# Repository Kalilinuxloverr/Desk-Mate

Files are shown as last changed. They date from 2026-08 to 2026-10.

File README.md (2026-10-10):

<p align="center">Desk-Mate Logo</p>

# Desk-Mate

Ein kleiner Wall-E-artiger Schreibtisch-Begleiter: eine Ampel für alles, was dich braucht (Claude Code, Browser-Downloads, Steam), ein Deck mit Motorfadern und Soft-Keys, ein Kopf mit zwei Augen-Displays. Verbunden per USB, BLE und WiFi; steuerbar vom Mac, vom Handy und über das Haus-MQTT. Alles Through-Hole, alles 3D-gedruckt, alles dokumentiert — inklusive Arbeitszeit.

**Zwischenstand (2026-10-09):**

| Schritt | Stand |
|---|---|
| Design-Spec (18 Grill-Fragen) | ✅ [`docs/superpowers/specs/`](docs/superpowers/specs/2026-08-22-desk-mate-design.md) |
| Pin-Map gegen Datenblatt + DevKit-Schaltplan verifiziert | ✅ [`firmware/arduino/deskmate/pins.h`](firmware/arduino/deskmate/pins.h) |
| Stückliste mit Quellen und Preisen, Teile bestellt (Amazon ~142 €) | ✅ [`hardware/bom.md`](hardware/bom.md) |
| KiCad final: Mainboard 100×100 · Frontpanel 120×136 · Augen-Adapter 42×30 — nur THT, Teile von Reichelt, Silkscreen mit Logo und Pin-Namen, ERC/DRC sauber, Gerber exportiert | ✅ [`hardware/kicad/`](hardware/kicad/README.md) |
| Bestellung Reichelt + JLCPCB | 🔜 bereit — Gerber in `hardware/kicad/<board>/fab/`, Liste in [`vault/Bestellungen/2026-10-09-reichelt.md`](vault/Bestellungen/2026-10-09-reichelt.md) |
| Firmware · Agent/App · Gehäuse | ⬜ danach |

Arbeitszeit und Tagesprotokolle: [`vault/Log/`](vault/Log/) · Projektseite: Portfolio-Eintrag P12.

```
 ┌─────────────────────┐
 │ KOPF  (pan/tilt)    │  Augen-Adapter-PCB → 2× GC9A01 (rund, 1,28")
 │                     │  WS2812-Ring (Ampel) · 2× MG90S im Hals
 ├─────────────────────┤
 │ BAUCH / DECK        │  FRONTPANEL-PCB
 │  [ 2,8" ILI9341 ]   │   6 Soft-Keys unter dem Display
 │  [k][k][k][k][k][k] │   4 Makro-Keys · EC11-Encoder
 │  |F| [k][k] (o) |F| │   2(4)× X32-Motorfader · MCP23017 · MPR121
 │  |F|  [k][k]    |F| │
 ├─────────────────────┤
 │ BASE (statisch)     │  MAINBOARD-PCB
 │  USB-C(D) USB-C(P)  │   ESP32-S3 DevKitC-1 · 2× USB-C · LD1117V33
 │  BME680             │   2(4)× DRV8833 · VM-Boost optional
 └─────────────────────┘
          │ USB / BLE / WiFi-MQTT
   ┌──────┴──────┐      ┌──────────┐      ┌────────────┐
   │ macOS-Agent │◄────►│ iOS-App  │      │ Claude Code│──Hooks──► Agent
   │ (Menüleiste)│ MQTT │          │      └────────────┘
   └─────────────┘      └──────────┘
```

| Pfad | Inhalt |
|---|---|
| `docs/superpowers/specs/` | Design-Spec (die eine Wahrheit für Hardware, Pin-Map, Protokolle) |
| `docs/superpowers/plans/` | Implementierungspläne je Phase |
| `docs/relic/` | Der Ursprungs-Prompt, unverändert |
| [`docs/anleitung/`](docs/anleitung/) | Bauanleitung (wächst mit dem Projekt) |
| `docs/logo/` | Logo (SVG) |
| `vault/` | Obsidian-Vault: Tagesblätter mit Arbeitszeit, Entscheidungen, Bestellungen |
| `hardware/kicad/` | Mainboard, Frontpanel, Augen-Adapter (KiCad 10) |
| `hardware/3d/` | Gehäuse (STEP + STL) |
| `hardware/bom.md` | Stückliste |
| `firmware/arduino/deskmate/` | ESP32-S3-Firmware (arduino-cli) |
| `app/` | macOS-Agent + iOS-App (Swift, XcodeGen) |
| `agent-windows/` | Windows-Tray (Python, Phase 2) |
| `server/` | Vercel-Function für Push |
| `tools/` | Session-Hooks, Secret-Check |

## Hardware

| Mainboard (Base) | Frontpanel (Deck) | Augen-Adapter |
|---|---|---|
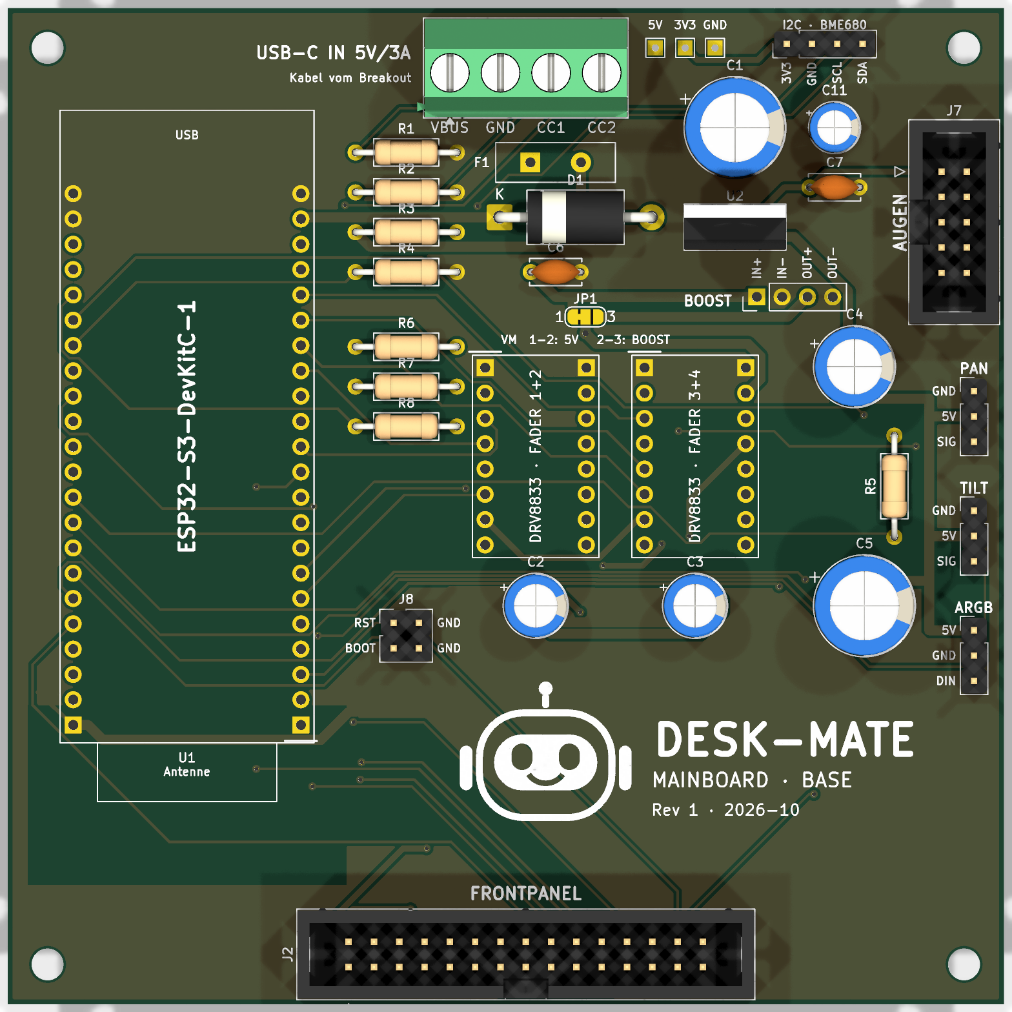
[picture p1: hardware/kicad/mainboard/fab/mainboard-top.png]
Mainboard
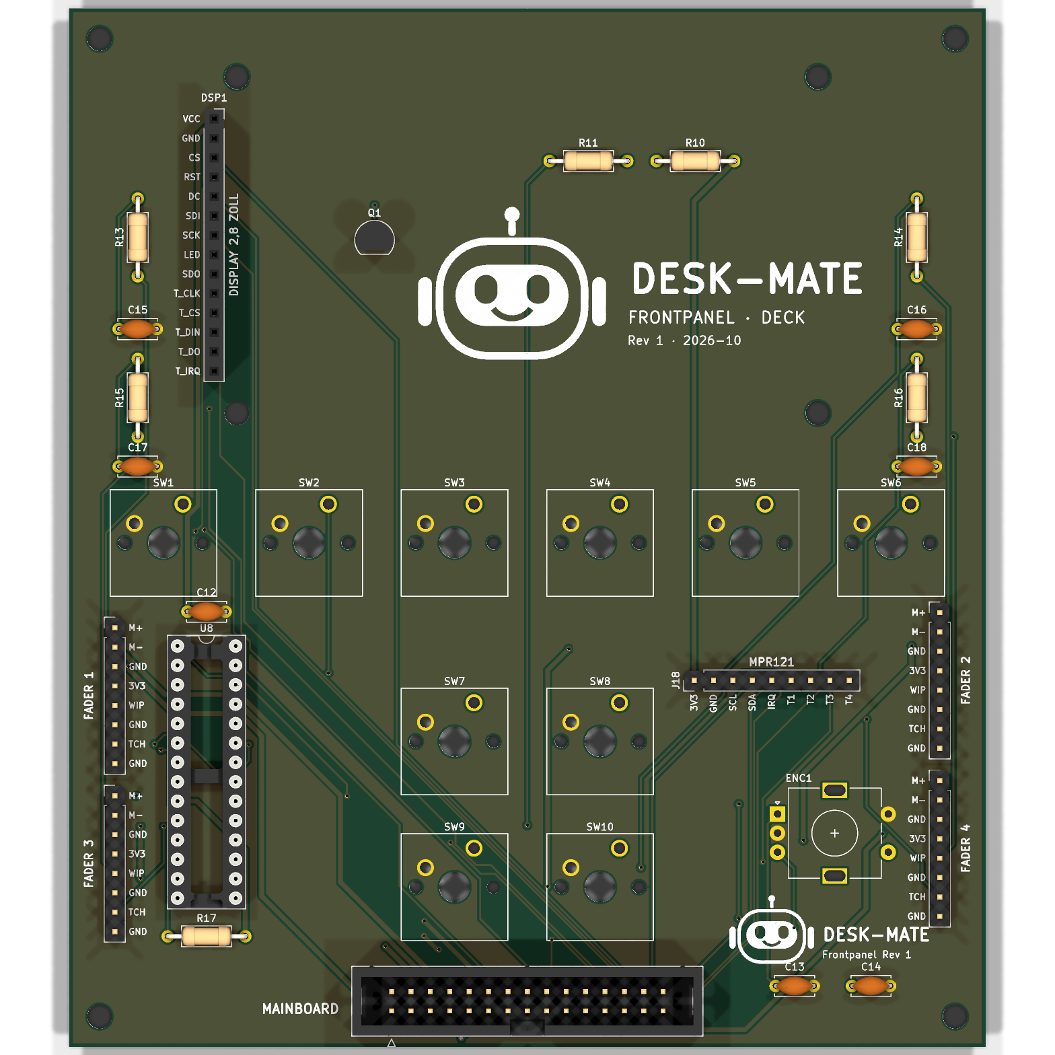
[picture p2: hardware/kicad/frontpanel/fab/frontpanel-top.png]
Frontpanel
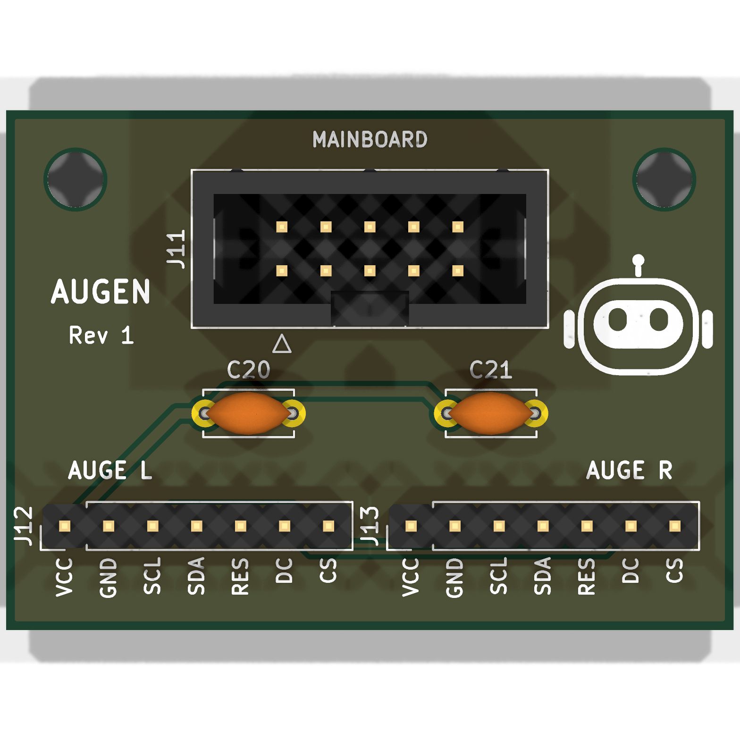
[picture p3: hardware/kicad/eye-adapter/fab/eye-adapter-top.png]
Augen-Adapter
|  |  |  |

Drei Through-Hole-Platinen, alle Module gesteckt (ESP32-S3-DevKitC-1, Pololu DRV8833, MPR121, Displays). Schaltpläne als PDF, STEP-Modelle und JLCPCB-Gerber-Zips liegen in `hardware/kicad/<board>/fab/`; Aufbau und Entwurfsregeln in [`hardware/kicad/README.md`](hardware/kicad/README.md), Bestellanleitung in [`docs/anleitung/01-platinen.md`](docs/anleitung/01-platinen.md).

## Bauen

Nach dem Klonen einmalig:

```bash
git config core.hooksPath tools/githooks   # Secret-Check vor jedem Commit
sh tools/test-check-secrets.sh             # muss "OK" sagen
sh tools/test-session-hooks.sh             # muss "OK" sagen
sh tools/test-pins.sh                      # Pin-Map-Regeln
sh tools/test-kicad.sh                     # ERC + DRC + Netzliste (braucht KiCad 10 unter /Applications)
```

KiCad-Dateien neu erzeugen/exportieren: siehe [`hardware/kicad/README.md`](hardware/kicad/README.md). Firmware- und App-Befehle kommen mit den jeweiligen Phasen dazu (siehe `CLAUDE.md`).

## Lizenz

MIT (Code). Lizenz für die Hardware-Dateien wird noch festgelegt.

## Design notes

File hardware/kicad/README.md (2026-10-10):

# KiCad — drei Platinen, eine JLCPCB-Bestellung

| Ordner | Platine | Maß | Inhalt |
|---|---|---|---|
| `mainboard/` | Base | 100 × 100 mm | S3-DevKit-Sockel, Schraubklemme für das USB-C-Breakout (5 V/3 A), Polyfuse + SB540, LD1117V33, 2× DRV8833-Sockel, Servo/ARGB/I²C-Stiftleisten, Augen-Kabel IDC 2×5, IDC 2×15, MT3608-Header (VM-Boost, optional) |
| `frontpanel/` | Deck | 120 × 136 mm | 10× MX, EC11, MCP23017, MPR121-Stiftleiste (Modul per Kabel), ILI9341-Sockel + 4 Abstandshalter, 4× Fader-Header, Backlight-Schalter, IDC 2×15 |
| `eye-adapter/` | Kopf | 42 × 30 mm | IDC 2×5 ein, 2× 1×7-Stiftleiste für die GC9A01 (per Dupont-Kabel) |
| `lib/` | — | — | Projektbibliothek `deskmate.kicad_sym` + `deskmate.pretty` (Modul-Sockel, Polyfuse) |
| `gen/` | — | — | Generator (siehe unten) |
| `<board>/fab/` | — | — | Gerber/Drill-Zip, STEP, Render — das geht zu JLCPCB |

Regeln (JLCPCB 2-Lagen): Leiterbahn ≥ 0,2 mm, Abstand ≥ 0,127 mm, Via 0,8/0,4 mm, Rand 0,3 mm. Netzklassen (Breite / Abstand 0,13): Default 0,25, Power 1,0 (Mainboard) bzw. 0,8 (Frontpanel), Motor 0,6, Power3V3 0,6 — Werte stehen in `gen/boards.py` und `gen/build_sch.py`. Massefläche beidseitig, Sperrzone unter der DevKit-Antenne.

## Generator statt Handarbeit (Erstversion)

Die Erstversion aller Dateien wurde aus `gen/boards.py` erzeugt — eine Tabelle „Bauteil → Pin → Netz → Position“. So sind Schaltplan, Layout und `netlist.json` per Konstruktion identisch, und `tools/test-kicad.sh` prüft das gegen KiCads eigene Netzliste.

```bash
cd hardware/kicad/gen
python3 build_sch.py                       # Bibliothek, Schaltpläne, Projekte, netlist.json
KIPY=/Applications/KiCad/KiCad.app/Contents/Frameworks/Python.framework/Versions/3.9/bin/python3
$KIPY build_pcb.py mainboard --force       # Layout platzieren, Freerouting, Zonen füllen
$KIPY export_fab.py mainboard              # Gerber/Drill/STEP/Render nach mainboard/fab/
sh ../../../tools/test-kicad.sh            # ERC + DRC + Netzlisten-Abgleich
```

`build_pcb.py` routet bis zu 6-mal mit wechselnder Strategie und behält den ersten Lauf mit 0 offenen Verbindungen; GND-Pads sind vollflächig an die Massefläche angebunden (beim Löten heißer/länger). Freerouting: `~/Applications/freerouting-2.3.0.jar` (Java 17+; `curl -L -o ~/Applications/freerouting-2.3.0.jar https://github.com/freerouting/freerouting/releases/download/v2.3.0/freerouting-2.3.0.jar`).

**Wichtig:** Sobald in der KiCad-GUI etwas geändert wurde, sind die `.kicad_sch`/`.kicad_pcb` die Wahrheit — `build_*.py` nicht mehr blind laufen lassen (`build_pcb.py` weigert sich ohne `--force`). Der Generator ist ein Bootstrap, kein Roundtrip.

Der Schaltplan ist „Label-Stil“: jedes Pin trägt ein globales Label, keine Leitungen. Elektrisch vollständig, optisch schlicht — in der GUI beliebig umsortierbar.

## Was vor der Bestellung am echten Teil zu prüfen ist

Siehe `vault/Hardware/Module-Masse.md` (Quellen + Konfidenz). Kurz: DevKit-Reihenabstand 22,86 (hoch), Pololu-Raster 10,16 (hoch), MPR121-Clone 17,78 (mittel — nachmessen), ILI9341 MSP2807-Löcher (hoch), X32-Fader-Pins (unbekannt — Drähte an Stiftleiste).

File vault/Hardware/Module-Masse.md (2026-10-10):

---
datum: 2026-08-27
typ: hardware
---
# Modul-Maße für die Sockel-Footprints (Recherche 27.08.2026)

Was der Generator (`hardware/kicad/gen/boards.py`) annimmt, woher es kommt, wie sicher es ist. **Alles mit „mittel/niedrig“ vor dem Löten am echten Teil nachmessen.**

| Modul | Maß im Footprint | Quelle | Konfidenz |
|---|---|---|---|
| ESP32-S3-DevKitC-1 v1.1 | Reihen 22,86 mm, 2×22, Pitch 2,54; PCB 62,74 × 25,40; letzter Pin 8,00 mm von der USB-Kante, erster Pin 1,40 mm von der Antennenkante; **Pin 1 beider Header am Antennenende** | Espressif DXF v1.1 (`dl.espressif.com/dl/schematics/esp_idf/DXF_ESP32-S3-DevKitC-1_V1.1_20220429.pdf`), Espressif KiCad-Footprint | hoch |
| DevKit Pinreihenfolge | J1: 3V3 3V3 RST 4 5 6 7 15 16 17 18 8 3 46 9 10 11 12 13 14 5V G · J3: G TX RX 1 2 42 41 40 39 38 37 36 35 0 45 48 47 21 20 19 G G | User Guide v1.1 (`…/user_guide_v1.1.html`, der „latest“-Link liefert 404) | hoch |
| Pololu DRV8833 #2130 | 12,7 × 20,3 mm, Reihen 10,16, Löcher Ø1,02; Draufsicht GND-Ende oben: links GND VMM BIN1 BIN2 AIN2 AIN1 nSLEEP nFAULT, rechts GND VIN BOUT1 BOUT2 AOUT2 AOUT1 AISEN BISEN | Pololu Maßzeichnung 0J1615, Pinout-Bild 0J3866 | hoch |
| Pololu A4988 (Sockel gestrichen 2026-10-04, nur noch Referenz) | 15,2 × 20,3 mm, Reihen 12,70; A: ENABLE MS1 MS2 MS3 RESET SLEEP STEP DIR, B: VMOT GND 2B 2A 1A 1B VDD GND | Pololu Maßzeichnung 0J1082 | hoch |
| ESP32-C3 SuperMini (Footprint gestrichen 2026-10-04, nur noch Referenz) | 22,5 × 18 mm, Reihen 15,24; links 5 6 7 8 9 10 20 21, rechts 5V GND 3V3 4 3 2 1 0 | ProtoSupplies, lastminuteengineers (Fotos, kein Datenblatt) | mittel |
| MPR121-Breakout (Clone; seit 2026-10-09 per Kabel an J18, Maße nur noch Referenz) | 20,3 × 30,5 mm, Reihen 17,78; Elektroden ELE0–11 auf einer Längskante, Steuerpins 3.3V IRQ SCL SDA ADD GND gegenüber ELE8…ELE3 | SparkFun Eagle-Daten (Clone = 1:1) | hoch (SparkFun) / mittel (Clone) |
| ILI9341 2,8" MSP2807 | PCB 50 × 86 × 1,6 mm; 4 Löcher Ø3,2 im Raster 44 × 76,08, 3 mm von den Längskanten; Header 14-pol. an der kurzen Kante, Reihe 2,0 mm vom Rand, Pin 1 8,49 mm von der Ecke; Header ragt 11,17 mm unter das PCB → **M3×11-Abstandshalter** | LCDWIKI MSP2807_Size.pdf | hoch |
| GC9A01 1,28" 7-pol. | VCC GND SCL SDA RES DC CS, Pitch 2,54; Modul ~38 × 45 mm; **keine Montagelöcher dokumentiert** | ProtoSupplies, cb-electronics | mittel |
| MT3608-Modul | 36 × 17 mm, Löcher **nicht** 2,54-kompatibel (Paar 6,45–6,8 mm, Ende-zu-Ende 30,5–31) → deshalb 4-Pin-Stiftleiste + Drähte statt Sockel | components101, Community-Footprints | niedrig |
| Behringer X32-Fader 100 mm | Poti-Körper mit 8 Lötpins (Muster 2-1-1-2 / 4-3-3-4), Motor separat 2 Pins, **kein Touch-Kontakt**, kein Kabel/Stecker → Drähte an die 8-Pin-Stiftleiste J14–J17; Touch = Draht an Metallhebel/Kappe | Arduino-Forum, EEVblog (Community) | niedrig — **charakterisieren, sobald geliefert** |
| GCT USB4085-GF-A (gestrichen 2026-10-09: nicht bei Reichelt, jetzt Breakout + Schraubklemme) | 16-Kontakt-USB-2.0-Buchse, **komplett THT** (keine 6-Pin-Power-Only-THT bei GCT), 5 A, Right-Angle; KiCad `Connector_USB:USB_C_Receptacle_GCT_USB4085` | GCT-Zeichnung usb4085.pdf | hoch |

Nicht gefunden: GC9A01-Montagelöcher, MT3608-Herstellerzeichnung, X32-Pinout.

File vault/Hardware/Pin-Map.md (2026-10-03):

# Pin-Map ESP32-S3 DevKitC-1 — verifiziert 2026-08-23

Code-Wahrheit: `firmware/arduino/deskmate/pins.h` (Test: `sh tools/test-pins.sh`). Spec §2.3 ist deckungsgleich.

## Quellen
- [DevKitC-1 v1.1 User Guide](https://docs.espressif.com/projects/esp-dev-kits/en/latest/esp32s3/esp32-s3-devkitc-1/user_guide_v1.1.html) + [Schaltplan V1.1](https://dl.espressif.com/dl/schematics/SCH_ESP32-S3-DevKitC-1_V1.1_20221130.pdf)
- [ESP32-S3-WROOM-1 Datenblatt](https://documentation.espressif.com/esp32-s3-wroom-1_wroom-1u_datasheet_en.pdf) · [ESP32-S3 Datenblatt](https://www.espressif.com/documentation/esp32-s3_datasheet_en.pdf)
- [ESP-IDF ADC-Doku](https://docs.espressif.com/projects/esp-idf/en/latest/esp32s3/api-reference/peripherals/adc/adc_oneshot.html) · [LEDC-Doku](https://docs.espressif.com/projects/esp-idf/en/latest/esp32s3/api-reference/peripherals/ledc.html)

## Verifiziert
- **Alle geplanten GPIOs liegen am Header** (J1 + J3), inkl. 19/20 (USB D−/D+) und 43/44 (UART0 → CP2102N-A02-GQFN28).
- **Onboard-RGB-LED:** v1.0 = GPIO 48, v1.1 = GPIO 38 (0-Ω-Widerstand R17). Keine offizielle äußere Erkennung — beim ersten Boot ausprobieren. v1.1: LED spiegelt unser Pixel 0 (gewollt). v1.0: LED hängt am PSU_SENSE-Knoten (GPIO 48) — Digital-Read bleibt gültig, Teiler 10k/10k ist niederohmig genug.
- **Octal-PSRAM (N16R8):** GPIO 35/36/37 intern belegt → am Sockel **unverbunden lassen** (liegen am Header!).
- **Strapping:** 0 (Pull-up, Boot), 3 (JTAG-Sel, per eFuse-Default ignoriert), 45 (VDD_SPI: **nie high beim Boot** — seit 2026-10-04 komplett unbelegt, `tools/test-pins.sh` blockt ihn), 46 (Pull-down, danach frei). **48 ist kein Strapping-Pin.** Latch-Zeit ≥ 3 ms nach Reset.
- **ADC:** ADC1_CH0–9 = GPIO 1–10, ADC2 = 11–20 (mit WiFi unbrauchbar). Schleifer auf 1/2/4/5 ✓.
- **LEDC:** 8 Kanäle, 4 Timer, nur Low-Speed. Belegt: 4 Motor + 2 Servo + 1 BL = 7.
- **JTAG 39–42:** frei, solange USB-Serial-JTAG (eFuse-Default) genutzt wird.

## Flags für Bauteilwahl / Firmware
1. **MF60T-Motor:** Behringer nennt keine Motorspannung; Soundwell-60-mm-Referenz sagt **6–10 V** ([soundwell.hk](https://www.soundwell.hk/soundwell-60mm-motorized-slide-potentiometer.html), mittlere Konfidenz). FaderBuddy fährt ihn mit 5 V (funktioniert, langsamer). → Mainboard bekommt **VM-Lötjumper: 5 V (Default) oder unbestückter Boost-Sockel (MT3608-Breakout, 2×4-Pin) auf ~9 V**. Motor vor dem Layout am Netzteil charakterisieren (Anlauf, Stall bei 5 V).
2. **DRV8833-Breakout:** Pololu #2130 ist 16-polig (VIN/VMM getrennt, AISEN/BISEN nach GND, nSLEEP high). Bei Noname-Breakouts prüfen, ob nSLEEP hochgezogen ist. Footprint erst nach Kauf final.
3. **Fader-Track 10 kΩ linear** ✓ (Behringer-Produktseite) — RC 1 kΩ/100 nF passt.
4. **LED-Ausgang ist generisch:** 3-Pin-Buchse 5V/GND/Data für jeden WS2812/ARGB-Streifen (Leon hat einen aus einer Drohnen-Bestellung). Anzahl LEDs = NVS-Konfig, Strom-Cap in Firmware.

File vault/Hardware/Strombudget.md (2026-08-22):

# Strombudget 5 V

Siehe Spec §2.5. Kurzfassung: typ. ~1,3 A, Spitze theoretisch ~3,7 A, real ~2,5 A (Motoren und Servos nie gleichzeitig mit vollem Duty). Netzteil 5 V/3 A, Polyfuse 3 A, Bulk 1000 µF, 100 µF je DRV8833, 470 µF an den Servos. Ohne Netzteil (`PSU_SENSE` low) gedrosselt.

Bei 4 Fadern neu rechnen.

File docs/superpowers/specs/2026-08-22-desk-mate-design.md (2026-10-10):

# Desk-Mate — Design-Spec

**Datum:** 2026-08-22 · **Status:** von Leon im Chat abgenommen (Abschnitte 1–5), 18 Grill-Fragen beantwortet; Reserve gestrichen 2026-10-04 (§2.2, [`vault/Entscheidungen/2026-10-04-reserve-raus.md`](../../../vault/Entscheidungen/2026-10-04-reserve-raus.md)); **finalisiert 2026-10-09** — Platinenteile von Reichelt, Silkscreen ([`vault/Entscheidungen/2026-10-09-finalisierung.md`](../../../vault/Entscheidungen/2026-10-09-finalisierung.md)) · **Relikt:** [`docs/relic/2026-08-22-original-prompt.md`](../../relic/2026-08-22-original-prompt.md)

Desk-Mate ist ein kleiner Wall-E-artiger Schreibtisch-Begleiter: eine Ampel für alles, was dich braucht (Claude Code, Downloads, Steam), ein Deck mit Motorfadern und Soft-Keys, ein Kopf mit zwei Augen-Displays — verbunden per USB, BLE und WiFi, steuerbar von Mac, Handy und Haus-MQTT.

Leitplanken aus dem Grilling: **eine PCB-Bestellung** (drei Designs, kein Re-Spin), **kein Hand-SMD** (Through-Hole + gesteckte Breakouts), **ein ESP32-S3**, **alles in v1**, **Dokumentation und Arbeitszeit ab Commit 1**.

---

## 1 · Entscheidungen (Kurzfassung)

| # | Frage | Entscheidung |
|---|---|---|
| 1 | v1-Umfang | Alles (A–E); Reihenfolge Plan → KiCad → Teile → JLCPCB → Rest |
| 2 | Mechanik | Base statisch, **kein Körper-Stepper**; Treiber-Sockel gestrichen (2026-10-04) |
| 3 | Hirn | **Ein ESP32-S3 DevKitC-1 N16R8** (N8R8 gleichwertig), gesteckt; kein C3 (Footprint gestrichen 2026-10-04) |
| 5 | Zentrale | Hybrid: USB → Desktop-Agent primär, BLE → Handy, Gerät auch standalone |
| 6 | Standalone | BLE-HID + Gesicht + **WiFi in v1** (MQTT, NTP, OTA, Wetter, Haus-Nodes) |
| 7 | Fader-Regelung | Eigene, einfache Regelung auf dem S3; DRV8833-Breakouts gesteckt. Fader: **Behringer X32-Ersatz, 100 mm, panel-mounted mit Kabel** (entschieden 2026-08-23) |
| 8 | Fader-Anzahl | 2 verbaut, 4 vorgesehen (5er-Set: +1 Ersatz) |
| 9 | Displays | 2× rund 1,28" GC9A01 (Augen) + 2,8" ILI9341 (Bauch), ein SPI-Bus |
| 10 | Tasten | 6 Soft-Keys + 4 Makro-Keys (MX, Hot-Swap) + EC11-Encoder; SmartKnob: Roadmap |
| 11 | Strom | 2× USB-C außen (Daten-Verlängerung / 5 V 3 A über USB-C-Breakout an Schraubklemme, 2026-10-09); Mainboard: Polyfuse + Schottky, DevKit-Diode als zweiter Zweig |
| 12 | Kopf | 2× MG90S Pan/Tilt, Easing, PWM-Aus im Ruhezustand |
| 13 | Claude | Claude-Code-**Hooks** (Status + Freigabe), Tastendruck nur als Fallback; generische Ereignisquellen |
| 14 | Agent | Swift-Menüleisten-App im Xcode-Projekt der iOS-App; Windows-Tray in Python (Phase 2); S3 = Composite-HID |
| 15 | Fernzugriff | MQTT (HiveMQ) + minimaler Server nur für APNs-Push (Vercel + Supabase) |
| 16 | Doku | Obsidian-Vault im Repo (`vault/`), Arbeitszeit per Session-Hooks |
| 17 | Git | SessionEnd-Hook commit + push, öffentlich ab Commit 1, Secret-Grep |
| 18 | Platinen | **Mainboard + Frontpanel + Augen-Adapter**, 2×15-IDC dazwischen |

Frage 4 (UART vs. ESP-NOW) entfiel mit dem C3. Jede Entscheidung hat eine Notiz in `vault/Entscheidungen/`.

---

## 2 · Hardware

### 2.1 Aufbau

```
 ┌─────────────────────┐
 │ KOPF  (pan/tilt)    │  Augen-Adapter-PCB → 2× GC9A01
 │                     │  WS2812-Ring (Ampel) · 2× MG90S im Hals
 ├─────────────────────┤
 │ BAUCH / DECK        │  FRONTPANEL-PCB
 │  [ 2,8" ILI9341 ]   │   6 Soft-Keys unter dem Display
 │  [k][k][k][k][k][k] │   4 Makro-Keys · EC11
 │  |F| [k][k] (o) |F| │   2(4)× X32-Fader · MCP23017 · MPR121
 │  |F|  [k][k]    |F| │
 ├─────────────────────┤
 │ BASE (statisch)     │  MAINBOARD-PCB
 │  USB-C(D) USB-C(P)  │   S3 DevKitC-1 · Polyfuse + SB540 · LD1117V33
 │  BME680 hinter      │   2(4)× DRV8833 · VM-Boost optional
 │  Lüftungsschlitzen  │
 └─────────────────────┘
```

**Design-Richtung (Referenzbild `docs/design/2026-08-23-referenz-roboter.png`, Leon 2026-08-23):** weißes, rundes Gehäuse; der Kopf trägt **ein durchgehendes dunkles Visier**, hinter dem beide Augen-Displays leuchten (EVE-/Chatbot-Look, kein kantiger Wall-E); der **Mund ist die WS2812-Leiste hinter dem Visier** — im Ruhezustand türkises Lächeln, als Ampel grün/gelb/rot. Das Bedienpanel (Frontpanel) sitzt vorne **angewinkelt** (Arbeitsannahme 20°, wird am Druckteil geprüft). Stummelärmchen als feste Druckteile (keine Aktorik). Genaue Anordnung der Tasten/Fader wird beim Frontpanel-Layout mit Leon abgestimmt.

### 2.2 Platinen (drei Designs, eine JLCPCB-Bestellung)

**Mainboard (Base)** — 2 Lagen, **100 × 100 mm** (KiCad 2026-08-27; Rückwand = obere Kante: USB-C-Netzteilbuchse, BME680-Sockel, Testpunkte; DevKit links mit USB-Ende zur Rückwand, Antenne nach vorn über einer Kupfer-Sperrzone; IDC an der Vorderkante)
- Sockel für ESP32-S3-DevKitC-1 (2× 1×22 Buchsenleiste, 2,54 mm; Antennenseite über Platinenrand hinaus, nichts darüber)
- **Daten-Port** = Panel-Mount-USB-C-Verlängerung von der DevKit-USB-Buchse zur Gehäuserückwand (entschieden 2026-08-23: kein USB-Routing/ESD auf dem Mainboard, DevKit direkt flashbar). Strom kommt über **J1 = 4-polige Schraubklemme RM 5,08** (VBUS, GND, CC1, CC2) von einem USB-C-Breakout in der Rückwand; CC1/CC2 bekommen auf dem Mainboard je 5,1 kΩ nach GND → 3 A vom Netzteil (2026-10-09: Reichelt hat keine THT-USB-C-Buchse, die 0,85-mm-Buchse samt Handrouting entfällt). Außen am Gehäuse bleiben zwei USB-C-Ports (Entscheidung 11)
- Versorgung (entschieden 2026-08-23, ersetzt P-FET-ODER): J1 (VBUS) → Polyfuse 3 A → **Schottky SB540** → 5-V-Rail; USB-Pfad speist die Rail über die **DevKit-eigene Diode** am 5V-Pin (Standard-Praxis, sperrt Rückspeisung zum Host). PSU_SENSE-Teiler **10 k/15 k** (→ 3,0 V bei 5 V; 10 k/10 k lägen mit 2,5 V zu nah an VIH) greift **vor** der SB540 ab → eindeutig „Netzteil da“. Rail liegt real bei ~4,6–4,7 V (Diodenabfall) — für Logik/Displays egal, für Fader-Motoren siehe VM-Boost-Sockel. Bulk 1000 µF/10 V an der Rail, LD1117V33 (TO-220) für 3,3-V-Peripherie (Displays, MCP23017, MPR121, BME680); DevKit-LDO versorgt nur den S3
- 2× Sockel für DRV8833-Breakout (Pololu #2130, 16-polig, Raster 10,16 mm) = 4 Motorkanäle; je 100 µF am VM-Pin; **VM-Rail per Lötjumper JP1 (der einzige auf dem Board): 5 V (Default) oder MT3608-Boost auf ~9 V** — das MT3608-Modul hat kein 2,54-Raster, deshalb 4-Pin-Stiftleiste U5 (VIN+ VIN− VOUT+ VOUT−) und Drähte statt Sockel (2026-08-27); nSLEEP beider Treiber fest an 3V3 (Jumper gestrichen 2026-10-04) — MF60T-Motor ist lt. Soundwell für 6–10 V spezifiziert, läuft bei 5 V nur langsamer (FaderBuddy-Praxis)
- 2× Servo-Anschluss als 1×3-Stiftleiste (GND/5V/Signal, der Servostecker passt direkt), 470 µF direkt daneben; der 10-Ω-Serienwiderstand ist gestrichen (2026-08-27: bei 0,7 A Stall fielen 7 V ab — Drosselung macht die Firmware über PSU_SENSE)
- WS2812/ARGB-Anschluss als 1×3-Stiftleiste (5 V, GND, Data über 330 Ω), 1000 µF lokal — generisch: beliebiger 5-V-ARGB-Streifen/Ring (Leons Drohnen-Streifen), LED-Anzahl per NVS, Strom-Cap in Firmware
- BME680 per Kabel an eine 1×4-I²C-Stiftleiste J6 (3V3 GND SCL SDA, 2026-10-09) — Sensor sitzt hinter den Lüftungsschlitzen, weg von der ESP-Wärme; kein Sockel mit ungeprüfter Pinfolge
- I²C-Pull-ups 4,7 kΩ und IO_INT-Pull-up 10 kΩ sitzen auf dem Mainboard (2026-08-27: damit der Interrupt-Eingang auch ohne gestecktes Frontpanel definiert ist)
- IDC 2×15 zum Frontpanel (Pinbelegung 2.4); DISP_RST vom Frontpanel läuft über Pin 29 durch zum Augen-Kabel
- **Augen-Kabel J7 = IDC 2×5** (verpolsicher, 10 Adern vom selben Flachband; 2026-10-09): 1 3V3 · 2 GND · 3 SCK · 4 GND · 5 MOSI · 6 GND · 7 DC · 8 CS_L · 9 CS_R · 10 DISP_RST — GND liegt zwischen SCK und MOSI
- Augen-/Servo-/WS2812-Kabel gehen vom Mainboard nach oben (Kopf ist am Bauch, Kabel durch Bauch-Rückwand)
- **Keine Reserve-Footprints** (2026-10-04): Stepper-Sockel und C3-Footprint sind gestrichen, GPIO 43/44 bleiben als Debug-UART frei, der einzige Lötjumper ist JP1 (VM). Begründung: `vault/Entscheidungen/2026-10-04-reserve-raus.md`
- Taster RESET und BOOT per Kabel/Pins nach außen führbar (DevKit-Taster liegen unter dem Gehäuse)

**Frontpanel (Deck)** — 2 Lagen, **120 × 136 mm** (KiCad 2026-08-27): ILI9341-Modul quer oben (x 17–103, y 6–56, Header links, 4× M3×11-Abstandshalter im MSP2807-Raster 76,08 × 44), darunter 6 Soft-Keys im 19,05-Raster, 4 Makro-Keys 2×2 mittig, Encoder rechts, MCP23017 links, MPR121-Stiftleiste rechts, Fader-Header an den Seitenkanten, IDC an der Unterkante; die Fader sitzen links/rechts **neben** dem PCB im Panel. Anordnung von Leon freigegeben 2026-10-09
- Fader: **Behringer X32-Ersatzfader, 100 mm, 5er-Set** (entschieden 2026-08-23, ersetzt MF60T 60 mm) — Metallrahmen wird ans Gehäuse-Panel geschraubt, Anschluss über die mitgelieferten Kabel auf 4× Header am PCB (Motor 2-polig, Poti/Touch mehradrig — Pinout bei Charakterisierung). Kein Fader-Footprint mehr → größtes Footprint-Risiko eliminiert. Deck wird durch den 100-mm-Fahrweg ~4–5 cm höher als mit 60ern
- 10× MX-kompatibler Schalter-Footprint (**THT, direkt gelötet** — Hot-Swap-Sockel gestrichen 2026-08-24: sind SMD), keine Dioden (kein Matrix-Scan, direkt am Expander)
- EC11-Encoder mit Taster
- MCP23017 (DIP-28) — Tasten 0–9, Encoder A/B/SW, Display-RST, Display-BL (on/off); INT_A/B → IDC
- MPR121-Breakout **per Kabel** an die 1×9-Stiftleiste J18 (3V3 GND SCL SDA IRQ T1–T4; 2026-10-09: kein Sockel, weil die Clone-Raster nicht belegt sind — Falle 15) — Fader-Touch 0–3 (Kanal 4–11 frei, z. B. Touch am Kopf)
- Steckleiste für das 2,8"-ILI9341-Modul (14-Pin-Variante; SPI, ohne Touch-Pins), Display sitzt über den Soft-Keys. **Backlight-Schalter einstufig** (2026-10-04): MCP23017 GPB6 → 1 kΩ → Basis BC327 (high-side an 3V3) → LED-Pin; 10 kΩ Basis–Emitter hält das Licht aus, bis die Firmware den MCP konfiguriert; GPB6 low = an. Kein GPIO45, kein Jumper
- MCP23017 RESET fest an 3V3, A0–A2 an GND (0x20), INTA direkt an IO_INT, INTB unbeschaltet; Firmware setzt MIRROR=1, INT open-drain. DISP_RST (GPB5) hat 10 kΩ Pull-up und geht an das Bauch-Display und über IDC-Pin 29 zu den Augen
- 4× Fader-Anschluss-Header (Motor + Schleifer + Touch), RC-Filter (1 kΩ / 100 nF) je Schleifer vor dem IDC
- IDC 2×15 zum Mainboard

**Augen-Adapter (Kopf)** — 2 Lagen, 42 × 30 mm, nur Stecker
- IDC 2×5 als Eingang (Belegung wie J7 auf dem Mainboard)
- 2× 1×7-Stiftleiste in GC9A01-Reihenfolge (VCC GND SCL SDA RES DC CS), 100 nF je Modul; die Displays hängen an 7-poligen Dupont-Kabeln, ihren Abstand bestimmt das Visier (2026-10-09: vorher Buchsen 20 mm auseinander, die 38-mm-Module hätten sich überlappt)
- **Reset gemeinsam mit dem Bauch-Display** (2026-10-04, ersetzt das RC-Glied): DISP_RST kommt vom MCP23017 (GPB5, Pull-up auf dem Frontpanel) über IDC-Pin 29 und Pin 10 des Augen-Kabels. Ein Reset-Pfad für alle drei Panels, kein `pin_rst = -1`-Sonderfall
- nur Stecker + 2× 100 nF → kann keine Revision kosten

**Alle drei Platinen (2026-10-09):** Jedes gelötete Teil gibt es bei Reichelt (Art.-Nr. in `hardware/bom.md`), Module kommen von Amazon oder aus dem Bestand. Kein SMD. Silkscreen vorne: Desk-Mate-Kopf (Augen und Lächeln als Aussparung im Visier), Platinenname, Rev 1 und an jedem Stecker die Pin-Namen; hinten großer Kopf, GitHub-Link und das Feld `JLCJLCJLCJLC` für die JLCPCB-Bestellnummer. Erzeugt aus `hardware/kicad/gen/boards.py` (`'silk'`).

### 2.3 Pin-Map ESP32-S3 DevKitC-1 (N16R8)

Regeln: Schleifer nur auf **ADC1 (GPIO 1–10)** (ADC2 ist mit WiFi tot) · keine Strapping-Pins (0, 3, 45, 46) für Funktionen · 19/20 = USB · 26–37 = Flash/Octal-PSRAM (nicht nutzen) · 43/44 = UART0 zum CP2102 (Debug, frei lassen) · 38/48 = je nach DevKit-Revision die Onboard-RGB-LED.

Motoren laufen im **PWM + DIR**-Schema am DRV8833 (IN1 = PWM, IN2 = DIR; rückwärts mit invertiertem Duty = Drive/Brake). So braucht jeder Motor **einen** LEDC-Kanal; der S3 hat 8 LEDC-Kanäle → 4 Motoren + 2 Servos = 6.

| GPIO | Funktion | Bus | Ziel | Hinweis |
|---|---|---|---|---|
| 1 | FADER1_WIPER | ADC1_CH0 | Frontpanel | RC-Filter |
| 2 | FADER2_WIPER | ADC1_CH1 | Frontpanel | |
| 4 | FADER3_WIPER | ADC1_CH3 | Frontpanel | Reserve |
| 5 | FADER4_WIPER | ADC1_CH4 | Frontpanel | Reserve |
| 6 | FADER1_PWM | LEDC | DRV8833 A-IN1 | 20 kHz (unhörbar) |
| 7 | FADER1_DIR | GPIO | DRV8833 A-IN2 | |
| 8 | FADER2_PWM | LEDC | DRV8833 B-IN1 | |
| 9 | FADER2_DIR | GPIO | DRV8833 B-IN2 | |
| 10 | FADER3_PWM | LEDC | DRV8833 #2 | Reserve |
| 11 | FADER3_DIR | GPIO | DRV8833 #2 | Reserve |
| 12 | FADER4_PWM | LEDC | DRV8833 #2 | Reserve |
| 13 | FADER4_DIR | GPIO | DRV8833 #2 | Reserve |
| 14 | SERVO_PAN | LEDC 50 Hz | Kopf | |
| 15 | SERVO_TILT | LEDC 50 Hz | Kopf | |
| 16 | SPI_MOSI | SPI2 | alle Displays | 40 MHz-fähig |
| 17 | I2C_SDA | I²C | MCP23017, MPR121, BME680 | 4,7 kΩ Pull-up auf 3V3 |
| 18 | I2C_SCL | I²C | dito | |
| 21 | IO_INT | GPIO in | MCP23017 INT (+ MPR121 IRQ, wired-OR) | Open-Drain, Pull-up |
| 38 | WS2812_DATA | RMT | Ampel-Ring | auf DevKit v1.1 spiegelt die Onboard-LED Pixel 0 — gewollt |
| 39 | SPI_SCK | SPI2 | alle Displays | JTAG-Default, frei wenn USB-JTAG |
| 40 | SPI_DC | GPIO | alle Displays | geteilt |
| 41 | CS_BELLY | GPIO | ILI9341 | |
| 42 | CS_EYE_L | GPIO | GC9A01 links | |
| 47 | CS_EYE_R | GPIO | GC9A01 rechts | |
| 48 | PSU_SENSE | GPIO in | Spannungsteiler an J1-VBUS (vor der SB540) | „Netzteil da?“ (Onboard-LED auf DevKit v1.0 hängt hier — unkritisch) |
| 0, 3, 45, 46 | — | | | Strapping, nicht belegen. 45 (VDD_SPI) war bis 2026-10-04 als Backlight-PWM-Option über Lötjumper vorgesehen, jetzt unbelegt |
| 19, 20 | USB D−/D+ | USB | J_DATA | über DevKit-USB-Buchse oder direkt; Entscheidung bei Bauteilwahl |
| 43, 44 | UART0 | | CP2102 | Debug/Flash-Fallback |

Über den MCP23017 (Frontpanel): GPA0–GPA5 Soft-Keys 1–6 · GPA6–GPA7 + GPB0–GPB1 Makro-Keys 1–4 · GPB2 ENC_A · GPB3 ENC_B · GPB4 ENC_SW · GPB5 DISP_RST (alle Displays) · GPB6 BELLY_BL_EN · GPB7 frei. Encoder über INT-on-change ist für Handdrehung ausreichend (< 100 Flanken/s).

**Verifiziert 2026-08-23** gegen Datenblätter und DevKitC-1-Schaltplan — Details und Quellen: `vault/Hardware/Pin-Map.md`. GPIO 35–37 liegen am Header, bleiben aber unverbunden (Octal-PSRAM).

### 2.4 IDC 2×15 Mainboard ↔ Frontpanel

| Pin | Signal | Pin | Signal |
|---|---|---|---|
| 1 | 5V | 2 | 5V |
| 3 | GND | 4 | GND |
| 5 | 3V3 | 6 | 3V3 |
| 7 | MOT1+ | 8 | MOT1− |
| 9 | MOT2+ | 10 | MOT2− |
| 11 | MOT3+ | 12 | MOT3− |
| 13 | MOT4+ | 14 | MOT4− |
| 15 | GND | 16 | GND |
| 17 | WIPER1 | 18 | WIPER2 |
| 19 | WIPER3 | 20 | WIPER4 |
| 21 | GND | 22 | I2C_SDA |
| 23 | I2C_SCL | 24 | IO_INT |
| 25 | SPI_MOSI | 26 | SPI_SCK |
| 27 | SPI_DC | 28 | CS_BELLY |
| 29 | DISP_RST | 30 | GND |

Motorleitungen liegen zwischen GND-Paaren (Störungen), Schleifer ebenfalls. DRV8833 bleiben auf dem Mainboard (kurzer Strompfad zum Bulk-Elko); 0,2–0,6 A pro Motor über 28-AWG-Flachband ist im Rahmen (≤ 1 A/Ader).

### 2.5 Strombudget (5 V)

| Verbraucher | typ. | Spitze | Anmerkung |
|---|---|---|---|
| ESP32-S3 DevKit (WiFi + BLE) | 0,25 A | 0,5 A | |
| 2× X32-100-mm-Fader-Motor | 0,3 A | 1,2 A | Annahme MF60T-Klasse; bei Charakterisierung messen |
| 2× MG90S | 0,3 A | 1,4 A | Stall 0,7 A je; PWM aus im Ruhezustand |
| ILI9341 2,8" (Backlight) | 0,15 A | 0,15 A | |
| 2× GC9A01 | 0,08 A | 0,08 A | |
| WS2812 × 12 | 0,2 A | 0,72 A | Firmware-Cap 50 % → 0,36 A |
| Rest (Expander, Sensoren) | 0,02 A | 0,02 A | |
| **Summe** | **~1,3 A** | **~3,7 A theor. / ~2,5 A real** | Motoren und Servos werden nicht gleichzeitig mit vollem Duty gefahren (Firmware-Regel) |

→ 5 V/3 A Netzteil, Polyfuse 3 A, Bulk 1000 µF + je 100 µF an Motortreibern + 470 µF an Servos. Bei 4 Fadern: Budget erneut rechnen; ggf. 5 V/4 A.
→ Ohne Netzteil (nur J_DATA am Rechner): `PSU_SENSE` low → Firmware fährt Motoren/Servos gedrosselt (Duty ≤ 40 %, nie gleichzeitig) oder gar nicht („Netzteil-Modus“ konfigurierbar).

### 2.6 Gehäuse (3D-Druck)

- Stil nach Referenzbild (§2.1): weiße Schalen, Kopf mit dunklem Visier (getönt gedrucktes/Acryl-Fenster) über beiden Augen und der WS2812-Mund-Leiste; Frontpanel um ~20° angewinkelt
- Drei Baugruppen: Base (Mainboard, USB-Buchsen hinten, Lüftungsschlitze für BME680, Gummifüße), Bauch (Frontpanel angewinkelt, Display-Fenster, Tastenausschnitte, Fader-Schlitze, Stummelärmchen fest), Kopf (Visier, Augen, Pan-Tilt-Halter für MG90S — Standard-Halter, STL frei verfügbar)
- Kabelführung: ein Strang Base → Bauch (IDC), ein Strang Bauch → Kopf (Augen 10 Adern + WS2812 3 Adern); Servos sitzen im Bauch/Hals, nicht im Kopf
- Alle Teile als STEP + STL, je Teil eine Datei, deutsche Dateinamen wie beim Kühler (`Kopf_Schale_vorne.stl`); Druckparameter in `hardware/3d/README.md`
- Fader-Kappen: X32-Kappen sind dabei; Touch über Draht/Federkontakt an die Metallachse (MPR121)
- Deck-Höhe: 100-mm-Fader (~13 cm Körper) bestimmen das Panel — Winkel ~20°, Fader längs im Panel

### 2.7 Bauteile, die Leon schon hat

BME680-Breakout, WS2812-Breakout, C3 SuperMinis, CYD, „Arduino-Box“ (Inventur nach dem Urlaub, Ende August 2026). Die Bauteilwahl (Plan-Task) gleicht die BOM gegen diese Inventur ab, bevor bestellt wird.

---

## 3 · Firmware (ESP32-S3, arduino-cli, ein Sketch)

`firmware/arduino/deskmate/` mit `project.json` (arduino-cli-Workflow, Core-Version gepinnt), FQBN `esp32:esp32:esp32s3` mit USB-Modus für natives USB (HID + CDC), `PartitionScheme` mit OTA + großem App-Slot, PSRAM `opi`.

**Module (je eine `.cpp/.h`, kein Framework):**

| Modul | Aufgabe | Bibliothek |
|---|---|---|
| `hid` | Composite-USB-HID: Tastatur + Consumer (Lautstärke/Media) + Gamepad (Fader = Achsen); dieselben Reports über BLE-HID | ESP32-Arduino `USBHIDKeyboard/USBHIDConsumerControl/USBHIDGamepad`, NimBLE-HID |
| `link` | Serielles JSON-Zeilenprotokoll zum Agent über USB-CDC (parallel zu HID), versioniert (`{"v":1,...}`), fester Puffer 512 B, Zeile zu lang → verwerfen + Fehlerzähler (VVVF-Lektion) | ArduinoJson |
| `net` | WiFi-STA, NTP, MQTT (HiveMQ TLS, `deskmate/#`), OTA (ArduinoOTA oder HTTP-Update), Wetter (Topic der Wetterstation + optional Open-Meteo) | WiFiClientSecure, PubSubClient |
| `face` | Augen (2× GC9A01): Blinzeln, Blickrichtung, Emotionen; Bauch: Seiten *Gesicht / Claude / Downloads / Wetter / Haus / Einstellungen*; Soft-Key-Labels; Encoder-Navigation | LovyanGFX (ein Bus, drei Panels) |
| `motion` | Fader-P-Regler mit Totband + Touch-Stopp + Rasten/Endanschlag-Haptik (FaderBuddy-Verhalten); Servo-Easing, PWM-Aus nach Stillstand | ESP32Servo oder LEDC direkt |
| `io` | MCP23017 (Tasten, Encoder, RST/BL), MPR121 (Touch), BME680 | Adafruit MCP23X17, Adafruit MPR121, Adafruit BME680 |
| `state` | Eine Ampel-Zustandsmaschine: `idle` (grün) / `busy` (gelb) / `needs_you` (rot) / `needs_you_urgent` (rot blinkend) mit Quelle und Text; Ereignisse aus `link`, `net`, lokalen Tasten | — |
| `config` | NVS: Tastenbelegung (HID-Keycodes/Makros), Fader-Layer, WiFi/MQTT-Credentials (nie im Code, `secrets.h` gitignored) | Preferences |

**Pflichtregeln (aus dem Kühler-Fallen-Log):** NimBLE statt Bluedroid · `WiFi.setSleep(false)` · kein großes Vollbild-Sprite, Panels direkt zeichnen (PSRAM erlaubt Sprites, aber erst messen) · Watchdog aktiv · keine Structs/Default-Args in `.ino`-Signaturen (alle Logik in `.cpp`) · jede Protokolländerung = Versionsnummer hoch + Parser-Test.

**Test:** `firmware/arduino/deskmate/test/` mit einem Host-kompilierbaren Test für das Zeilenprotokoll und die Zustandsmaschine (plain C++, `assert`, kein Framework). Build-Befehl steht in CLAUDE.md und ist vor jedem „fertig“ auszuführen.

---

## 4 · Agent und Apps (Swift, ein Xcode-Projekt via XcodeGen)

```
app/
  project.yml
  DeskMateCore/        Swift Package: Modelle, Protokoll (Serial-JSON, MQTT-Topics), Einstellungen, Ereignisse
  DeskMateMac/         Menüleisten-App (SwiftUI, AppKit-Statusitem)
  DeskMateiOS/         iPhone-App (SwiftUI); später Widgets/Live Activity, Watch
  Tests/
```

**macOS-Agent** (Menüleiste, läuft beim Login):
- `SerialLink`: findet Desk-Mate über USB-CDC (Vendor/Product-ID des S3, Gerätename), Reconnect
- `EventHub`: lokaler HTTP-Server auf `127.0.0.1:4821` — `POST /event {source, state, text, ttl}` (Claude-Hooks, Skripte), `POST /await-ack` (blockierend bis Taste, mit Timeout), `GET /state`
- `Watchers`: `~/Downloads` (FSEvents; `.crdownload/.download/.part` → läuft; verschwindet → fertig), Steam (`~/Library/Application Support/Steam/steamapps/appmanifest_*.acf`, Felder `BytesDownloaded`/`BytesToDownload`, Rate über 30 s → Restzeit)
- `Keystroke`: Fallback für Trust-Dialog/AskUserQuestion: Terminal-App (Terminal/iTerm/VS Code/Ghostty — konfigurierbar) aktivieren, `CGEvent` senden; braucht Accessibility-Recht, wird beim ersten Start erklärt
- `Screen`: Screenshot auf Anfrage (Screen-Recording-Recht), skaliert auf 800 px, JPEG → MQTT `deskmate/screen` (nicht retained, oder retained mit TTL per Leer-Publish nach 60 s)
- `MQTT`: publiziert `deskmate/state`, `deskmate/downloads`, abonniert `deskmate/cmd`
- Einstellungen: Tastenbelegung, Fader-Zuweisung (Lautstärke / Gamepad-Achse / App-spezifisch), Watcher an/aus, Terminal-App, MQTT-Zugang — werden ans Gerät geschrieben (`link`) und gespiegelt in `UserDefaults`

**iOS-App:** Ampel + Quelle + Text, Buttons *Weiter / Nein / Screenshot*, Downloads-Liste mit Restzeit, Gerätekonfiguration (BLE direkt, wenn am Tisch; sonst MQTT), Verbindungsstatus. Push: Vercel-Function `POST /api/push` (vom Agent aufgerufen, mit Shared-Secret) → APNs; Gerätetokens in Supabase-Tabelle `deskmate_devices`. Ohne Push bleibt alles funktionsfähig (MQTT bei offener App).

**Windows (Phase 2):** `agent-windows/deskmate_tray.py` — pyserial + watchdog + pystray + kleiner HTTP-Server; derselbe Ereignis-Endpunkt, dieselbe Serial-Protokollversion. Gamepad/Media-Keys brauchen keinen Agent.

---

## 5 · Claude-Code-Integration (Hooks) — verifiziert gegen die Doku am 2026-08-22

Quelle: https://code.claude.com/docs/en/hooks.md. Global in `~/.claude/settings.json` (gilt für alle Projekte), Skript `tools/deskmate-hook.sh` im Repo. Jeder Hook ruft nur `curl -s localhost:4821/...` auf und ist in < 50 ms fertig — außer dem Freigabe-Hook, der wartet. Hooks erhalten JSON auf stdin (`hook_event_name`, `session_id`, `cwd`, bei Notification `notification_type`), `$CLAUDE_PROJECT_DIR` ist gesetzt.

| Ereignis | Matcher | Aktion | Ampel |
|---|---|---|---|
| `UserPromptSubmit` | — | `POST /event {source:"claude", state:"busy", cwd}` | gelb |
| **`PermissionRequest`** | Tool-Name (z. B. `Bash`, `Write`, `Edit`, `*`) | `POST /await-ack` mit Timeout *T* (z. B. 45 s, `timeout` im Hook-Eintrag etwas höher). Taste **Weiter** → Hook antwortet `{"hookSpecificOutput":{"hookEventName":"PermissionRequest","permissionDecision":"allow","permissionDecisionReason":"Desk-Mate Taste"}}`; Taste **Nein** → `deny`; Timeout → `escalate` (normaler Prompt) | rot, bis Taste |
| `Notification` | `permission_prompt`, `idle_prompt`, `agent_needs_input` | `POST /event {state:"needs_you_urgent", text:<notification_type>}` | rot blinkend |
| `PreToolUse` | `AskUserQuestion` | `POST /event {state:"needs_you", text:<Frage aus tool_input>}` — ob `tool_input` die Frage trägt, ist **nicht dokumentiert** → beim Bau testen | rot |
| `Stop` | — | `POST /event {state:"idle", text:"fertig"}` | grün + Freude-Animation |
| `SessionStart` / `SessionEnd` | — | projektlokal (Zeiterfassung, commit/push), siehe 6 | — |

Nicht abfangbar (verifiziert): der Trust-Dialog beim Start feuert vor allen Hooks. Für ihn und für `AskUserQuestion`-Antworten bleibt der Tastendruck-Fallback des Agents. `permissionDecision` kennt `allow | deny | escalate` (nicht „ask“). Ein maximaler Hook-Timeout ist nicht dokumentiert → im Plan: mit 60 s testen, Ergebnis in `CLAUDE.md` → Bekannte Fallen.

Sicherheits-Regel: Der Freigabe-Hook gibt **nur** frei, was Claude Code ohnehin per Prompt gefragt hätte, und nur für den aktuellen Aufruf. Keine Pauschal-Freigaben; `deny` ist immer eine Taste entfernt.

---

## 6 · Projekt-Infrastruktur (ab Commit 1)

```
Desk-Mate/
  README.md                 Template (Was · Architektur-ASCII · Pfadtabelle · Bauen)
  CLAUDE.md                 Architektur · Build & Test · Bekannte Fallen · Konventionen · Session-Pflichten
  LICENSE                   MIT (gilt auch für die Hardware, entschieden 2026-10-09)
  .gitignore                secrets.h, .env, *.local.xcconfig, .obsidian/workspace*, Build-Ordner, KiCad-Backups
  .claude/settings.json     SessionStart/SessionEnd-Hooks (Zeiterfassung, commit+push)
  tools/                    session-start.sh, session-end.sh, check-secrets.sh (pre-commit), deskmate-hook.sh
  docs/relic/               Ursprungs-Prompt (unveränderlich)
  docs/superpowers/specs/   dieser Spec
  docs/superpowers/plans/   Implementierungsplan
  docs/anleitung/           Bauanleitung (wächst mit den Tasks)
  docs/logo/                Logo SVG + PNG
  vault/                    Obsidian-Vault: Log/ Entscheidungen/ Hardware/ Firmware/ Apps/ Bestellungen/ Index.md
  hardware/kicad/{mainboard,frontpanel,eye-adapter}/
  hardware/3d/
  hardware/bom.md
  firmware/arduino/deskmate/
  app/
  agent-windows/
  server/                   Vercel-Function für APNs
```

**Arbeitszeit:** `SessionStart`-Hook schreibt `- start HH:MM` in `vault/Log/YYYY-MM-DD.md` (legt Datei mit Frontmatter an, wenn fehlt); `SessionEnd`-Hook schreibt `- ende HH:MM (N min)` und summiert `dauer_min` im Frontmatter. Claude ergänzt im selben Tagesblatt *Was ist passiert* (Pflicht laut CLAUDE.md).
**Push:** `SessionEnd`-Hook: `git add -A && git commit -m "Session YYYY-MM-DD HH:MM: <erste Zeile aus Was-ist-passiert>" && git push` — nur wenn `check-secrets.sh` sauber ist (Grep nach `ssid|password|passwd|token|apikey|secret` mit Wert ≠ Platzhalter in getrackten Dateien außer `*.example.*`). Hook-Timeout 120 s; Push-Fehler landen in `vault/Log/` statt die Session zu blockieren.
**Sponsoring:** jede Bestellung als `vault/Bestellungen/YYYY-MM-DD-<lieferant>.md` (Positionen, Kosten, Lieferzeit, Fotos skaliert ≤ 1 MB); daraus entsteht später die Case-Study. Leon benachrichtigt JLCPCB selbst — Claude erinnert im Tagesblatt.
**Website:** Eintrag P12 im Portfolio (Supabase `projects.items`), sobald das erste echte Foto existiert — Task am Ende von Phase „Hardware aufgebaut“.

---

## 7 · Roadmap (nicht v1)

SmartKnob als externes Gerät über MQTT/USB · watchOS-App (Ampel am Handgelenk) · Android-App · iPadOS · Home-Assistant-Discovery-Payloads · Körper-Stepper (bräuchte eine Mainboard-Revision, Sockel gestrichen 2026-10-04) · 4 Fader bestücken · Lern-Funktion (Arbeitsrhythmus → Pausen-Erinnerung; erst wenn Log-Daten da sind) · Backlight-Dimmen (kein freier PWM-GPIO in Rev. 1) · Windows-Tray.

---

## 8 · Offene Punkte (werden im Plan als Tasks geführt)

1. ~~Pin-Map prüfen~~ erledigt 2026-08-23: alles verifiziert, siehe `vault/Hardware/Pin-Map.md` und `firmware/arduino/deskmate/pins.h`. Neu offen: **X32-Fader charakterisieren, sobald geliefert (Di 25.08.):** Kabel-Pinout, Motorspannung/-strom bei 5 V (Anlauf/Stall), Touch-Kontaktierung, Rahmen-Maße + Schraubpunkte für Panel/3D-Druck → erst danach Frontpanel-Layout und VM-Rail final.
2. ~~USB-Daten~~ erledigt 2026-08-23: Panel-Mount-USB-C-Verlängerung zur DevKit-Buchse (§2.2).
3. ~~ODER-Stufe~~ erledigt 2026-08-23: Polyfuse + SB540 + DevKit-Diode, kein P-FET (§2.2).
4. ~~HiveMQ-Free-Tier~~ erledigt 2026-08-23: max. Nachrichtengröße 5 MB (Quelle: community.hivemq.com/t/maximum-message-size/3087) → 800-px-Screenshots unkritisch.
5. `PreToolUse`/`AskUserQuestion`: trägt `tool_input` die Frage? Maximaler Hook-Timeout? → testen.
6. ~~Lizenz~~ erledigt 2026-10-09: MIT für alles (wie im Repo).
7. ~~Frontpanel-Anordnung~~ erledigt 2026-10-09: KiCad-Vorschlag freigegeben.
8. Vor dem Löten nachmessen: DRV8833-Module aus der Box = Pololu #2130 (Reihen 10,16)? Sonst Pololu kaufen. MPR121 und BME680 hängen seit 2026-10-09 am Kabel, deren Raster spielt keine Rolle mehr. DevKit-Sockel 22,86 ist per Espressif-DXF belegt. Details `vault/Hardware/Module-Masse.md`.

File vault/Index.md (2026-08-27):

# Desk-Mate — Vault

Obsidian-Vault im Repo. Alles, was nicht Code ist: Tagesblätter mit Arbeitszeit, Entscheidungen, Hardware-Notizen, Bestellungen.

## Bereiche
- [[Log/2026-08-22]] — Tagesblätter (`Log/YYYY-MM-DD.md`), Start/Ende schreiben die Session-Hooks
- [[Entscheidungen/2026-08-22-Grilling]] — alle Design-Entscheidungen mit Begründung
- [[Hardware/Pin-Map]] · [[Hardware/Strombudget]]
- [[Firmware/Module]]
- [[Apps/Claude-Hooks]]
- [[Bestellungen/README]] — Vorlage; je Bestellung eine Notiz (Sponsoring-Material)

## Außerhalb des Vaults
- Spec: [docs/superpowers/specs/2026-08-22-desk-mate-design.md](../docs/superpowers/specs/2026-08-22-desk-mate-design.md)
- Plan Phase 0–2: [docs/superpowers/plans/2026-08-22-phase-0-2-infra-bauteile-kicad.md](../docs/superpowers/plans/2026-08-22-phase-0-2-infra-bauteile-kicad.md)
- Relikt: [docs/relic/2026-08-22-original-prompt.md](../docs/relic/2026-08-22-original-prompt.md)
- Arbeitsregeln: [CLAUDE.md](../CLAUDE.md)

## Arbeitszeit gesamt
Summe aller `dauer_min` in `Log/` — Dataview-Query, sobald das Plugin installiert ist:
```
TABLE dauer_min FROM "Log" SORT file.name DESC
```

- [[Module-Masse]] — Sockel-Maße der Module mit Quellen und Konfidenz
- [[2026-08-27-kicad-generator]] — KiCad per Generator, Schaltungsdetails

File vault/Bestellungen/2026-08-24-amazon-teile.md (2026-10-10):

# 2026-08-24 — Amazon.de (Module) — im Aufbau

**Stand 2026-10-09:** nie bestellt. Switches und Encoder kommen jetzt von Reichelt ([[2026-10-09-reichelt]]), die Module bleiben bei Amazon — aktuelle Liste: `hardware/bom.md` Teil B.

**Status (24.08.):** Warenkorb komplett (24.08.) — Summe Amazon ~**96,4 €** + Aluknopf offen. Bestand: DRV8833, Netzteil.

| Pos | Artikel | Stück | Preis € | Quelle | Notiz |
|---|---|---|---|---|---|
| 1 | GC9A01 1,28" rund SPI (Augen) | 2 (Pack) | 10,07 | Amazon | Ali-Vergleich: 8,20 |
| 2 | ILI9341 2,8" SPI 320×240 (Bauch) | 1 | 14,11 | Amazon | |
| 3 | DRV8833-Module | 2 | 0 | **Bestand** | Amazon-Fallback 10,07; nSLEEP bei Charakterisierung prüfen |
| 4 | MG90S Metallgetriebe-Servos | 2 | 14,10 | Amazon | |
| 5 | EC11 Drehencoder nackt (5er-Pack) | 1 Pack | 7,04 | Amazon | Variante mit PCB (7,51) abgelehnt — direkt aufs Frontpanel |
| 5b | Aluknopf 6-mm-Achse | 1 | offen | Amazon | Optik-Kür, Leon sucht aus |
| 6 | MT3608 Step-Up (Pack) | 1 Pack | 6,04 | Amazon | VM-Boost-Reserve für Fader-Motoren |
| 7 | USB-C-Panel-Verlängerung (Buchse m. Flansch → Stecker) | 1 | 8,05 | Amazon | Daten-Port Rückwand → DevKit |
| 8 | MPR121 Touch-Breakout I²C | 1 | 6,04 | Amazon | Clone reicht |
| 9a | MX-Switches linear (Pack) | 10+ | 7,04 | Amazon | |
| 9b | ~~Kailh-Hot-Swap-Sockel~~ | — | — | gestrichen | keine mit Prime; außerdem SMD → Switches werden direkt THT gelötet (Entscheidung 24.08.) |
| 9c | Keycaps blank | 10 | 10,04 | Amazon | |
| 10 | Netzteil 5 V/3 A USB-C | 1 | 0 | **Bestand** | Leon hat passendes |
| 11 | ESP32-S3-DevKitC-1-**N16R8** (Espressif Original) | 1 | 19,99 | Amazon (Prime) | statt diymore-Clone-2er (14,56) — Sockel-Pinout-Sicherheit; Listing auf „N16R8“ geprüft |

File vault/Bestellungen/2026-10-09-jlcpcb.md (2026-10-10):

---
datum: 2026-10-09
lieferant: JLCPCB
status: bereit — noch nicht bestellt
---
# 2026-10-09 — JLCPCB (drei Platinen, Sponsor)

**Status:** Fertigungsdaten final (Rev 1, 2026-10-09). **Bestellt:** — (Leon trägt Bestellnummer, Kosten, Lieferzeit, Tracking nach).

| Pos | Datei | Maß | Stück |
|---|---|---|---|
| 1 | `hardware/kicad/mainboard/fab/mainboard-gerber.zip` | 100 × 100 mm | 5 |
| 2 | `hardware/kicad/frontpanel/fab/frontpanel-gerber.zip` | 120 × 136 mm | 5 |
| 3 | `hardware/kicad/eye-adapter/fab/eye-adapter-gerber.zip` | 42 × 30 mm | 5 |

Parameter: 2 Lagen, 1,6 mm, HASL bleifrei, kein Assembly (alles THT), **Mark on PCB: „Order Number (Specify Position)“** → Feld `JLCJLCJLCJLC` auf der Rückseite. Farbe frei (Logo funktioniert grün und weiß). Details: `docs/anleitung/01-platinen.md`.

**Sponsoring:** Nach der Bestellung den JLCPCB-Kontakt informieren (Bestellnummer + Renderbilder aus `fab/`). Fotos vom Auspacken hier ablegen (≤ 1 MB).

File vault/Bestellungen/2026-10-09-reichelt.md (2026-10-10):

---
datum: 2026-10-09
lieferant: Reichelt
status: Warenkorb-Vorlage — noch nicht bestellt
---
# 2026-10-09 — Reichelt (alle Teile für die drei Platinen)

**Status:** Liste fertig, Art.-Nr. am 2026-10-09 auf reichelt.de geprüft (alle „2–3 Werktage“). **Bestellt:** — (Leon trägt Datum, Bestellnummer, Tracking nach). Quelle der Positionen: `hardware/bom.md` Teil A.

| Pos | Reichelt Art.-Nr. | Bauteil | Stück | Preis € |
|---|---|---|---|---|
| 1 | BKL 10120978 | Buchsenleiste 1×40, 2,54 | 3 | 9,54 |
| 2 | SL 1X40G 2,54 | Stiftleiste 1×40, 2,54 | 2 | 0,60 |
| 3 | ECON SL4G2 | Stiftleiste 2×2 | 1 | 0,13 |
| 4 | MKDS 1,5 4 5,08 | Leiterplattenklemme 4-pol. RM 5,08 | 1 | 1,61 |
| 5 | HAN 530 6324 | Wannenstecker 2×15 | 2 | 4,24 |
| 6 | HAN 530 6803 | Pfostenbuchse 30-pol. | 2 | 3,70 |
| 7 | WSL 10G | Wannenstecker 2×5 | 2 | 0,30 |
| 8 | PFL 10 | Pfostenbuchse 10-pol. | 2 | 0,20 |
| 9 | AWG 28-40G 3M | Flachbandkabel 40-pol., 3 m | 1 | 6,96 |
| 10 | LD1117V33 | LDO 3,3 V TO-220 | 1 | 0,25 |
| 11 | SB 540 DIO | Schottky 40 V/5 A | 1 | 0,30 |
| 12 | LITT RXEF300 | PTC 3 A | 1 | 1,00 |
| 13 | MCP 23017-E/SP | I/O-Expander DIP-28 | 1 | 1,76 |
| 14 | GS 28P-S | IC-Sockel DIP-28 schmal | 1 | 0,45 |
| 15 | BC 327-25 | PNP TO-92 | 1 | 0,06 |
| 16 | RAD 105 1.000/16 | Elko 1000 µF/16 V | 2 | 0,42 |
| 17 | NHG-A 470U 16 | Elko 470 µF/16 V | 1 | 0,23 |
| 18 | HD-A 100U 16 | Elko 100 µF/16 V | 2 | 0,80 |
| 19 | JAM TKP100M1JD11 | Elko 10 µF/63 V | 1 | 0,05 |
| 20 | KERKO 100N | Kerko 100 nF RM 5 | 9 | 0,36 |
| 21 | KERKO 10N | Kerko 10 nF | 2 | 0,16 |
| 22 | METALL 5,10K | Widerstand 5,1 kΩ | 2 | 0,14 |
| 23 | METALL 10,0K | Widerstand 10 kΩ | 4 | 0,28 |
| 24 | METALL 15,0K | Widerstand 15 kΩ | 1 | 0,07 |
| 25 | METALL 330 | Widerstand 330 Ω | 1 | 0,07 |
| 26 | METALL 4,70K | Widerstand 4,7 kΩ | 2 | 0,20 |
| 27 | METALL 1,00K | Widerstand 1 kΩ | 5 | 0,35 |
| 28 | CHERRY MX2A-11NW | Cherry MX Black, PCB-Montage | 10 | 4,50 |
| 29 | STEC11B03 | ALPS-Drehgeber mit Taster | 1 | 4,69 |
| 30 | KNOPF 20-6 SW | Knopf 6-mm-Achse | 1 | 2,92 |
| 31 | ECON D3X11A5MT | Abstandsbolzen M3 × 11 I/A | 4 | 0,72 |
| optional | (Soldered 333011) | USB-C-Breakout mit CC-Pins — oder von Amazon | 1 | 1,77 |
| | | **Summe** | | **≈ 47 € (+ 1,77) + Versand ab 6,95 €** |

**Lieferzeit:** 2–3 Werktage. **Fotos:** beim Auspacken für die Case-Study (≤ 1 MB, hier ablegen).

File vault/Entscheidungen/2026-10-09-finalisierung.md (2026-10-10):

---
datum: 2026-10-09
typ: entscheidung
---
# Finalisierung der Platinen — Reichelt, Kabel statt Sockel, Silkscreen

**Kontext:** Leon: „finalisieren … so einfach wie möglich, so wenig SMD wie's geht, keine komplizierten Teile, alles muss ich auf Reichelt bekommen, coole Silkscreen“. Im Grilling präzisiert: **gelötete Teile von Reichelt, Module dürfen von Amazon kommen.** Grundlage: Reichelt-Recherche vom selben Tag (zwei Agenten + eigene Abfrage der Produktseiten, Art.-Nr. in `hardware/bom.md`).

## Was Reichelt nicht hat → Lösung

| Teil | Problem | Optionen | Wahl | Grund |
|---|---|---|---|---|
| USB-C-Platinenbuchse (GCT USB4085) | Reichelt führt keine THT-USB-C-Buchse | Breakout + Schraubklemme · Hohlbuchse · Buchse von TME | **USB-C-Breakout in der Rückwand → 4-pol. Schraubklemme MKDS 1,5/4-5,08** (VBUS GND CC1 CC2), 5,1 kΩ bleiben auf dem Mainboard | bleibt bei 2× USB-C (Grilling #11); die 0,85-mm-Buchse samt Handrouting entfällt; Breakout von Amazon oder Reichelt (Soldered 333011) |
| DRV8833-Breakout | Reichelt hat keinen | SN754410 DIP-16 · L298N-Modul · Amazon | **Pololu #2130 bleibt** (Amazon/Bestand) | Leon: „Amazon generell ist auch ok“; Sockel und Pin-Map unverändert |
| 2,8"-ILI9341-Modul | Reichelt hat nur Arduino-Shields (Parallelbus) und Industrie-Displays mit FPC | Amazon-MSP2807 · Reichelt 1,3" ST7789 | **2,8" von Amazon** | großes Bauch-Display (Grilling #9), Frontpanel bleibt |
| Keycaps | Reichelt hat keine | Amazon · 3D-Druck | Amazon oder Druck | — |
| Flachband 30-adrig | nur 40-adrig | — | 40-adrig, abreißen | Standard |

## Vereinfachungen, die dabei fielen

| Was | Vorher | Jetzt | Grund |
|---|---|---|---|
| Servo/ARGB | JST-XH | 1×3-Stiftleiste | Servostecker passt direkt, eine Teilefamilie weniger |
| BME680 | 1×6-Sockel (CJMCU-Reihenfolge ungeprüft) | 1×4-I²C-Stiftleiste, Sensor per Kabel | Pinfolge egal, Sensor weg von der ESP-Wärme |
| MPR121 | Sockel im SparkFun-Raster (Clone unbelegt) | 1×9-Stiftleiste J18, Modul per Kabel | Falle 15: ohne Maßzeichnung kein Sockel |
| Augen-Kabel | 1×10-Stiftleiste | IDC 2×5 (WSL 10G/PFL 10), GND zwischen SCK und MOSI | verpolsicher, gleiches Flachband |
| Augen-Adapter | 2× 7-Pin-Buchse 20 mm auseinander | 2× 1×7-Stiftleiste, Displays per Dupont | die 38-mm-Module hätten sich überlappt — Fehler im alten Entwurf |
| R17 (DISP_RST-Pull-up) | rechts neben dem MCP23017 | unter dem MCP23017 | blockierte die Leitung KEY9 beim Routen |
| 5-V-Schiene Servos/ARGB | Freerouting | feste Leiterbahn (pre_tracks) bei x = 92,5 | Freerouting fand sie mit 1 mm Breite an R5 vorbei nicht |

**Silkscreen:** vorne Desk-Mate-Kopf (Visier gefüllt, Augen und Lächeln als Aussparung), Platinenname, „Rev 1 · 2026-10“ und Pin-Namen an jedem Stecker; hinten großer Kopf, GitHub-Link, „Leon Fröhlich · 2026“, Feld `JLCJLCJLCJLC` (Bestellnummer, Option „Specify Position“). Referenzen ausgeblendet, wo Titel + Pin-Namen sie ersetzen. Daten: `'silk'` in `boards.py`, gezeichnet von `add_silk()` in `build_pcb.py`.

**Weiter offen (nicht platinenrelevant):** Lizenz → MIT für alles (Leon hat nicht widersprochen). Frontpanel-Anordnung → freigegeben. Fader-Charakterisierung → nach Lieferung, hängt an Drähten.

**Verifikation:** alle drei Boards 0 offene Verbindungen, 0 DRC-Fehler, ERC sauber, Netzlisten-Abgleich ok, `tools/test-*.sh` grün; Netzklassen-Zuordnung 15/12/2 intakt (Falle 18). Siehe [[2026-10-04-reserve-raus]], [[Module-Masse]].

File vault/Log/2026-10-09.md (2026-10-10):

---
datum: 2026-10-09
dauer_min: 176
---
# 2026-10-09

## Was ist passiert
- Platinen finalisiert: Teile von Reichelt, Silkscreen mit Logo und Pin-Namen, alle drei Boards neu geroutet
- Leon: „finalisieren … so einfach wie möglich, kein SMD, alles auf Reichelt, coole Silkscreen“ → präzisiert: gelötete Teile Reichelt, Module dürfen von Amazon kommen. Entscheidung [[2026-10-09-finalisierung]]
- Reichelt-Recherche (2 Agenten + Produktseiten selbst geprüft): keine THT-USB-C-Buchse, kein DRV8833-/TB6612-Breakout, kein 2,8"-SPI-Modul, keine Keycaps; dafür ALPS-Motorfader RSA0N11M9 (18,70 €) und DevKitC-1 N8R8 im Sortiment
- Mainboard: J1 = Schraubklemme für ein USB-C-Breakout (USB4085 + Handrouting weg), Servo/ARGB als 1×3-Stiftleisten, BME680 als I²C-Leiste per Kabel, Augen-Kabel IDC 2×5 mit GND zwischen SCK/MOSI, 5-V-Servoschiene als feste Leiterbahn (Freerouting kam nicht an R5 vorbei)
- Frontpanel: MPR121 per Kabel an J18 (Falle 15, Clone-Raster unbelegt), R17 unter den MCP23017 (blockierte KEY9); Anordnung von Leon freigegeben
- Augen-Adapter: Fehler im alten Entwurf gefunden — die Buchsen lagen 20 mm auseinander, die 38-mm-Displays hätten sich überlappt → 1×7-Stiftleisten + Dupont-Kabel
- Silkscreen per Generator (`'silk'` in boards.py, `add_silk()`): Desk-Mate-Kopf mit Augen/Lächeln als Aussparung, Pin-Namen an allen Steckern, Rückseite mit GitHub + `JLCJLCJLCJLC` (JLCPCB-Bestellnummer, „Specify Position“)
- Stückliste neu (`hardware/bom.md`): Reichelt ≈ 47 € mit geprüften Art.-Nr., Module ≈ 130 € Amazon; Bestellnotizen [[2026-10-09-reichelt]] und [[2026-10-09-jlcpcb]]
- Tests: check-secrets, session-hooks, pins, kicad — alle OK; DRC 0 Fehler, 0 offen; Netzklassen 15/12/2 intakt
- **Erinnerung Sponsoring:** nach der JLCPCB-Bestellung den Kontakt informieren (Bestellnummer + Renderbilder)

## Sessions
- start 08:41
- ende 08:41 (0 min)
- start 08:41
- ende 11:37 (176 min)

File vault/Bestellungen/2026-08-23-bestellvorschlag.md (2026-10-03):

# 2026-08-23 — Bestellvorschlag (noch nichts bestellt)

**Zweck:** Alle Teile für Desk-Mate v1 (Spec §2). **Status: Entwurf** — wartet auf Arduino-Box-Inventur.

## Nach Lieferant (aktualisiert 23.08.: Amazon-first, Leons Entscheidung B2)

| Lieferant | Positionen | ca. € |
|---|---|---|
| **Amazon.de (Prime, sofort)** | GC9A01 ×2 · ILI9341 2,8" SPI · DRV8833-Module ×2 (EEP/SLP prüfen!) · MG90S ×2 (Metal Gear, Retour-Option) · EC11-Modul · MT3608-Pack · USB-C-Panel-Verlängerung · MPR121-Clone · MX-Switches/Hotswap-Sockel/DSA-Caps (falls Preis ok, sonst Keycapsss 12 €) · ggf. RPi-Netzteil | ~85–100 |
| **Mouser** | ESP32-S3-DevKitC-1-**N16R8** (Amazon nur, wenn Listing explizit Espressif-Original N16R8) | 14 + Versand |
| **Reichelt** (nach Inventur) | MCP23017+Sockel, LD1117V33, SB540, Polyfuse, Elkos/Kerkos, IDC-Set, Leisten, BC327 (BC337 seit 2026-10-04 nicht mehr nötig) | ~12 |
| ~~eBay/US~~ **Amazon.de** | ~~MF60T~~ **X32 Motor-Fader 5er-Set 100 mm — bestellt 23.08., Lieferung 25.08.** | 39,32 |
| **Farnell** | RXEF300 Polyfuse | ~1 + Versand → ggf. Reichelt-Äquivalent |

## Entscheidungen vor dem Bestellen (Leon)
1. ~~Qualität vs. Budget~~ entschieden 23.08.: **Amazon-first** (Prime), Mouser nur für den N16R8, Reichelt nach Inventur.
2. Netzteil vorhanden? USB-C-Kabel vorhanden? → Inventur

**Sponsoring-Hinweis:** Das ist die Teile-Bestellung, nicht JLCPCB — Fotos vom Auspacken trotzdem sammeln (Case-Study).

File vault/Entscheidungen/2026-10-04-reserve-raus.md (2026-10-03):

---
datum: 2026-10-04
typ: entscheidung
---
# Reserve raus — Platinen ohne „vielleicht später“

**Kontext:** Teile und Fader sind noch nicht da, JLCPCB ist noch nicht bestellt. Leon: „so einfach wie möglich, nichts überkompliziert, aber funktional“. Die 18 Grilling-Entscheidungen bleiben; gestrichen wird nur, was nie bestückt würde und trotzdem Platz, Lötjumper und Fallen kostet.

**Optionen:** (a) streichen und alle drei Platinen neu generieren; (b) nur Spec/BOM ändern, Platinen in der GUI anpassen; (c) nichts streichen, nur unbestückt lassen. **Wahl: (a)** — der Generator bleibt die eine Quelle, `tools/test-kicad.sh` prüft das Ergebnis. Die GUI-Änderung am Mainboard vom 28.08. war nur eine Verschiebung um 54 mm, kein Design; Frontpanel und Augen-Adapter wurden nie in der GUI angefasst.

| Was | Entscheidung | Grund |
|---|---|---|
| Stepper-Sockel U7, Header J10, Elko C8, JP6–JP8 | raus | Grilling #2: kein Körper-Stepper |
| C3-Footprint U6, JP2/JP3 | raus | Grilling #4: C3 gestrichen; IO43/44 bleiben Debug-UART |
| GPIO45 → Backlight-PWM (JP1 Mainboard, JP11 Frontpanel) | raus, GPIO45 tabu | Dimmen ist Roadmap; einziger Grund für Falle 13 und den zweistufigen Schalter |
| nSLEEP-Jumper JP5 (ab Werk gebrückt) | raus, nSLEEP fest an 3V3 | wird nie geöffnet, es gibt keinen GPIO dafür |
| Backlight-Schalter | einstufig: MCP23017 GPB6 → 1 kΩ → Basis BC327 (high-side an 3V3), 10 kΩ Basis–Emitter; GPB6 low = Licht an | ohne GPIO45 ist der Pull-up erlaubt; 10 kΩ hält das Licht aus, bis die Firmware den MCP konfiguriert |
| INT-Jumper JP9/JP10 | raus, INTA direkt an IO_INT, INTB unbeschaltet | Firmware setzt MIRROR=1 |
| Augen-Reset | RC-Glied raus; DISP_RST vom MCP23017 (GPB5) über IDC-Pin 29 und Pin 10 des Augen-Kabels (bisher dritter GND), 10 kΩ Pull-up auf dem Frontpanel | ein Reset-Pfad für drei Panels; bisher floatete der Bauch-Reset bis zur MCP-Konfiguration (latenter Fehler), die Augen hatten nur den Software-Reset |
| VM-Boost-Jumper + MT3608-Header U5 | **bleibt**, Jumper heißt jetzt JP1 | einziger echter Einstellknopf: ob der X32-Fader bei 5 V schnell genug ist, zeigt erst die Messung |
| Zweiter DRV8833-Sockel, Fader 3/4 | bleibt | Grilling #8: 2 bestückt, 4 vorgesehen |

**Ergebnis:** Mainboard 8 → 1 Lötjumper, −2 Sockel, −1 Header, −1 Elko. Frontpanel 3 → 0 Lötjumper, −1 Transistor, −2 Widerstände, +1 Pull-up. Augen-Adapter nur noch Stecker + 2× 100 nF. Falle 13 ist gegenstandslos; `tools/test-pins.sh` blockt GPIO45 wie die anderen Strapping-Pins.

Nachgezogen: Spec §1, §2.1–2.4, §7, §8 · `hardware/bom.md` · `hardware/kicad/gen/boards.py` · `pins.h` · READMEs · [[Module-Masse]] · [[Pin-Map]].

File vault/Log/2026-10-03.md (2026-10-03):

---
datum: 2026-10-03
dauer_min: 33
---
# 2026-10-03

## Was ist passiert
- Reserve raus (Stepper, C3, GPIO45, 7 Loetjumper), alle drei Platinen neu geroutet; Push und Falle 18 behoben
- Vereinfachung nach Leons Wunsch („so einfach wie möglich, aber funktional“), Grilling-Entscheidungen bleiben: [[2026-10-04-reserve-raus]]. Mainboard 8 → 1 Lötjumper (nur noch VM-Boost), Stepper-Sockel + C3-Footprint weg; Frontpanel ohne Jumper, Backlight einstufig (BC337 weg); GPIO45 unbelegt → Falle 13 gegenstandslos, test-pins blockt 45
- Augen-Reset vereinheitlicht: DISP_RST vom MCP23017 über IDC-Pin 29 + Augen-Kabel-Pin 10, 10k Pull-up; RC-Glied auf dem Augen-Adapter weg. Behebt nebenbei den floatenden Bauch-Reset bis zur MCP-Konfiguration
- Platinen neu generiert (`--force` bewusst: GUI-Änderung vom 28.08. war nur eine Verschiebung), alle drei 0 offen / 0 DRC, Fab-Export neu
- Bug in `build_pcb.py`: jeder neue Routing-Versuch überschrieb die Datei mit dem ungerouteten Stand → blieb kein Versuch besser als der erste, lag am Ende eine **leere** Platine da (Frontpanel heute: 113 offene Pads trotz Meldung „1 offen“). Bester Versuch wird jetzt im Speicher gehalten und am Ende geschrieben
- Bug in `session-end.sh`: Sessions über Mitternacht legten ein leeres Blatt für den neuen Tag an (0 min, Commit „Arbeitsstand“), der Start blieb offen. Jetzt zählt das neueste Blatt (= Starttag) und die Dauer +24 h; Testfall in `test-session-hooks.sh` (schlägt mit altem Code fehl)
- Tests: check-secrets, session-hooks, pins, kicad (ERC/DRC/Netzliste aller drei Boards) — alle OK
- Push-Fehler: `a50d2a5` nicht gepusht, „could not read Username … Device not configured“ — osxkeychain hat im Hook-Kontext kein GitHub-Token; `gh` ist als GcodeMadeIt angemeldet, Repo gehört Kalilinuxloverr → behoben: `gh auth login` als Kalilinuxloverr (aktiv) + `gh auth setup-git` (gh als Credential-Helper), `a50d2a5` gepusht, Log geleert
- Falle 18 gefunden: der Testlauf selbst hat `mainboard.kicad_pro` umgeschrieben (`netclass_assignments: null`, 15 Netze ohne Klasse) — wäre per `git add -A` im Auto-Commit gelandet. Datei zurückgesetzt, Test arbeitet jetzt auf Kopien in `$TMPDIR`, danach `git status` sauber
- Mainboard wurde am 28.08. in der KiCad-GUI gespeichert (Board um ~54/54 mm verschoben, BOARD_W/H-Properties; im Auto-Commit 31.08.) → war nur eine Verschiebung, durch die Neugenerierung heute überholt
- Tests: check-secrets, session-hooks, pins, kicad — alle OK; Netzklassen-Zuordnung 15/12/2 intakt
- Blocker vor JLCPCB unverändert: Fader-Charakterisierung, Module nachmessen (Spec §8.8: MPR121, DRV8833, BME680 — C3 entfällt), Frontpanel-Freigabe, Lizenz

## Sessions
- start 23:54
- ende 00:27 (33 min)

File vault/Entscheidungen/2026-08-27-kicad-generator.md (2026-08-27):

---
datum: 2026-08-27
typ: entscheidung
---
# KiCad-Erstversion per Generator statt GUI-Handarbeit — und die Schaltungsdetails, die dabei fielen

**Kontext:** Leon will die Platinen sofort, damit JLCPCB zusammen mit den Teilen bestellt wird. Claude hat keine GUI; drei Boards mit ~110 Bauteilen von Hand als S-Expression zu tippen wäre fehleranfällig.

## 1. Generator (`hardware/kicad/gen/`)
- **Optionen:** (a) Leon zeichnet alles in der GUI nach Spec; (b) Claude schreibt die KiCad-Dateien von Hand; (c) Datenmodell „Bauteil → Pin → Netz → Position“ in Python, daraus Schaltplan (Label-Stil), Bibliothek und Layout (pcbnew-Python + Freerouting), Prüfung per `kicad-cli` ERC/DRC und Netzlisten-Abgleich.
- **Wahl:** (c). Schaltplan und Layout sind per Konstruktion identisch, jede Änderung ist ein Einzeiler, der Test ist eingebaut. Nachteil: Schaltplan ohne Leitungen (nur globale Labels) — in der GUI umsortierbar; der Generator ist Bootstrap, kein Roundtrip (GUI-Änderungen danach sind die Wahrheit).

## 2. Schaltungsdetails (Spec nachgezogen)
| Punkt | Optionen | Wahl | Grund |
|---|---|---|---|
| PSU_SENSE-Teiler | 10k/10k (2,5 V) · 10k/15k (3,0 V) | **10k/15k** | 2,5 V liegt nur 25 mV über VIH (0,75·3,3); 3,0 V hat Reserve, bleibt unter 3,3 V auch bei 5,25 V |
| Backlight-Schalter ILI9341 (150 mA) | NPN low-side (geht nicht: LED-Pin ist Anode) · PNP high-side direkt vom MCP · **BC337 → BC327 zweistufig** | zweistufig | Der PNP-Basis-Pull-up (10 k an 3V3) würde über JP11/JP1 an GPIO45 hängen → Strapping VDD_SPI 1,8 V → Flash tot (Falle 13). Zweistufig sieht die Steuerleitung nur Basiswiderstand + 100 k Pull-down |
| Augen-Reset | DISP_RST vom MCP über 30-adriges IDC (kein Pin frei) · extra GPIO (keiner frei) · **RC 10k/1µ auf dem Adapter** | RC | Software-Reset (SWRESET) reicht im Betrieb; LovyanGFX `pin_rst=-1` |
| MT3608-Boost | Sockel · **4-Pin-Stiftleiste + Drähte** | Stiftleiste | Modul-Lochraster ist nicht 2,54 (6,45–6,8 mm), Sockel wäre Revisionsrisiko; Modul ist optional |
| Servo-Serienwiderstand 10 Ω | drin · **weg** | weg | 0,7 A Stall × 10 Ω = 7 V Abfall — Unsinn; Drosselung macht die Firmware (PSU_SENSE) |
| Pull-ups I²C/IO_INT | Frontpanel · **Mainboard** | Mainboard | IO_INT auch ohne Frontpanel definiert |
| Mainboard-Größe | 100×80 · 100×90 · **100×100** | 100×100 | Reserve-Sockel + IDC + Anschlusskante brauchen Platz; JLCPCB-Preisstufe bleibt ≤100×100 |
| Frontpanel-Anordnung | — | Vorschlag 120×136: Display oben quer (Header links), 6 Soft-Keys, 2×2 Makro, Encoder rechts, Fader **neben** dem PCB | Leons Skizze steht aus — Positionen sind Einzeiler in `boards.py` |
| Fader-Anschluss | Stecker-Footprint · **8-Pin-Stiftleiste je Fader** (MOT+ MOT− GND 3V3 WIPER GND TOUCH GND) | Stiftleiste | X32-Fader hat Lötpins, kein Kabel, kein Touch-Kontakt (Community) — Drähte, Touch am Metallhebel |
| MPR121-Sockel | nur Steuerpins + Drähte · **beide Reihen (SparkFun-Raster 17,78)** | beide Reihen | SparkFun-Eagle-Daten liegen vor; Clone ist 1:1. Wenn der Clone abweicht: Steuerreihe stecken, Elektroden per Draht |

Verifikation: ERC 0 Fehler (3 Boards), Netzlisten-Abgleich KiCad ↔ Modell identisch, DRC siehe Tagesblatt. Quellen der Maße: [[Module-Masse]].

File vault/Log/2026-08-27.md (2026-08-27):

---
datum: 2026-08-27
dauer_min: 1
---
# 2026-08-27

## Was ist passiert
- KiCad-Erstversion aller drei Platinen generiert: Bibliothek, Schaltplaene (ERC sauber), Layouts (Freerouting), Fab-Export, tools/test-kicad.sh
- Leon: „das PCB auch gleich machen, damit alles auf einmal bestellt werden kann“ → Phase 2 (Plan Tasks 11–16) heute als Generator-Erstversion (`hardware/kicad/gen/`), Entscheidung [[2026-08-27-kicad-generator]]
- Recherche-Agent gegen Herstellerdoku: DevKit-Reihenabstand 22,86 (Espressif-DXF), **Pin 1 am Antennenende** (Falle 14), Pololu DRV8833/A4988-Raster, MSP2807-Löcher, MPR121 = SparkFun-Layout, MT3608 nicht 2,54-kompatibel (Falle 15), X32-Fader ohne Kabel/Touch → [[Module-Masse]]
- Schaltungskorrekturen beim Ausdetaillieren: PSU_SENSE 10k/15k, Backlight zweistufig wegen GPIO45-Strapping (Falle 13), Augen-Reset per RC, Servo-10Ω gestrichen, Pull-ups aufs Mainboard, Mainboard 100×100
- Toolchain: kicad-cli 10.0.1 + KiCad-Python (pcbnew) + Freerouting 2.3.0 (`~/Applications/`), Platzierungs-Überlappungscheck im Generator (fand 7 Kollisionen vor dem ersten DRC)
- Router-Odyssee: Freerouting hängt ohne `-Djava.awt.headless=true` (Falle 16), pcbnew.Save killt Netzklassen (Falle 17), `2.8"` im Bauteilwert zerstört das DSN, USB4085-Pads (0,85 mm) brauchen handgelegte Brücken + CC1-Flucht; Retry-Schleife mit Strategien, am Ende **alle drei Boards: 0 DRC-Fehler, 0 offene Verbindungen** (`tools/test-kicad.sh` grün)
- Fab-Export liegt in `hardware/kicad/<board>/fab/` (Gerber-Zip für JLCPCB, STEP, Render, Schaltplan-PDF); Anleitung `docs/anleitung/01-platinen.md`
- Offen vor der JLCPCB-Bestellung: Leons Freigabe der Frontpanel-Anordnung, Nachmessen C3/MPR121/DRV8833-Module/BME680-Pinfolge, Fader-Charakterisierung (Set seit 25.08. da?)

## Sessions
- start 11:30
- ende 11:31 (1 min)
- start 11:31
- start 11:31
- ende 11:31 (0 min)

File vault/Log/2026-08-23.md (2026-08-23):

---
datum: 2026-08-23
dauer_min: 25
---
# 2026-08-23

## Was ist passiert
- Referenzbild von Leon: weißer Roboter, dunkles Visier über beiden Augen, Panel angewinkelt → Spec §2.1/§2.6 aktualisiert, Bild in docs/design/
- Design-Entscheidung: WS2812-Leiste wird der Mund hinter dem Visier (Ampel = Mundfarbe), Panel-Winkel ~20° Arbeitsannahme
- Logo v2 im Visier-Look
- HiveMQ-Free-Tier verifiziert: 5 MB max. Nachricht → Screenshot-Größe kein Thema (Spec §8.4 geschlossen)
- Task 7 fertig: Pin-Map komplett gegen Datenblätter + DevKitC-1-Schaltplan verifiziert → pins.h mit Test. Wichtig: MF60T-Motor lt. Soundwell 6–10 V → VM-Lötjumper + Boost-Sockel-Reserve am Mainboard; DRV8833 als Pololu #2130 (16-polig); GPIO 35–37 unverbunden lassen
- Task 10.1 entschieden: Daten-Port als Panel-Mount-USB-C-Verlängerung zur DevKit-Buchse; ODER-Stufe vereinfacht auf Polyfuse + SB540 + DevKit-Diode (P-FET entfällt). Rail ~4,65 V → Fader-VM-Frage bleibt beim Boost-Sockel
- Task 9 fertig (bis auf Inventur): hardware/bom.md mit MPNs, Quellen, Preisen; Bestellvorschlag im Vault. Summe ~160 € (EU) / ~100–110 € (AliExpress-Mix)
- Beschaffungsrisiko: MF60T hat keinen EU-Händler (Thomann verifiziert negativ) → eBay.de beobachten oder Sweetwater-US-Import; N16R8 nur bei Mouser
- Nächste Schritte: Leons Inventur + MF60T-Entscheidung, dann Task 11 (KiCad-Projekte + Bibliothek)
- Leon: EVE-Look bestätigt (smooth/modern), ARGB-Streifen aus Drohnen-Bestellung vorhanden → LED-Anschluss bleibt generische 3-Pin-Buchse
- Task 7 gestartet: Pin-Verifikation gegen S3-Datenblatt und DevKitC-1-Schaltplan (Recherche-Agent)

- Logo v3 (professioneller Look: Gradients, Glow, Visier) für GitHub + Website; Wordmark dazu
- Website: Desk-Mate als P12 live — Supabase-Dokument aktualisiert (Backup im Scratchpad), Seed-Fallback synchron, Cover als SVG, Push → Vercel-Deploy
- README mit Logo + Zwischenstands-Tabelle; Anleitungs-Gerüst in docs/anleitung/
- Lizenz erklärt und entschieden: MIT für alles (Code + Hardware), Ein-Datei-Änderung falls später strenger gewünscht
- Leon: Bauteile besprechen wir gemeinsam (BOM bleibt Entwurf bis Inventur)

- Bauteil-Gespräch B1: Fader entschieden — Behringer X32-Set (5× 100 mm, Amazon 39,32 €, bestellt, Lieferung 25.08.) statt MF60T. Panel-mount mit Kabel → kein PCB-Footprint mehr, Deck ~4–5 cm höher. Spec/BOM/Bestellnotiz nachgezogen, Charakterisierungs-Task neu

- B2 entschieden: Amazon-first für alle Module (Prime), Mouser nur für den N16R8, Reichelt-Kleinkram nach Inventur. Einkaufsliste mit Prüfkriterien im Bestellvorschlag

## Sessions
- start 22:08
- ende 22:33 (25 min)

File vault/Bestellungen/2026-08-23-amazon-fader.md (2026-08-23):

# 2026-08-23 — Amazon.de (Fader)

**Zweck:** Motorfader für das Deck. **Status:** bestellt (Leon, 23.08. ~23:00). **Lieferung:** Di 25.08. (Prime)

| Pos | Artikel | Stück | Preis | Summe |
|---|---|---|---|---|
| 1 | Behringer X32 MOTOR FADER Set (5× 100 mm Motorfader, X32-Ersatzteil) | 1 Set | 39,32 € | 39,32 € |

## Notizen
- Entscheidung statt MF60T (60 mm): panel-mount mit Kabeln → kein PCB-Footprint, Prime statt US-Import, 30 Tage Retour als Absicherung. Deck wird dafür ~4–5 cm höher.
- Nach Lieferung **Charakterisierung vor dem Layout**: Kabel-Pinout (Motor / Schleifer / Touch), Motorspannung und Strom bei 5 V (Anlauf/Stall), Rahmenmaße + Schraubpunkte → `vault/Hardware/Fader-X32.md`
- Foto vom Auspacken für die Case-Study machen!

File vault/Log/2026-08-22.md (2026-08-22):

---
datum: 2026-08-22
dauer_min: 112
---
# 2026-08-22

## Was ist passiert
- Projektstart: Grilling (18 Fragen), Design-Spec, Plan Phase 0–2, Repo-Infrastruktur mit Hooks, Vault, Logo, erster Push
- Bisherige Projekte analysiert (Stil, Toolchain, Konventionen) → Grundlage für CLAUDE.md
- FaderBuddy untersucht: I²C-Fader-Modul (ATtiny1616, DRV8837, Behringer MF60T, SMD). Entscheidung: Verhalten übernehmen, eigene einfache Regelung auf dem S3, MF60T als Fader
- SmartKnob (motorisierter Knopf) bewusst nicht in v1 — Roadmap
- Claude-Code-Hook-Fakten gegen Doku verifiziert → [[Apps/Claude-Hooks]]; `PermissionRequest` ist das richtige Ereignis für die Taste
- Pin-Map erstrechnet (Spec §2.3), morgen gegen Datenblatt/DevKit-Schaltplan prüfen (Plan Task 7)
- Offen für morgen: Bauteilwahl (Task 8–10), dann KiCad (Task 11+). Leon reicht die Skizze nach.
- Lizenz: MIT für Code gesetzt; Hardware-Lizenz (CERN-OHL-P?) ist Leons Entscheidung

## Sessions
- start 21:29
- ende 23:21 (112 min)

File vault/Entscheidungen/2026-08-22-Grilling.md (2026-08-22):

# Grilling 2026-08-22 — 18 Entscheidungen

Jede Frage: Optionen, Claudes Empfehlung, Leons Antwort, Begründung. Spec: [docs/superpowers/specs/2026-08-22-desk-mate-design.md](../../docs/superpowers/specs/2026-08-22-desk-mate-design.md)

## 1 · v1-Umfang
Optionen: (a) nur Claude-Ampel, (b) nur Fader-Deck, (c) nur Wall-E, (d) alles. Empfehlung (a). **Leon: (d)** — „wir haben Erfahrung“. Dazu: PCB möglichst in einer Revision, ESPs gesteckt, Arduino-Box nach dem Urlaub inventarisieren, Reihenfolge Plan → KiCad → Teile → JLCPCB (Sponsoring dokumentieren) → Rest.

## 2 · Was dreht sich auf dem Stepper?
(a) nur Bauch+Kopf, (b) alles inkl. Deck, (c) kein Körper-Stepper, Kopf Pan/Tilt per Servo. Empfehlung (c). **Leon: (c).** Stepper-Treiber-Sockel bleibt unbestückte Reserve.

## 3 · Welcher ESP?
(a) ein S3, (b) klassischer WROOM (nur BLE-HID), (c) S3 + zweiter ESP. Empfehlung (a). **Leon: (c)** mit C3 SuperMini per ESP-NOW → siehe 4.

## 4 · S3 ↔ C3
(a) UART, (b) ESP-NOW, (c) beides vorsehen. Empfehlung (c) mit UART primär. **Leon: C3 weglassen** — UART hatte beim VVVF-Board nie funktioniert (Baud/Puffer). Ergebnis: ein S3; C3-Footprint mit Lötjumpern als Reserve.

## 5 · Zentrale
(a) Desktop-Agent ist Hub, (b) Gerät ist Hub, (c) Hybrid. Empfehlung (a). **Leon: (c)**, Gerät muss auch standalone gehen.

## 6 · Standalone
(a) BLE-HID + Gesicht, kein WiFi, (b) + WiFi (MQTT/OTA/NTP), (c) minimal. Empfehlung (a). **Leon: (b)** + Wetter + Haus-Einbindung (Wetterstation mitteln, Kühler, Steckdosen). Kein HA-Server nötig: HiveMQ-MQTT wie beim Kühler.

## 7 · Fader-Regelung
(a) FaderBuddy nachfertigen (JLCPCB-PCBA), (b) eigene Regelung auf dem S3, (c) Mix. Empfehlung (a). **Leon: (b)** — einfache Ansteuerung. Video (FaderBuddy-Intro) als Verhaltensvorlage; Fader MF60T, Treiber DRV8833-Breakout.

## 8 · Fader-Anzahl
(a) 2, (b) 4, (c) 2 bestückt / 4 vorgesehen. Empfehlung (a). **Leon: (c).** Folge: Schleifer nur ADC1, Pin-Budget eng → MCP23017 für Tasten.

## 9 · Display
(a) ein rundes GC9A01, (b) zwei als Augen, (c) rechteckig 2,0", (d) CYD als Bauch. Empfehlung (a) + zweiter Header. **Leon: zwei runde Augen + großes Bauch-Display + Tasten + Drehencoder.** Arbeitsannahme Bauch: 2,8" ILI9341.

## 10 · Tasten
(a) 6 Soft-Keys + Encoder, (b) 2×4 Stream-Deck, (c) 6 + 4 + Encoder. Empfehlung (a). **Leon: (c)**, kostengünstig. SmartKnob (motorisierter Knopf mit Display) → nicht v1, Roadmap; EC11 für v1.

## 11 · Strom
(a) ein USB-C, (b) zwei USB-C (Daten/Strom), (c) USB-C + Hohlstecker. Empfehlung (b). **Leon: (b).**

## 12 · Kopf
(a) 2× MG90S, (b) 2× 28BYJ-48, (c) nur Tilt. Empfehlung (a). **Leon: (a).**

## 13 · Claude-Integration
(a) Hooks für Status + Hook-Freigabe, (b) nur Status + Tastendruck, (c) Terminal-Text lesen. Empfehlung (a). **Leon: (a)**, aber generisch: auch Browser-Downloads, Steam usw. → Agent mit Ereignisquellen (Downloads-Watcher, Steam-ACF, HTTP-Endpunkt).

## 14 · Desktop-Agent
(a) Swift-Menüleiste im Xcode-Projekt der iOS-App + Windows-Python-Tray, (b) Python für beide, (c) Tauri. Empfehlung (a). **Leon: (a).** Hebel: S3 als Composite-HID mit Gamepad → LS-Achsen unter Windows ohne Agent.

## 15 · Fernzugriff
(a) MQTT über HiveMQ, (b) Tailscale, (c) eigener Server. Empfehlung (a). **Leon: (a) + (c)** — Server nur für APNs-Push (Vercel + Supabase).

## 16 · Vault
(a) im Repo `vault/`, (b) separat, (c) bestehenden erweitern. Empfehlung (a). **Leon: (a).** Arbeitszeit über SessionStart/End-Hooks.

## 17 · Push
(a) SessionEnd-Hook commit+push, öffentlich ab Commit 1, (b) manuell, (c) nur bei grünem Build. Empfehlung (a). **Leon: (a).**

## 18 · Platinen
(a) eine Platine, (b) Frontpanel + Mainboard, (c) + Augen-Adapter. Empfehlung (c) (= a + Adapter). **Leon: (b) + (c)** → drei Designs, eine Bestellung. Folge: Touch über MPR121 auf dem Frontpanel, IDC 2×15.

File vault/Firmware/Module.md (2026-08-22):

# Firmware-Module

Siehe Spec §3: `hid` · `link` · `net` · `face` · `motion` · `io` · `state` · `config`. Ein Sketch, je Modul `.cpp/.h`, kein Framework. Host-Tests für `link` und `state`.

Pflichtregeln: NimBLE, `WiFi.setSleep(false)`, Panels direkt zeichnen, Watchdog, keine Structs in `.ino`-Signaturen, Protokollversion bei jeder Änderung.

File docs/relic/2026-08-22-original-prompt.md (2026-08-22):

# Desk-Mate — Der Ursprungs-Prompt (Relikt)

> Unverändert gesichert am 2026-08-22, 21:30. Zum Zurückschauen, wenn man ganz tief drinnen ist.

## Nachricht 1

hey finaly ist mir ein neues projekt eingefallen mit 3d druck und pcb design und löten, ich nenne es Desk-Mate das ist was großes ich will von anfang an proffesionell arbeiten ich möchte probleme und unnötigen aufwand durch überkomplizierung vermeiden zudem möchte ich dass du alle nötigen skills ladest füpr den plan auch grill me und verwendest, in der nächsten nachricht erkläre ich dir dann konkret was abgeht

## Nachricht 2

ahja projekt auf website und projekt opensource auf github automatisch pushen, dokumentiere von anfang an mit arbeitszeit updates datume arbeitszeit alles in ein obsidian vault und eine claude.md dass er das alles allein in künftigen chats macht, so also deskmate so eine hilfestellung sein die die workflows der menschen individuell unterstützt wichtig ist individualisierbarkeit, intuitiv zu nutzen und design, eine anwendung soll zum Beispiel sein ich schreibe einen langen prompt in claude terminal und und schick ab dann switch ich tabs und schreib was anderes oder tu gar was anderes deskmate soll falls claude aufwand brauch dich benachritigen wie eine ampel so oft fragt ja claude noch do you trust this folder oder stellt fragen du wartest bis es fertig ist dabei tut er nix das soll per claude skill gehen und da deskmate wireless oder per kabel oder per bluetooth verbunden werden soll und auch als tastatur erkannt werden soll kann man dann auch aus der ferne per mobile app sagen mach weiter oder so und man sieht den aktuellen screen vl kann man auch machen dass er lernt wie du tickst arbeitszeiten und so automatisch die motiviert süß ist so ein kleiner art wall e ich schick dir dann ein bild zudem eben viel können zb ich lad was aufs steam runter und frag per handy app wie lang der download noch läuft ich will cross platform in erster linie ios mac os windows sein in zukunft watch os ipad os und android, mann soll es wie gesagt customizen können unten tasten haben die belegen können links rechts wie in der zeichnung fader motorized die man customizen kann ich hab da cooles github repo dazu schon https://github.com/scottbez1/FaderBuddy das ist ganz cool ich hab zureit keinen server daheim der homeassitant hostet aber dass man kompabilität damit im hinterkopf behält... was auch cool wär dass mann die fader auf windows nicht nur für lautstärke verwenden kann sondern auch zum beispiel in ls zum hydraulik rauf runter oder so und eben wichtig gleich logo anleitung usw alles dass man dann schön die arbeit nachvollziehen kann analysiere meine bisherigen projekte ordner nach meinem style und flow /Users/leonfrohlich/Claude/Projects und jetzt zu dem design eine base mit arduino stepper rotatable darüber eine art streamdeck mit den fadern dann eine art wall e/baymax bauch und oben der kopf cool wär irgendwie schön tiltable und rotateble wenn das schön geht irgendwo schönes display mit tasten und controlls dafür pcb schön einfach aufbaubar ohne smd wenns geht case 3d druck alles mit anletiung und merk dir den prompt irgendwo so als relikt wenn ich dann ganz tief drinnen bin zum zurückschauen architektur wär ganz cool esp32 in arduino ide dann xcode und android studio

*(Skizze war angehängt, kam aber nicht an — wird nachgereicht.)*

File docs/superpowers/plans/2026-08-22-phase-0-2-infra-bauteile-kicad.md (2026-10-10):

# Desk-Mate — Plan Phase 0–2: Infrastruktur · Bauteilwahl · KiCad bis JLCPCB-Bestellung

> **For agentic workers:** REQUIRED SUB-SKILL: Use superpowers:subagent-driven-development (recommended) or superpowers:executing-plans to implement this plan task-by-task. Steps use checkbox (`- [ ]`) syntax for tracking.

**Goal:** Repo mit automatischer Doku/Zeiterfassung/Push steht, die Stückliste ist gegen Leons Bestand abgeglichen und bestellt, und drei KiCad-Designs (Mainboard, Frontpanel, Augen-Adapter) sind ERC/DRC-sauber als eine JLCPCB-Bestellung abgeschickt.

**Architecture:** Drei Through-Hole-Platinen um einen gesteckten ESP32-S3-DevKitC-1; alle Intelligenz im S3, Tasten/Touch über I²C-Expander auf dem Frontpanel, Motortreiber als Breakouts auf dem Mainboard. Doku lebt im Repo (`vault/` = Obsidian), Arbeitszeit und Push laufen über Claude-Code-Session-Hooks.

**Tech Stack:** git + gh (Kalilinuxloverr/Desk-Mate) · KiCad 10 (`/Applications/KiCad/KiCad.app/Contents/MacOS/kicad-cli` für ERC/DRC/Export) · arduino-cli (ab Phase 3) · sh-Skripte ohne Abhängigkeiten · Obsidian.

**Spec:** `docs/superpowers/specs/2026-08-22-desk-mate-design.md`

## Global Constraints

- Eine JLCPCB-Bestellung, kein Re-Spin: jede Platine wird vor Gerber-Export gegen Spec §2.2–2.5 geprüft.
- Kein Hand-SMD: nur THT-Bauteile oder gesteckte Breakouts/Module.
- Ein ESP32-S3 DevKitC-1 N16R8, gesteckt; Pin-Map exakt nach Spec §2.3 (Schleifer nur ADC1 GPIO 1–10; 0/3/45/46 nie als Funktion außer 45 per Lötjumper; 19/20 USB; 26–37 tabu; 43/44 frei lassen).
- Sprache: Doku/Commits/Kommentare Deutsch, Bezeichner/Netznamen/JSON Englisch. Commits: Satzform, ergebnisorientiert, kein Präfix.
- Secrets nie im Repo: `secrets.h`, `.env`, `*.local.xcconfig` in `.gitignore`; `tools/check-secrets.sh` muss vor jedem Commit grün sein.
- Jede Session: Tagesblatt `vault/Log/YYYY-MM-DD.md` → Abschnitt „Was ist passiert“ ergänzen (Pflicht laut CLAUDE.md).
- Jede Task endet mit Commit. Pfade relativ zu `/Users/leonfrohlich/Claude/Projects/Desk-Mate`.

---

## Phase 0 — Infrastruktur (2026-08-22, Nacht)

### Task 1: Repo-Grundgerüst (git, .gitignore, LICENSE, README, CLAUDE.md)

**Files:**
- Create: `.gitignore`, `LICENSE`, `README.md`, `CLAUDE.md`
- Existing: `docs/relic/2026-08-22-original-prompt.md`, `docs/superpowers/specs/2026-08-22-desk-mate-design.md`, dieser Plan

**Interfaces:**
- Produces: Repo-Root als `$CLAUDE_PROJECT_DIR`; `CLAUDE.md` definiert Session-Pflichten, auf die Task 3 und 4 verweisen.

- [ ] **Step 1: git init mit Branch `main`**

```bash
cd /Users/leonfrohlich/Claude/Projects/Desk-Mate && git init -b main
```
Erwartung: `Initialized empty Git repository`.

- [ ] **Step 2: `.gitignore` schreiben**

```gitignore
# Secrets — nie committen (Kühler-Lektion: Passwörter im Initial-Commit)
secrets.h
**/secrets.h
.env
.env.*
*.local.xcconfig
Signing.local.xcconfig

# Obsidian: nur Konfiguration versionieren, nicht Arbeitszustand
vault/.obsidian/workspace*
vault/.obsidian/cache
vault/.trash/

# KiCad
*-backups/
*.kicad_prl
*.kicad_sch-bak
*.kicad_pcb-bak
_autosave-*
fp-info-cache
*.lck

# Build / Tools
build/
.build/
DerivedData/
*.xcodeproj
*.xcworkspace
.history/
__pycache__/
*.pyc
node_modules/
.vercel/

# macOS
.DS_Store
```

- [ ] **Step 3: LICENSE (MIT, Jahr 2026, Leon Fröhlich)** — Hardware-Lizenz (CERN-OHL-P) ist Leons Entscheidung, offener Punkt im Spec §8.

- [ ] **Step 4: README.md nach Leons Template** (H1 → Was → ASCII-Architektur → Pfadtabelle → Bauen). Inhalt: Kurzbeschreibung aus Spec-Einleitung, ASCII aus Spec §2.1, Pfadtabelle aus Spec §6, „Bauen“ vorerst nur `git config core.hooksPath tools/githooks` und `sh tools/test-check-secrets.sh` (weitere Build-Befehle kommen mit den Phasen dazu).

- [ ] **Step 5: CLAUDE.md** mit Abschnitten: Projekt (1 Absatz + Links Spec/Plan/Relikt) · Architektur (Kurzform Spec §2–5) · Build & Test (aktuell: Secret-Check-Test; Platzhalterfrei: nur Befehle, die existieren) · **Bekannte Fallen (teuer erkauft — nicht wieder reintappen!)** (Startbestand aus dem Kühler-Log, soweit auf S3/Desk-Mate übertragbar: ADC2+WiFi, `WiFi.setSleep(false)`, NimBLE, `.ino`-Prototyp-Fallen, Struct-Änderung = Protokollversion, Secrets im Initial-Commit, UART-Baud/Puffer-Lektion aus VVVF) · Konventionen (Sprache, Commits, Dateinamen, Pin-Map ist im Spec die einzige Wahrheit bis `firmware/.../pins.h` existiert) · **Session-Pflichten** (Tagesblatt pflegen, Entscheidungen in `vault/Entscheidungen/`, Bestellungen in `vault/Bestellungen/`, Relikt nie anfassen, vor „fertig“ Tests laufen lassen, Memory ist kein Ersatz für den Vault).

- [ ] **Step 6: Commit**

```bash
git add -A && git commit -m "Projektstart Desk-Mate: Spec, Plan, Relikt, README, CLAUDE.md"
```

### Task 2: Secret-Check als Pre-Commit-Hook (mit Test)

**Files:**
- Create: `tools/check-secrets.sh`, `tools/githooks/pre-commit`, `tools/test-check-secrets.sh`

**Interfaces:**
- Produces: `tools/check-secrets.sh` — Exit 0 = sauber, Exit 1 = Fund (Ausgabe: Datei:Zeile). Prüft nur gestagte Dateien. Wird von Task 3 (`session-end.sh`) aufgerufen.

- [ ] **Step 1: Test schreiben** (`tools/test-check-secrets.sh`)

```sh
#!/bin/sh
# Einziger Test für check-secrets.sh: ein echtes Secret muss blocken, ein Platzhalter nicht.
set -e
here="$(cd "$(dirname "$0")" && pwd)"
tmp="$(mktemp -d)"; trap 'rm -rf "$tmp"' EXIT
cd "$tmp" && git init -q -b main && git config user.email t@t && git config user.name t
cp "$here/check-secrets.sh" .

printf 'password = "<hunter2hunter2>"\n' > leak.txt && git add leak.txt
if sh check-secrets.sh >/dev/null 2>&1; then echo "FAIL: Secret nicht erkannt"; exit 1; fi
git rm -q --cached leak.txt

printf 'password = "CHANGEME"\nmqtt_token: ${MQTT_TOKEN}\n' > ok.example.h && git add ok.example.h
printf 'Gerätetokens liegen in Supabase. Kein Token hier.\n' > doku.md && git add doku.md
sh check-secrets.sh || { echo "FAIL: Platzhalter/Doku fälschlich geblockt"; exit 1; }
echo "OK: check-secrets"
```

- [ ] **Step 2: Test laufen lassen → muss fehlschlagen** (`sh tools/test-check-secrets.sh` → „check-secrets.sh: No such file“).

- [ ] **Step 3: `tools/check-secrets.sh`**

```sh
#!/bin/sh
# Blockt Commits mit echten Zugangsdaten. Prüft nur gestagte Dateien.
# ponytail: grep statt gitleaks; gitleaks nachrüsten, wenn das hier mal durchrutscht.
cd "$(git rev-parse --show-toplevel)" || exit 1
files=$(git diff --cached --name-only --diff-filter=ACM | grep -v -E '\.example\.|^tools/(check-secrets|test-check-secrets)\.sh$|^docs/relic/' || true)
[ -z "$files" ] && exit 0
pattern='(ssid|password|passwd|token|api[_-]?key|secret)[[:space:]]*[=:][[:space:]]*["'"'"']?[A-Za-z0-9_./@!$%+-]{8,}'
hits=$(printf '%s\n' "$files" | xargs grep -n -i -E "$pattern" 2>/dev/null \
  | grep -v -i -E 'changeme|example|platzhalter|your[_-]|<[^>]+>|\$\{|\$[A-Z_]+|process\.env|getenv|xxxx' || true)
if [ -n "$hits" ]; then
  echo "check-secrets: mögliche Zugangsdaten — Commit abgebrochen:"
  echo "$hits"
  exit 1
fi
exit 0
```

- [ ] **Step 4: Pre-Commit-Hook** (`tools/githooks/pre-commit`)

```sh
#!/bin/sh
exec sh "$(git rev-parse --show-toplevel)/tools/check-secrets.sh"
```

- [ ] **Step 5: ausführbar machen, Hook-Pfad setzen, Test grün**

```bash
chmod +x tools/*.sh tools/githooks/pre-commit
git config core.hooksPath tools/githooks
sh tools/test-check-secrets.sh
```
Erwartung: `OK: check-secrets`.

- [ ] **Step 6: Commit** — `git add tools && git commit -m "Secret-Check als Pre-Commit-Hook, mit Test"`

### Task 3: Zeiterfassung + Auto-Push über Claude-Code-Session-Hooks

**Files:**
- Create: `tools/session-start.sh`, `tools/session-end.sh`, `.claude/settings.json`, `tools/test-session-hooks.sh`

**Interfaces:**
- Consumes: `tools/check-secrets.sh` (Task 2).
- Produces: Tagesblatt-Format `vault/Log/YYYY-MM-DD.md`:
  ```
  ---
  datum: 2026-08-23
  dauer_min: 0
  ---
  # 2026-08-23

  ## Was ist passiert
  - 

  ## Sessions
  - start 09:12
  - ende 10:40 (88 min)
  ```
  Claude schreibt Bullet-Punkte unter „Was ist passiert“; der erste nicht-leere wird Commit-Betreff.

- [ ] **Step 1: Test** (`tools/test-session-hooks.sh`)

```sh
#!/bin/sh
# Start legt Tagesblatt an, Ende rechnet Minuten und summiert dauer_min. Kein git im Test (NO_GIT=1).
set -e
here="$(cd "$(dirname "$0")" && pwd)"
tmp="$(mktemp -d)"; trap 'rm -rf "$tmp"' EXIT
export CLAUDE_PROJECT_DIR="$tmp" NO_GIT=1 FAKE_NOW="09:00"
sh "$here/session-start.sh"
log="$tmp/vault/Log/$(date +%Y-%m-%d).md"
grep -q '^- start 09:00$' "$log" || { echo "FAIL: start fehlt"; exit 1; }
FAKE_NOW="10:30" sh "$here/session-end.sh"
grep -q '^- ende 10:30 (90 min)$' "$log" || { echo "FAIL: ende/minuten"; cat "$log"; exit 1; }
grep -q '^dauer_min: 90$' "$log" || { echo "FAIL: dauer_min"; cat "$log"; exit 1; }
FAKE_NOW="11:00" sh "$here/session-start.sh"; FAKE_NOW="11:10" sh "$here/session-end.sh"
grep -q '^dauer_min: 100$' "$log" || { echo "FAIL: Summe"; cat "$log"; exit 1; }
echo "OK: session-hooks"
```

- [ ] **Step 2: Test laufen lassen → fehlschlägt** (Skripte fehlen).

- [ ] **Step 3: `tools/session-start.sh`**

```sh
#!/bin/sh
# Claude-Code-Hook SessionStart: Tagesblatt anlegen (falls neu) und Startzeit eintragen.
root="${CLAUDE_PROJECT_DIR:-$(cd "$(dirname "$0")/.." && pwd)}"
day="$(date +%Y-%m-%d)"; now="${FAKE_NOW:-$(date +%H:%M)}"
log="$root/vault/Log/$day.md"
mkdir -p "$(dirname "$log")"
if [ ! -f "$log" ]; then
  printf -- '---\ndatum: %s\ndauer_min: 0\n---\n# %s\n\n## Was ist passiert\n- \n\n## Sessions\n' "$day" "$day" > "$log"
fi
printf -- '- start %s\n' "$now" >> "$log"
exit 0
```

- [ ] **Step 4: `tools/session-end.sh`**

```sh
#!/bin/sh
# Claude-Code-Hook SessionEnd: Endzeit + Dauer eintragen, dauer_min summieren, committen und pushen.
# ponytail: Sessions über Mitternacht werden dem Starttag zugerechnet und negative Dauer auf 0 gesetzt.
root="${CLAUDE_PROJECT_DIR:-$(cd "$(dirname "$0")/.." && pwd)}"
day="$(date +%Y-%m-%d)"; now="${FAKE_NOW:-$(date +%H:%M)}"
log="$root/vault/Log/$day.md"
[ -f "$log" ] || sh "$root/tools/session-start.sh"
start="$(grep -E '^- start [0-9]{2}:[0-9]{2}$' "$log" | tail -1 | awk '{print $3}')"
mins() { echo "$1" | awk -F: '{print $1*60+$2}'; }
dur=$(( $(mins "$now") - $(mins "$start") )); [ "$dur" -lt 0 ] && dur=0
printf -- '- ende %s (%s min)\n' "$now" "$dur" >> "$log"
total="$(grep -oE '\([0-9]+ min\)' "$log" | tr -dc '0-9\n' | awk '{s+=$1} END{print s+0}')"
sed -i '' "s/^dauer_min: .*/dauer_min: $total/" "$log"
[ -n "$NO_GIT" ] && exit 0
cd "$root" || exit 0
git add -A
sh tools/check-secrets.sh || { echo "session-end: Secrets gefunden, kein Commit" >> "$log"; exit 0; }
summary="$(awk '/^## Was ist passiert/{f=1;next} /^## /{f=0} f && /^- ./{sub(/^- /,""); print; exit}' "$log")"
git commit -q -m "Session $day $now: ${summary:-Arbeitsstand}" || exit 0
git push -q origin HEAD 2>>"$root/vault/Log/push-fehler.log" || true
exit 0
```

- [ ] **Step 5: `.claude/settings.json`**

```json
{
  "hooks": {
    "SessionStart": [
      { "matcher": "startup|resume|clear",
        "hooks": [ { "type": "command", "command": "sh \"$CLAUDE_PROJECT_DIR/tools/session-start.sh\"", "timeout": 10 } ] }
    ],
    "SessionEnd": [
      { "hooks": [ { "type": "command", "command": "sh \"$CLAUDE_PROJECT_DIR/tools/session-end.sh\"", "timeout": 120 } ] }
    ]
  }
}
```

- [ ] **Step 6: Test grün** — `chmod +x tools/*.sh && sh tools/test-session-hooks.sh` → `OK: session-hooks`.

- [ ] **Step 7: Commit** — `git add tools .claude && git commit -m "Zeiterfassung und Auto-Push ueber Session-Hooks, mit Test"`

### Task 4: Obsidian-Vault anlegen und heutige Session dokumentieren

**Files:**
- Create: `vault/Index.md`, `vault/Log/2026-08-22.md`, `vault/Entscheidungen/2026-08-22-Grilling.md`, `vault/Hardware/Pin-Map.md`, `vault/Apps/Claude-Hooks.md`, `vault/Bestellungen/README.md`, `vault/.obsidian/app.json`

- [ ] **Step 1: Struktur + Index** — `Index.md` mit Wikilinks auf alle Bereiche und auf Spec/Plan/Relikt (relative Markdown-Links, da außerhalb des Vaults).
- [ ] **Step 2: Tagesblatt 2026-08-22 von Hand** (Start 21:29 — Hook existierte noch nicht): „Was ist passiert“ = Grilling 18 Fragen, Spec, Plan, Infrastruktur; Sessions `- start 21:29` / `- ende HH:MM (N min)` mit echter Uhrzeit, `dauer_min` passend.
- [ ] **Step 3: Entscheidungsnotiz** — die 18 Fragen mit Optionen, Antwort, Begründung (aus dem Chat), je Abschnitt `[[…]]`-Links auf Hardware/Firmware/Apps-Notizen.
- [ ] **Step 4: `Hardware/Pin-Map.md`** — verweist auf Spec §2.3 als einzige Wahrheit bis Task 7 die verifizierte Version hier ablegt.
- [ ] **Step 5: `Apps/Claude-Hooks.md`** — verifizierte Hook-Fakten (Ereignisliste, `PermissionRequest`-Antwort-JSON, Notification-Typen, offene Punkte Timeout/AskUserQuestion), Quelle + Datum.
- [ ] **Step 6: `Bestellungen/README.md`** — Vorlage je Bestellung (Datum, Lieferant, Positionen, Kosten, Lieferzeit, Tracking, Fotos, Sponsoring-Hinweis).
- [ ] **Step 7: Commit** — `git add vault && git commit -m "Obsidian-Vault mit Tagesblatt, Entscheidungen und Hook-Fakten"`

### Task 5: Logo

**Files:**
- Create: `docs/logo/deskmate.svg`, `docs/logo/README.md`

- [ ] **Step 1: SVG** — 256×256, abgerundetes Quadrat (Körper) in Anthrazit, zwei runde Augen (weiß, Pupille türkis #2EC4B6), darunter ein Ampel-Punkt (grün #3DDC84). Nur Pfade/Kreise, keine Schrift, keine externen Fonts. Wortmarke „Desk-Mate“ separat als Text-SVG `deskmate-wordmark.svg` (Systemfont, da Logo-Fonts Lizenzfragen bringen).
- [ ] **Step 2: Sichtprüfung** — `qlmanage -p docs/logo/deskmate.svg` oder im Browser öffnen; README im Vault verlinkt das SVG.
- [ ] **Step 3: Commit** — `git add docs/logo && git commit -m "Logo als SVG"`

### Task 6: GitHub-Repo anlegen und pushen

- [ ] **Step 1:** `gh repo create Kalilinuxloverr/Desk-Mate --public --source=. --remote=origin --description "Wall-E-artiger Schreibtisch-Begleiter: Ampel fuer Claude Code & Downloads, Motorfader, Augen-Displays. ESP32-S3, Swift, KiCad, 3D-Druck." --push`
- [ ] **Step 2:** `git remote -v` zeigt `https://github.com/Kalilinuxloverr/Desk-Mate.git`; `gh repo view --web` optional.
- [ ] **Step 3:** Tagesblatt-Eintrag „Repo öffentlich, erster Push“ — Commit über `tools/session-end.sh` ist ab der nächsten Session automatisch.

---

## Phase 1 — Bauteilwahl (ab 2026-08-23)

### Task 7: Pin-Map verifizieren und als `pins.h` festschreiben

**Files:**
- Create: `firmware/arduino/deskmate/pins.h`, `vault/Hardware/Pin-Map.md` (ersetzt Verweis), `tools/test-pins.sh`

**Interfaces:**
- Produces: `pins.h` mit `constexpr int PIN_<NAME> = <gpio>;` für alle Einträge aus Spec §2.3 (Namen exakt wie dort: `PIN_FADER1_WIPER`, `PIN_FADER1_PWM`, `PIN_FADER1_DIR`, …, `PIN_SERVO_PAN`, `PIN_SERVO_TILT`, `PIN_SPI_MOSI`, `PIN_SPI_SCK`, `PIN_SPI_DC`, `PIN_CS_BELLY`, `PIN_CS_EYE_L`, `PIN_CS_EYE_R`, `PIN_I2C_SDA`, `PIN_I2C_SCL`, `PIN_IO_INT`, `PIN_WS2812_DATA`, `PIN_PSU_SENSE`, `PIN_BELLY_BL_PWM`). Alle Phase-3-Module greifen nur hierüber auf GPIOs zu.

- [ ] **Step 1: Quellen lesen** — ESP32-S3-Datenblatt (Strapping-Tabelle, ADC-Kanäle, GPIO 45/46/48-Verhalten) und ESP32-S3-DevKitC-1-Schaltplan (Espressif-Doku; Onboard-RGB-LED-Pin je Revision, welche Pins am Header liegen, USB-Pfad). Über WebFetch/Context7, Fundstellen mit URL in `vault/Hardware/Pin-Map.md` notieren.
- [ ] **Step 2: Abgleich** — jede Zeile aus Spec §2.3 gegen die Quellen: Pin am Header? Strapping? ADC1? Konflikt mit PSRAM (N16R8 = Octal → 35/36/37 belegt)? Ergebnis-Tabelle mit Spalte „verifiziert ✓/✗ + Quelle“. Abweichungen → Spec §2.3 anpassen (Spec bleibt Wahrheit) und Grund ins Tagesblatt.
- [ ] **Step 3: Test** (`tools/test-pins.sh`): prüft per `grep`/`awk`, dass in `pins.h` keine GPIO-Nummer doppelt ist, keine aus {0,3,19,20,26–37,43,44,46} vorkommt, `PIN_FADER*_WIPER` ∈ 1–10, und `PIN_BELLY_BL_PWM` nur mit Kommentar `// Loetjumper` erscheint. Vorher laufen lassen → fehlschlägt (Datei fehlt).
- [ ] **Step 4: `pins.h` schreiben** (ein `constexpr` pro Zeile, Kommentar mit Ziel/Hinweis aus der Tabelle).
- [ ] **Step 5: Test grün**, Commit: `Pin-Map gegen Datenblatt und DevKitC-1-Schaltplan verifiziert, pins.h`

### Task 8: Bestandsaufnahme Arduino-Box → `hardware/inventar.md`

- [ ] **Step 1:** Leon fotografiert/listet die Box (nach dem Urlaub). Claude legt `hardware/inventar.md` an: Tabelle `Bauteil | Anzahl | Zustand | Verwendbar für`.
- [ ] **Step 2:** Bekannt vorhanden eintragen: BME680-Breakout, WS2812-Breakout, C3 SuperMini (×?), CYD.
- [ ] **Step 3:** Commit.

### Task 9: Stückliste `hardware/bom.md` (Leons Format) mit Quellen, Preisen, Bestand

**Files:**
- Create: `hardware/bom.md`, `vault/Bestellungen/2026-08-xx-teile.md`

**Interfaces:**
- Produces: BOM-Tabelle `Ref | Bauteil | Gehäuse | Hinweis | Stück | Quelle | Preis | Bestand` — Referenzen (J1, U1, …) werden in Task 11–14 1:1 als KiCad-Referenzen verwendet.

- [ ] **Step 1: Kandidaten je Position mit Begründung** (Skill `bom` laden; Preise/Verfügbarkeit per WebFetch bei Reichelt/Mouser/AliExpress/Amazon.de, Stand mit Datum):
  - ESP32-S3-DevKitC-1-N16R8 (Espressif-Original bevorzugen, Revision notieren)
  - 2× Behringer MF60T (5er-Pack), 2× DRV8833-Breakout (Pololu-kompatibel, 2 Kanäle)
  - 2× GC9A01 1,28" (7-Pin-Modul), 1× ILI9341 2,8" SPI 14-Pin ohne Touch
  - 2× MG90S, Pan-Tilt-Halter (Druckteil oder Kit)
  - MCP23017 DIP-28 (+ Sockel), MPR121-Breakout, BME680 (vorhanden)
  - 10× MX-Schalter (Outemu/Gateron), 10× Hot-Swap-Sockel (Kailh, falls Footprint THT-tauglich — sonst direkt löten), 10× Blank-Keycaps DSA
  - EC11 mit Taster + Knopf
  - 2× USB-C-Buchse 16-Pin THT-Befestigung (z. B. GCT USB4085-GF-A oder kompatibel), 2× 5,1 kΩ
  - Versorgung: 2× P-FET TO-220 (z. B. IRF9540N-Alternative mit niedrigem Rds(on); oder 1× Dual-Schottky SB540-Paar) — Entscheidung hier treffen und im Spec §8 Punkt 3 schließen
  - LD1117V33 TO-220, Polyfuse 3 A (RUEF300), Elkos 1000 µF ×2, 470 µF, 100 µF ×2, 100 nF ×10, 10 µF ×4
  - IDC 2×15 Stift + Buchse + Flachband 30-polig (30 cm), JST-XH 3-Pin ×3 + Kabel
  - WS2812-Ring 12 (vorhanden prüfen), Buchsenleisten 1×22 ×2, 1×8 ×4, Stiftleisten
  - USB-C-Kabel, 5 V/3 A USB-C-Netzteil
- [ ] **Step 2: Gegen `inventar.md` abgleichen**, Spalte Bestand füllen; Gesamtkosten summieren.
- [ ] **Step 3: Bestellliste** je Lieferant als `vault/Bestellungen/<datum>-<lieferant>.md` (Vorlage aus Task 4). Leon bestellt; Claude trägt Bestelldatum/Tracking nach.
- [ ] **Step 4: Commit** — `Stueckliste mit Quellen und Preisen, Bestand abgeglichen`

### Task 10: Offene Spec-Punkte schließen (USB-Datenpfad, HiveMQ-Limit, Lizenz)

- [ ] **Step 1: USB-Datenpfad** — Schaltplan des DevKitC-1 lesen: liegen D+/D− (GPIO 19/20) am Header? Entscheidung: *Variante A* J_DATA → D+/D− direkt auf Header-Pins 19/20 mit ESD-Schutz (USBLC6-2 ist SMD → THT-Alternative: 2× 5,1 V-Zener BZX79 + 22 Ω Serie) oder *Variante B* internes USB-C-Kabel von der DevKit-USB-Buchse zur Gehäuserückwand (Panel-Mount-USB-C-Verlängerung, kein Layout nötig). **Empfehlung B** (kein Hochgeschwindigkeits-Layout auf dem Mainboard, keine ESD-Frage, DevKit bleibt frei flashbar); dann trägt J_DATA auf dem Mainboard nur 5 V. Ergebnis in Spec §2.2 + §8 eintragen.
- [ ] **Step 2: HiveMQ-Cloud-Free-Tier** — maximale Nachrichtengröße per WebFetch prüfen (HiveMQ-Doku); wenn < 256 KB → Screenshot-Breite 640 px, JPEG-Qualität 60; Wert in Spec §4 eintragen.
- [ ] **Step 3: Lizenz** — Leon fragen (MIT für Code + CERN-OHL-P-2.0 für `hardware/`?), Ergebnis in LICENSE/README.
- [ ] **Step 4: Commit** — `Offene Spec-Punkte USB-Pfad, HiveMQ-Limit, Lizenz geschlossen`

---

## Phase 2 — KiCad (drei Designs) bis JLCPCB-Bestellung

Werkzeug: KiCad 10 GUI für Schaltplan/Layout, `KICAD=/Applications/KiCad/KiCad.app/Contents/MacOS/kicad-cli` für Prüfungen und Export. Skill `kicad` laden, bevor Task 11 beginnt; jede Review-Runde mit dem Skill gegen Spec §2 fahren.

**Stand 2026-08-27:** Tasks 11–16 als Erstversion per Generator (`hardware/kicad/gen/`) erledigt — Bibliothek, drei Schaltpläne (ERC sauber), drei Layouts (Freerouting, DRC), `tools/test-kicad.sh`. Offen vor Task 17: Leons Freigabe der Frontpanel-Anordnung, Nachmessen der Module (Spec §8.8), Fader-Charakterisierung.
**Stand 2026-10-09:** Task 17 bis auf die Bestellung erledigt — Reserve gestrichen (04.10.), Platinenteile auf Reichelt umgestellt, Silkscreen, Frontpanel freigegeben, Fab-Export neu. Bestellliste: `vault/Bestellungen/2026-10-09-reichelt.md`. Fader-Charakterisierung bleibt nach Lieferung (PCB-unabhängig, Drähte).

### Task 11: KiCad-Projekte und Bibliothek anlegen

**Files:**
- Create: `hardware/kicad/mainboard/mainboard.kicad_pro` (+ `.kicad_sch`, `.kicad_pcb`), `hardware/kicad/frontpanel/…`, `hardware/kicad/eye-adapter/…`, `hardware/kicad/lib/deskmate.kicad_sym`, `hardware/kicad/lib/deskmate.pretty/`, `hardware/kicad/README.md`

- [ ] **Step 1: Drei Projekte** in KiCad 10 anlegen (2 Lagen, 1,6 mm, Default-Regeln JLCPCB: min. Leiterbahn 0,2 mm, Abstand 0,2 mm, Via 0,3/0,6 mm — als `.kicad_dru`).
- [ ] **Step 2: Projektbibliothek** — Symbole + Footprints, die KiCad nicht mitbringt oder die als Modul gesteckt werden: `ESP32-S3-DevKitC-1` (2× 1×22, 2,54 mm, Pinnamen = GPIO-Nummern), `DRV8833_Breakout` (2× 1×8-Reihen, Pololu-Raster), `MPR121_Breakout`, `BME680_Breakout`, `GC9A01_Module_7pin`, `ILI9341_2.8_14pin`, `MF60T` (Footprint aus FaderBuddy `electronics/` übernehmen, Maße gegen Datenblatt prüfen), `MX_Switch_THT_Hotswap`, `USB_C_16pin_THT`, `StepperDriver_Socket_A4988` (2× 1×8), `ESP32-C3_SuperMini` (2× 1×8).
- [ ] **Step 3: Prüfung** — für jeden Footprint: 3D-Modell oder zumindest Courtyard; Bohrdurchmesser THT ≥ 0,9 mm bei 2,54-mm-Stiften, ≥ 1,0 mm bei USB-C-Befestigung. `$KICAD fp export svg`-Stichprobe ansehen.
- [ ] **Step 4: Commit** — `KiCad-Projekte und Bibliothek fuer Mainboard, Frontpanel, Augen-Adapter`

### Task 12: Mainboard-Schaltplan (ERC sauber)

- [ ] **Step 1: Blätter** — Versorgung (J_DATA 5 V, J_PWR 5 V + CC-Widerstände, ODER-Stufe, Polyfuse, Bulk, LD1117V33 + 10 µF/100 nF, Testpunkte 5V/3V3/GND), MCU (DevKit-Sockel, alle Pins beschriftet nach `pins.h`, PSU_SENSE-Teiler 10 k/10 k, RESET/BOOT-Stecker), Motor (2× DRV8833-Sockel, IN1 = PWM, IN2 = DIR, 100 µF je VM, nSLEEP auf 3V3 über Jumper), Peripherie (2× Servo-JST + 470 µF + optional 10 Ω, WS2812-JST + 330 Ω + 1000 µF, BME680-Sockel, I²C-Pull-ups 4,7 kΩ), IDC 2×15 exakt nach Spec §2.4, Reserve (Stepper-Sockel mit Lötjumpern, C3-Footprint mit Lötjumpern).
- [ ] **Step 2: Netznamen** englisch und identisch zu `pins.h`-Namen ohne `PIN_` (z. B. `FADER1_PWM`, `SPI_MOSI`).
- [ ] **Step 3: ERC** — `$KICAD sch erc --severity-all --exit-code-violations hardware/kicad/mainboard/mainboard.kicad_sch` → Exit 0. Jede Ausnahme (z. B. unbenutzte Sockelpins) mit „No connect“-Flag, nicht per Regel unterdrücken.
- [ ] **Step 4: Review mit Skill `kicad`** gegen Spec §2.2/2.3/2.5 (Power-Tree, Pin-Map, Strompfad); Findings beheben oder begründet ins Tagesblatt.
- [ ] **Step 5: Commit** — `Mainboard-Schaltplan, ERC sauber`

### Task 13: Frontpanel-Schaltplan (ERC sauber)

- [ ] **Step 1:** 4× MF60T (Motor auf IDC MOT1–4, Schleifer über RC 1 kΩ/100 nF auf WIPER1–4, Touch-Pad auf MPR121 ELE0–3; Fader 3/4 als DNP markiert), 10× MX direkt auf MCP23017 GPA0–GPB1 mit internem Pull-up (Schalter nach GND), EC11 A/B/SW auf GPB2–4 + 10 nF Entprellung, MCP23017 (A0–A2 = GND → 0x20, RESET auf 3V3, INTA+INTB per Jumper auf IO_INT mit 10 kΩ Pull-up, INT als Open-Drain konfigurierbar), MPR121-Sockel (ADDR = GND → 0x5A, IRQ auf IO_INT), ILI9341-Steckleiste (VCC 3V3, GND, CS_BELLY, RESET ← MCP GPB5, DC, MOSI, SCK, LED ← Jumper: MCP GPB6 über Transistor BC337 oder BELLY_BL_PWM vom IDC), IDC 2×15 spiegelbildlich zu Task 12.
- [ ] **Step 2: ERC** wie Task 12, Exit 0.
- [ ] **Step 3: Review** mit Skill `kicad`; besonders: Backlight-Strom (ILI9341-LED-Pin zieht bis 150 mA → nie direkt aus MCP23017, immer Transistor).
- [ ] **Step 4: Commit** — `Frontpanel-Schaltplan, ERC sauber`

### Task 14: Augen-Adapter-Schaltplan + Layout

- [ ] **Step 1:** 10-Pin-Eingang (JST-XH 2,5 mm oder 2,54-Stift) → 2× 7-Pin-Buchse für GC9A01 (VCC, GND, SCL=SCK, SDA=MOSI, RES=DISP_RST, DC, CS_L/CS_R; BL-Pin falls Modul 8-polig). 100 nF je Modul.
- [ ] **Step 2:** ERC Exit 0, Layout 30 × 20 mm, DRC Exit 0 (`$KICAD pcb drc --severity-all --exit-code-violations …`).
- [ ] **Step 3: Commit** — `Augen-Adapter fertig (ERC/DRC sauber)`

### Task 15: Mainboard-Layout (DRC sauber)

- [ ] **Step 1: Platzierung** — DevKit am Rand mit Antenne über Platinenkante; USB-C-Buchsen an der Rückkante; DRV8833 nahe IDC; Bulk-Elko nahe ODER-Stufe; Montagelöcher 3,2 mm in den Ecken (Gehäuse-Referenz); Reserve-Sockel dort, wo sie keine Leiterbahnen der Hauptfunktion verlängern.
- [ ] **Step 2: Routing** — 5-V-Pfad ≥ 1,5 mm Leiterbahn (3 A), Motor-Leitungen ≥ 0,8 mm, Massefläche beidseitig, Schleifer-Leitungen weg von Motor-Leitungen, I²C kurz.
- [ ] **Step 3: DRC** Exit 0; 3D-Ansicht: DevKit-Antenne frei, USB-C-Stecker passen durch die spätere Rückwand (Abstand zur Kante notieren für `hardware/3d/`).
- [ ] **Step 4: Review** mit Skill `kicad` (DFM: Annular Rings, Bohrklassen, Silk-Lesbarkeit, Referenzen sichtbar). Beheben, Tagesblatt.
- [ ] **Step 5: Commit** — `Mainboard-Layout, DRC sauber`

### Task 16: Frontpanel-Layout (DRC sauber)

- [ ] **Step 1: Anordnung mit Leon abstimmen** (Skizze nachreichen!): Display oben mittig, 6 Soft-Keys darunter im 19,05-mm-Raster, je 2 Fader links/rechts (Fader 3/4 außen als DNP), 4 Makro-Keys + Encoder zwischen den Fadern. Maß der Frontblende daraus ableiten (→ `hardware/3d/`).
- [ ] **Step 2: Routing** wie Task 15; Touch-Leitungen zu den Fader-Kappen kurz und ohne Massefläche darunter (MPR121-Hinweis); Schleifer-RC nahe am Fader.
- [ ] **Step 3: DRC** Exit 0; 3D-Ansicht; Bohrungen für Display-Abstandshalter.
- [ ] **Step 4: Review** mit Skill `kicad`; Commit — `Frontpanel-Layout, DRC sauber`

### Task 17: Export, JLCPCB-Bestellung, Dokumentation

- [ ] **Step 1: Export je Projekt** — `$KICAD pcb export gerbers` + `drill`, Zip je Board in `hardware/kicad/<board>/fab/`; zusätzlich `$KICAD pcb export step` und ein PNG-Render für README/Vault.
- [ ] **Step 2: Gerber-Sichtprüfung** im JLCPCB-Viewer (Lagen, Umriss, Bohrungen) — Screenshot in `vault/Bestellungen/`.
- [ ] **Step 3: Bestellung** — drei Designs, je 5 Stück, 1,6 mm, HASL oder ENIG (Leon), Farbe (Leon). Leon bestellt über den Sponsoring-Account; `vault/Bestellungen/2026-xx-xx-jlcpcb.md` mit Positionen, Kosten, Lieferzeit, Bestellnummer. Leon informiert seinen JLCPCB-Kontakt (Erinnerung im Tagesblatt).
- [ ] **Step 4: README** — Abschnitt „Hardware“ mit Render + Link auf `hardware/kicad/`; `docs/anleitung/01-platinen.md` begonnen (Was bestellen, welche Dateien).
- [ ] **Step 5: Commit** — `Gerber/STEP exportiert, JLCPCB-Bestellung dokumentiert`; Tag `v0.1-pcb-bestellt`.

---
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

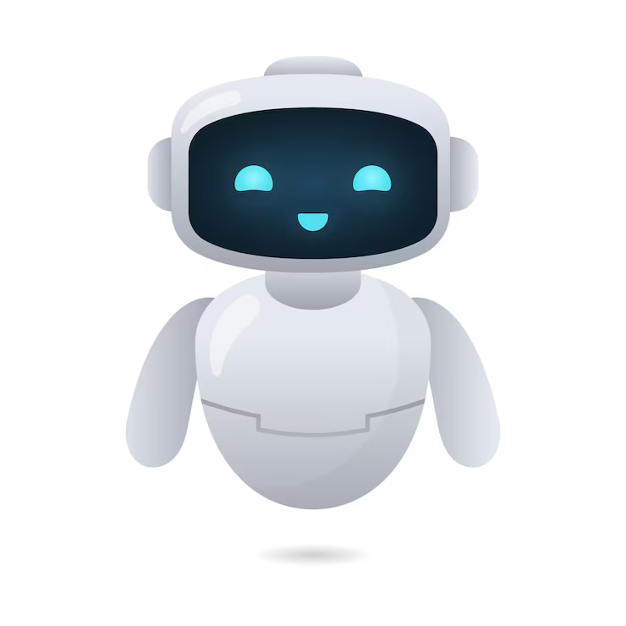
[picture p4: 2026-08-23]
docs/design/2026-08-23-referenz-roboter.png

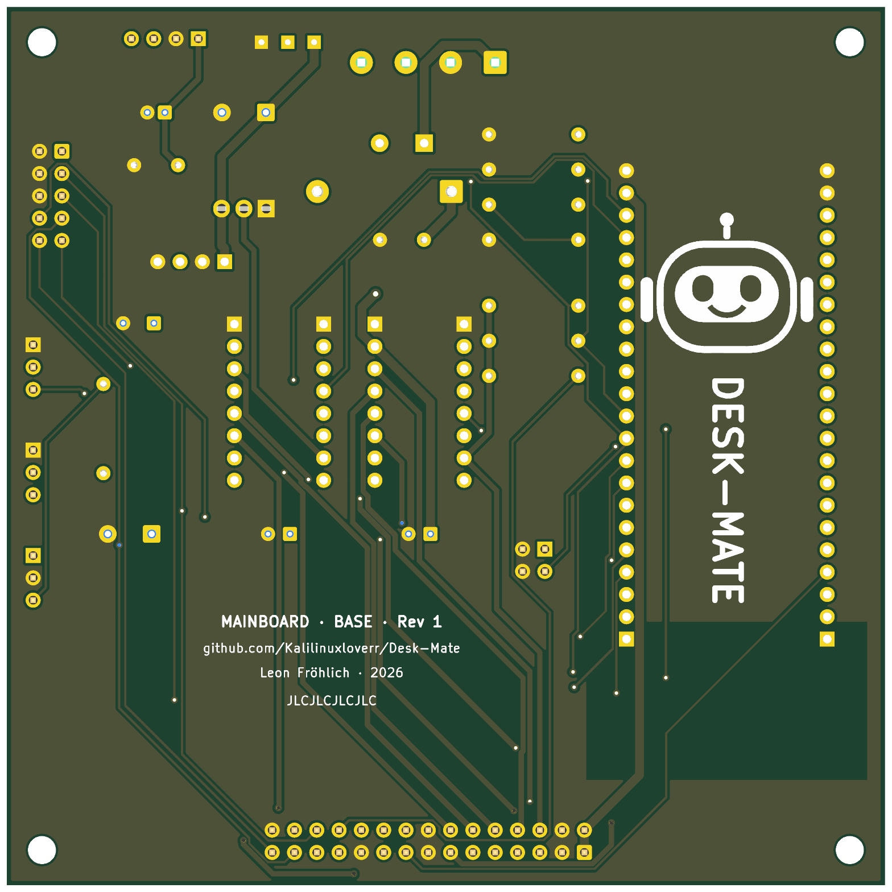
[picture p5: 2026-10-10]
hardware/kicad/mainboard/fab/mainboard-bottom.png

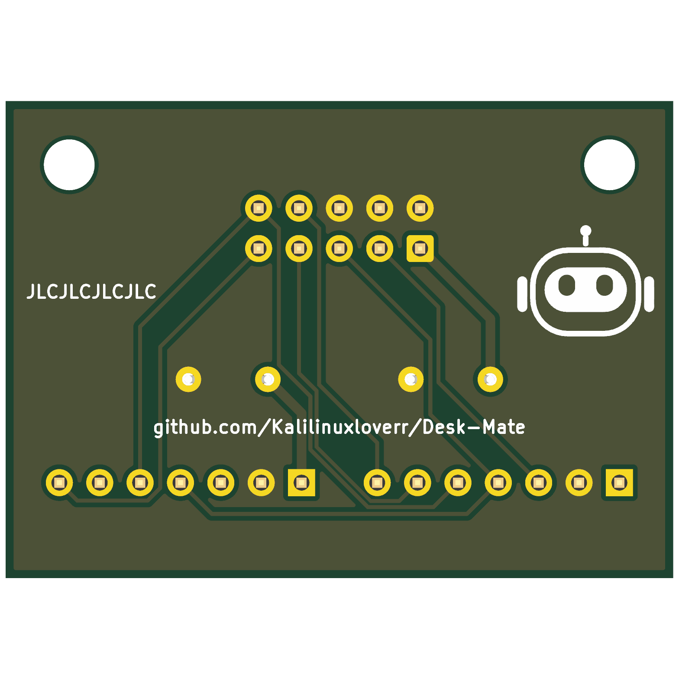
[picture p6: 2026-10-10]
hardware/kicad/eye-adapter/fab/eye-adapter-bottom.png

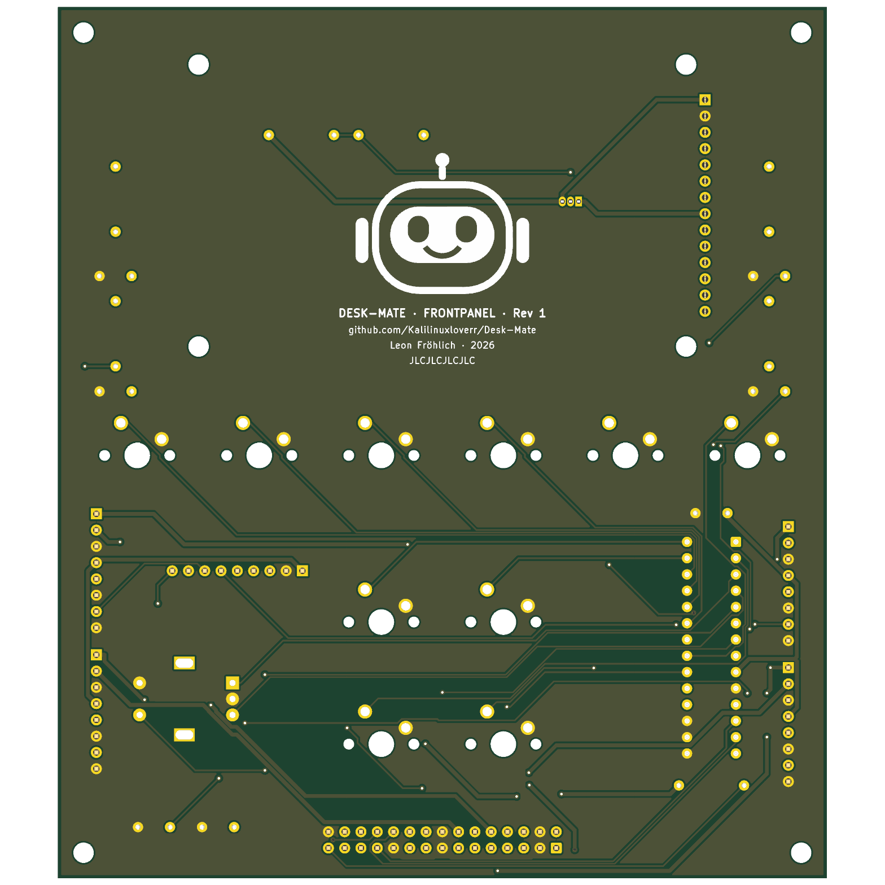
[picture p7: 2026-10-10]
hardware/kicad/frontpanel/fab/frontpanel-bottom.png

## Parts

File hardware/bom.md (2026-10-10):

# Stückliste — final (Stand 2026-10-09, Preise inkl. MwSt.)

**Regel:** Alles, was auf die drei Platinen gelötet wird, kommt von **Reichelt** (Art.-Nr. am 2026-10-09 auf reichelt.de geprüft, alle „2–3 Werktage“). Gesteckte oder verkabelte Module kommen von **Amazon** oder aus dem Bestand. Kein SMD. Referenzen = KiCad.

## A · Reichelt — alles für die Platinen

| Ref | Bauteil | Reichelt Art.-Nr. | Stück | Preis € | Hinweis |
|---|---|---|---|---|---|
| U1, U3, U4, DSP1 | Buchsenleiste 1×40, 2,54 (schneiden: 2× 22 DevKit, 4× 8 DRV8833, 1× 14 Display) | BKL 10120978 | 3 | 9,54 | beim Schneiden geht je Schnitt ein Pin verloren |
| J3–J6, U5, J12–J18 | Stiftleiste 1×40, 2,54 (schneiden) | SL 1X40G 2,54 | 2 | 0,60 | 72 Pins gebraucht |
| J8 | Stiftleiste 2×2 (RST/BOOT) | ECON SL4G2 | 1 | 0,13 | |
| J1 | Leiterplattenklemme 4-pol., RM 5,08 (VBUS GND CC1 CC2) | MKDS 1,5 4 5,08 | 1 | 1,61 | Phoenix, passt 1:1 zum KiCad-Footprint |
| J2, J9 | Wannenstecker 2×15 gerade | HAN 530 6324 | 2 | 4,24 | |
| — | Pfostenbuchse 30-pol. (Kabel Mainboard ↔ Frontpanel) | HAN 530 6803 | 2 | 3,70 | |
| J7, J11 | Wannenstecker 2×5 gerade | WSL 10G | 2 | 0,30 | Augen-Kabel, verpolsicher |
| — | Pfostenbuchse 10-pol. | PFL 10 | 2 | 0,20 | |
| — | Flachbandkabel 40-pol., 28 AWG, 3 m | AWG 28-40G 3M | 1 | 6,96 | auf 30 bzw. 10 Adern abreißen |
| U2 | LDO 3,3 V, TO-220 | LD1117V33 | 1 | 0,25 | |
| D1 | Schottky 40 V/5 A, DO-201 | SB 540 DIO | 1 | 0,30 | |
| F1 | PTC 3 A (Haltestrom), radial | LITT RXEF300 | 1 | 1,00 | Shop nennt den Auslösestrom 6 A |
| U8 | MCP23017-E/SP, DIP-28 | MCP 23017-E/SP | 1 | 1,76 | |
| — | IC-Sockel DIP-28 schmal | GS 28P-S | 1 | 0,45 | |
| Q1 | BC327-25, TO-92 | BC 327-25 | 1 | 0,06 | Backlight high-side |
| C1, C5 | Elko 1000 µF/16 V, RM 5 | RAD 105 1.000/16 | 2 | 0,42 | |
| C4 | Elko 470 µF/16 V, RM 3,5 | NHG-A 470U 16 | 1 | 0,23 | Servos |
| C2, C3 | Elko 100 µF/16 V, RM 2,5 | HD-A 100U 16 | 2 | 0,80 | DRV8833-VM |
| C11 | Elko 10 µF/63 V, RM 2 | JAM TKP100M1JD11 | 1 | 0,05 | LD1117-Ausgang |
| C6, C7, C12, C15–C18, C20, C21 | Kerko 100 nF, RM 5 | KERKO 100N | 9 | 0,36 | |
| C13, C14 | Kerko 10 nF | KERKO 10N | 2 | 0,16 | Encoder-Entprellung |
| R1, R2 | 5,1 kΩ 0207 | METALL 5,10K | 2 | 0,14 | CC1/CC2 |
| R3, R8, R10, R17 | 10 kΩ 0207 | METALL 10,0K | 4 | 0,28 | |
| R4 | 15 kΩ 0207 | METALL 15,0K | 1 | 0,07 | PSU_SENSE → 3,0 V |
| R5 | 330 Ω 0207 | METALL 330 | 1 | 0,07 | ARGB-Daten |
| R6, R7 | 4,7 kΩ 0207 | METALL 4,70K | 2 | 0,20 | I²C-Pull-ups |
| R11, R13–R16 | 1 kΩ 0207 | METALL 1,00K | 5 | 0,35 | Backlight-Basis, Schleifer-RC |
| SW1–SW10 | Cherry MX Black, Fixierzapfen (PCB-Montage) | CHERRY MX2A-11NW | 10 | 4,50 | |
| ENC1 | ALPS-Drehgeber mit Taster, vertikal (EC11-Footprint) | STEC11B03 | 1 | 4,69 | 15 Impulse / 30 Rastungen |
| — | Knopf für 6-mm-Achse | KNOPF 20-6 SW | 1 | 2,92 | |
| H9–H12 | Abstandsbolzen M3 × 11, Innen/Außen | ECON D3X11A5MT | 4 | 0,72 | Display; M3-Schrauben/Muttern aus dem Sortiment |
| | | | **Summe** | **≈ 47 €** | + Versand ab 6,95 € |

Lötjumper JP1 (VM: 1-2 = 5 V ab Werk, 2-3 = Boost) und die Testpunkte TP1–TP3 sind Kupfer, keine Bauteile.

## B · Module — Amazon oder Bestand (verkabelt oder gesteckt)

| Ref | Modul | Quelle | Preis € | Hinweis |
|---|---|---|---|---|
| U1 | ESP32-S3-DevKitC-1 **N16R8** (Espressif) | Amazon | 19,99 | N8R8 (Reichelt ESP32S3DK-C1N8R8, ~17,50) passt genauso: gleiche Pins, Octal-PSRAM. USB-Buchse am Board prüfen (USB-C oder Micro-USB) → passendes Einbaukabel |
| U3, (U4) | DRV8833-Breakout **Pololu #2130** | Bestand prüfen, sonst Amazon ~10 | 0–10 | nur das Pololu-Layout (Reihen 10,16 mm, 16 Pins) passt in den Sockel; U4 erst für Fader 3/4 |
| DSP1 | 2,8" ILI9341 SPI, **MSP2807-Typ** (rote Platine, 14-Pin-Leiste, 4 Löcher 76,08 × 44) | Amazon | 14,11 | Touch-Pins bleiben unbelegt |
| J12, J13 | 2× GC9A01 1,28" rund, 7-Pin (VCC GND SCL SDA RES DC CS) | Amazon (2er-Pack) | 10,07 | per 7-poligem Dupont-Kabel (Buchse–Buchse) an die Stiftleisten |
| J18 | MPR121-Breakout (beliebig) | Amazon | 6,04 | per Kabel an J18; ADDR am Modul auf GND |
| U5 | Boost-Modul ~9 V (MT3608 o. ä.) | Amazon (Pack) | 6,04 | per 4 Drähten an U5; vor Anschluss einstellen, JP1 dann auf 2-3 |
| J1 | USB-C-Buchse als Breakout mit CC1/CC2-Pins | Amazon oder Reichelt (Soldered 333011, 1,77) | ~2 | in die Rückwand; 4 Drähte an J1. Hat das Breakout schon 5,1 kΩ an CC: CC-Drähte weglassen |
| — | USB-C-Einbauverlängerung Buchse → Stecker (~30 cm) | Amazon | 8,05 | Daten-Port Rückwand → DevKit |
| J14–J17 | Behringer X32 Motorfader-Set (5× 100 mm) | Amazon | 39,32 | Drähte an die 8-Pin-Leisten; Reichelt-Alternative: ALPS RSA0N11M9 100 mm (18,70 je Stück, Motor 4–10 V) |
| J3, J4 | 2× MG90S | Amazon | 14,10 | Servostecker passt direkt auf die Stiftleiste |
| — | Keycaps blank, MX-Stem | Amazon oder 3D-Druck | 10,04 | Reichelt führt keine |
| | | **Summe** | **≈ 130 €** | + ggf. DRV8833 |

## C · Bestand

| Bauteil | Verwendung |
|---|---|
| BME680-Breakout | per 4-poligem Kabel an J6 (3V3 GND SCL SDA) — sitzt hinter den Lüftungsschlitzen, weg von der ESP-Wärme |
| ARGB/WS2812-Streifen (Drohne) | Mund/Ampel hinter dem Visier, an J5 (5V GND DIN) |
| Netzteil 5 V/3 A USB-C | Strom über J1 |
| USB-C-Kabel | 2 Stück |
| CYD ESP32-2432S028R | nicht verbaut — Testgerät für LovyanGFX |

## Summe

Reichelt ≈ 47 € + Versand, Module ≈ 130 € → **≈ 185 €** ohne Platinen. JLCPCB (Sponsor) separat: drei Designs, je 5 Stück.

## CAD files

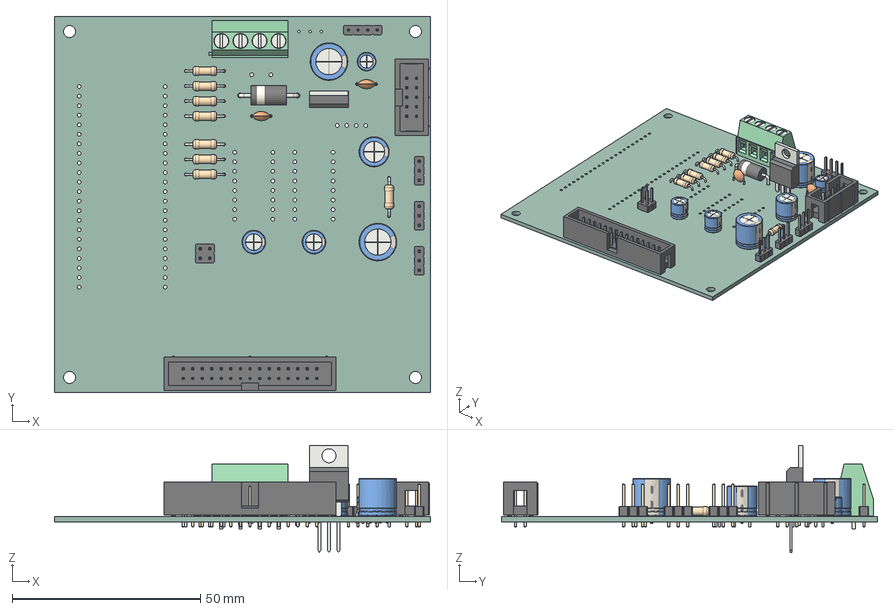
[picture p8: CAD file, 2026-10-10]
hardware/kicad/mainboard/fab/mainboard.step
100.0 x 100.0 x 28.5 mm
IDC-Header_2x15_P2.54mm_Vertical
PinHeader_1x03_P2.54mm_Vertical x 3
CP_Radial_D6.3mm_P2.50mm x 2
C_Disc_D5.0mm_W2.5mm_P5.00mm x 2
CP_Radial_D5.0mm_P2.00mm
R_Axial_DIN0207_L6.3mm_D2.5mm_P10.16mm_Horizontal x 8
CP_Radial_D10.0mm_P5.00mm x 2
PinHeader_2x02_P2.54mm_Vertical
IDC-Header_2x05_P2.54mm_Vertical
PinHeader_1x04_P2.54mm_Vertical
TerminalBlock_Phoenix_MKDS-1,5-4-5.08_1x04_P5.08mm_Horizontal
D_DO-201_P15.24mm_Horizontal
CP_Radial_D8.0mm_P3.50mm
TO-220-3_Vertical
mainboard_PCB

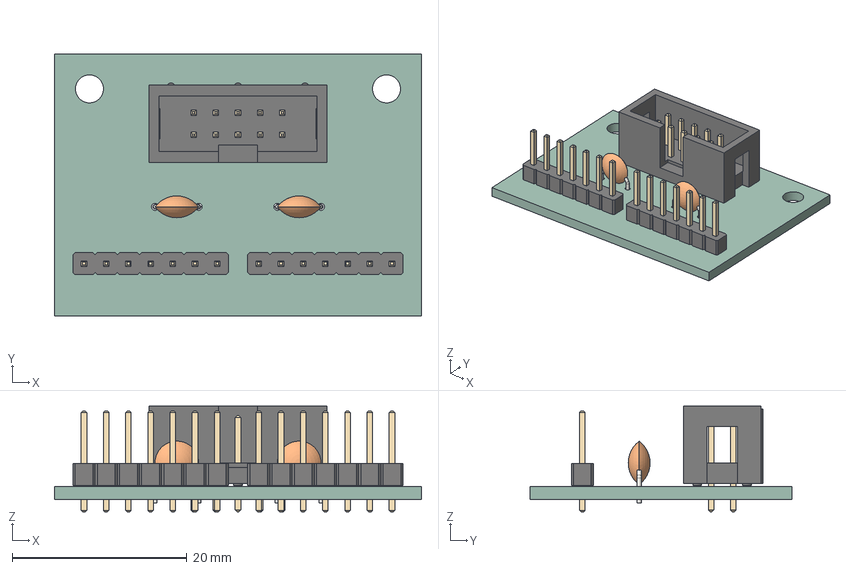
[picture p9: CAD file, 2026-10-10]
hardware/kicad/eye-adapter/fab/eye-adapter.step
42.0 x 30.0 x 12.1 mm
PinHeader_1x07_P2.54mm_Vertical x 2
C_Disc_D5.0mm_W2.5mm_P5.00mm x 2
IDC-Header_2x05_P2.54mm_Vertical
eye-adapter_PCB

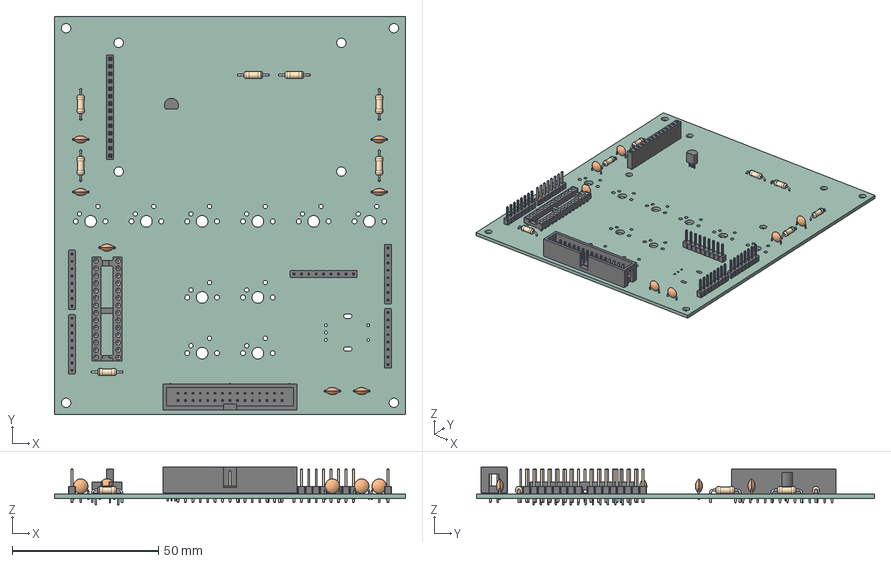
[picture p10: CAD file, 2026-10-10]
hardware/kicad/frontpanel/fab/frontpanel.step
120.0 x 136.0 x 12.9 mm
TO-92_Inline
PinSocket_1x14_P2.54mm_Vertical
C_Disc_D5.0mm_W2.5mm_P5.00mm x 7
R_Axial_DIN0207_L6.3mm_D2.5mm_P10.16mm_Horizontal x 7
PinHeader_1x08_P2.54mm_Vertical x 4
PinHeader_1x09_P2.54mm_Vertical
DIP-28_W7.62mm_Socket
IDC-Header_2x15_P2.54mm_Vertical
frontpanel_PCB

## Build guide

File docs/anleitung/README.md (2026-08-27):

# Bauanleitung

Noch gibt es nichts zu bauen — Desk-Mate ist in der Design-Phase. Diese Anleitung wächst mit jedem abgeschlossenen Schritt und soll am Ende einen kompletten Nachbau erlauben, ohne das Repo durchwühlen zu müssen.

## Geplante Kapitel

| Nr | Kapitel | Status |
|---|---|---|
| 00 | Überblick, Werkzeug, Teile besorgen ([Stückliste](../../hardware/bom.md)) | Entwurf folgt mit der Bestellung |
| 01 | [Platinen bestellen](01-platinen.md) (Gerber, JLCPCB) | Entwurf 27.08. |
| 02 | Löten: Mainboard (alles Through-Hole) | nach Lieferung |
| 03 | Löten: Frontpanel (Fader, Tasten, Encoder) | nach Lieferung |
| 04 | 3D-Druck: Base, Bauch, Kopf, Visier | nach Gehäuse-Design |
| 05 | Zusammenbau + Verkabelung | — |
| 06 | Firmware flashen (arduino-cli) | — |
| 07 | Mac-Agent + Handy-App einrichten | — |
| 08 | Claude-Code-Hooks aktivieren | — |

## Bis dahin

- Was gebaut wird und warum: [Design-Spec](../superpowers/specs/2026-08-22-desk-mate-design.md)
- Tagesprotokolle mit Arbeitszeit: [`vault/Log/`](../../vault/Log/)
- Der allererste Prompt: [Relikt](../relic/2026-08-22-original-prompt.md)

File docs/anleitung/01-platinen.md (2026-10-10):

# 01 · Platinen bestellen

Desk-Mate besteht aus drei Platinen, die in **einer** JLCPCB-Bestellung kommen. Alle Fertigungsdaten liegen fertig im Repo — du musst KiCad nicht öffnen.

| Platine | Datei für JLCPCB | Maß | Stück |
|---|---|---|---|
| Mainboard (Base) | `hardware/kicad/mainboard/fab/mainboard-gerber.zip` | 100 × 100 mm | 5 (Mindestmenge) |
| Frontpanel (Deck) | `hardware/kicad/frontpanel/fab/frontpanel-gerber.zip` | 120 × 136 mm | 5 |
| Augen-Adapter (Kopf) | `hardware/kicad/eye-adapter/fab/eye-adapter-gerber.zip` | 42 × 30 mm | 5 |

## Bestellparameter (JLCPCB „Standard PCB“)

- 2 Lagen, FR-4, **1,6 mm**, 1 oz Kupfer
- Oberfläche: HASL (bleifrei) reicht — alles Through-Hole; ENIG nur, wenn's schöner sein soll
- Farbe: frei (Referenz-Build: weiß, passend zum Gehäuse)
- Kein SMD-Assembly nötig (alles THT, Module gesteckt)
- **Mark on PCB: „Order Number (Specify Position)“** — jede Platine hat auf der Rückseite das Feld `JLCJLCJLCJLC`; dort druckt JLCPCB die Bestellnummer hin statt irgendwo zwischen die Beschriftung
- Bei weißer Lötstoppmaske druckt JLCPCB den Silkscreen schwarz — das Logo funktioniert in beiden Farben (Augen und Lächeln sind Aussparungen)

Alle drei Zips einzeln als eigenes Produkt hochladen (drei Designs = drei Positionen im Warenkorb). Im JLCPCB-Viewer kurz prüfen: Umriss geschlossen, Bohrungen da, Silkscreen lesbar.

## Was auf die Platinen kommt

Die Stückliste mit Bezugsquellen und Preisen steht in `hardware/bom.md`; welche Maße der gesteckten Module der Entwurf annimmt (und wie sicher das ist), in `vault/Hardware/Module-Masse.md`. **Vor dem Löten der Sockel** die Kandidaten mit „mittel“-Konfidenz am echten Modul nachmessen: DRV8833-Module aus der Box (Pololu #2130, Raster 10,16 mm?). MPR121, BME680, Augen-Displays und Fader hängen an Kabeln — dort zählt nur die Pin-Beschriftung auf dem Silkscreen.

## Schaltpläne und 3D

Je Platine liegt in `fab/` außerdem der Schaltplan als PDF, ein STEP-Modell (für das Gehäuse in `hardware/3d/`) und Renderings von Ober- und Unterseite. Quelle sind die KiCad-10-Projekte im jeweiligen Ordner — Änderungen bitte dort, nicht in den Exporten.

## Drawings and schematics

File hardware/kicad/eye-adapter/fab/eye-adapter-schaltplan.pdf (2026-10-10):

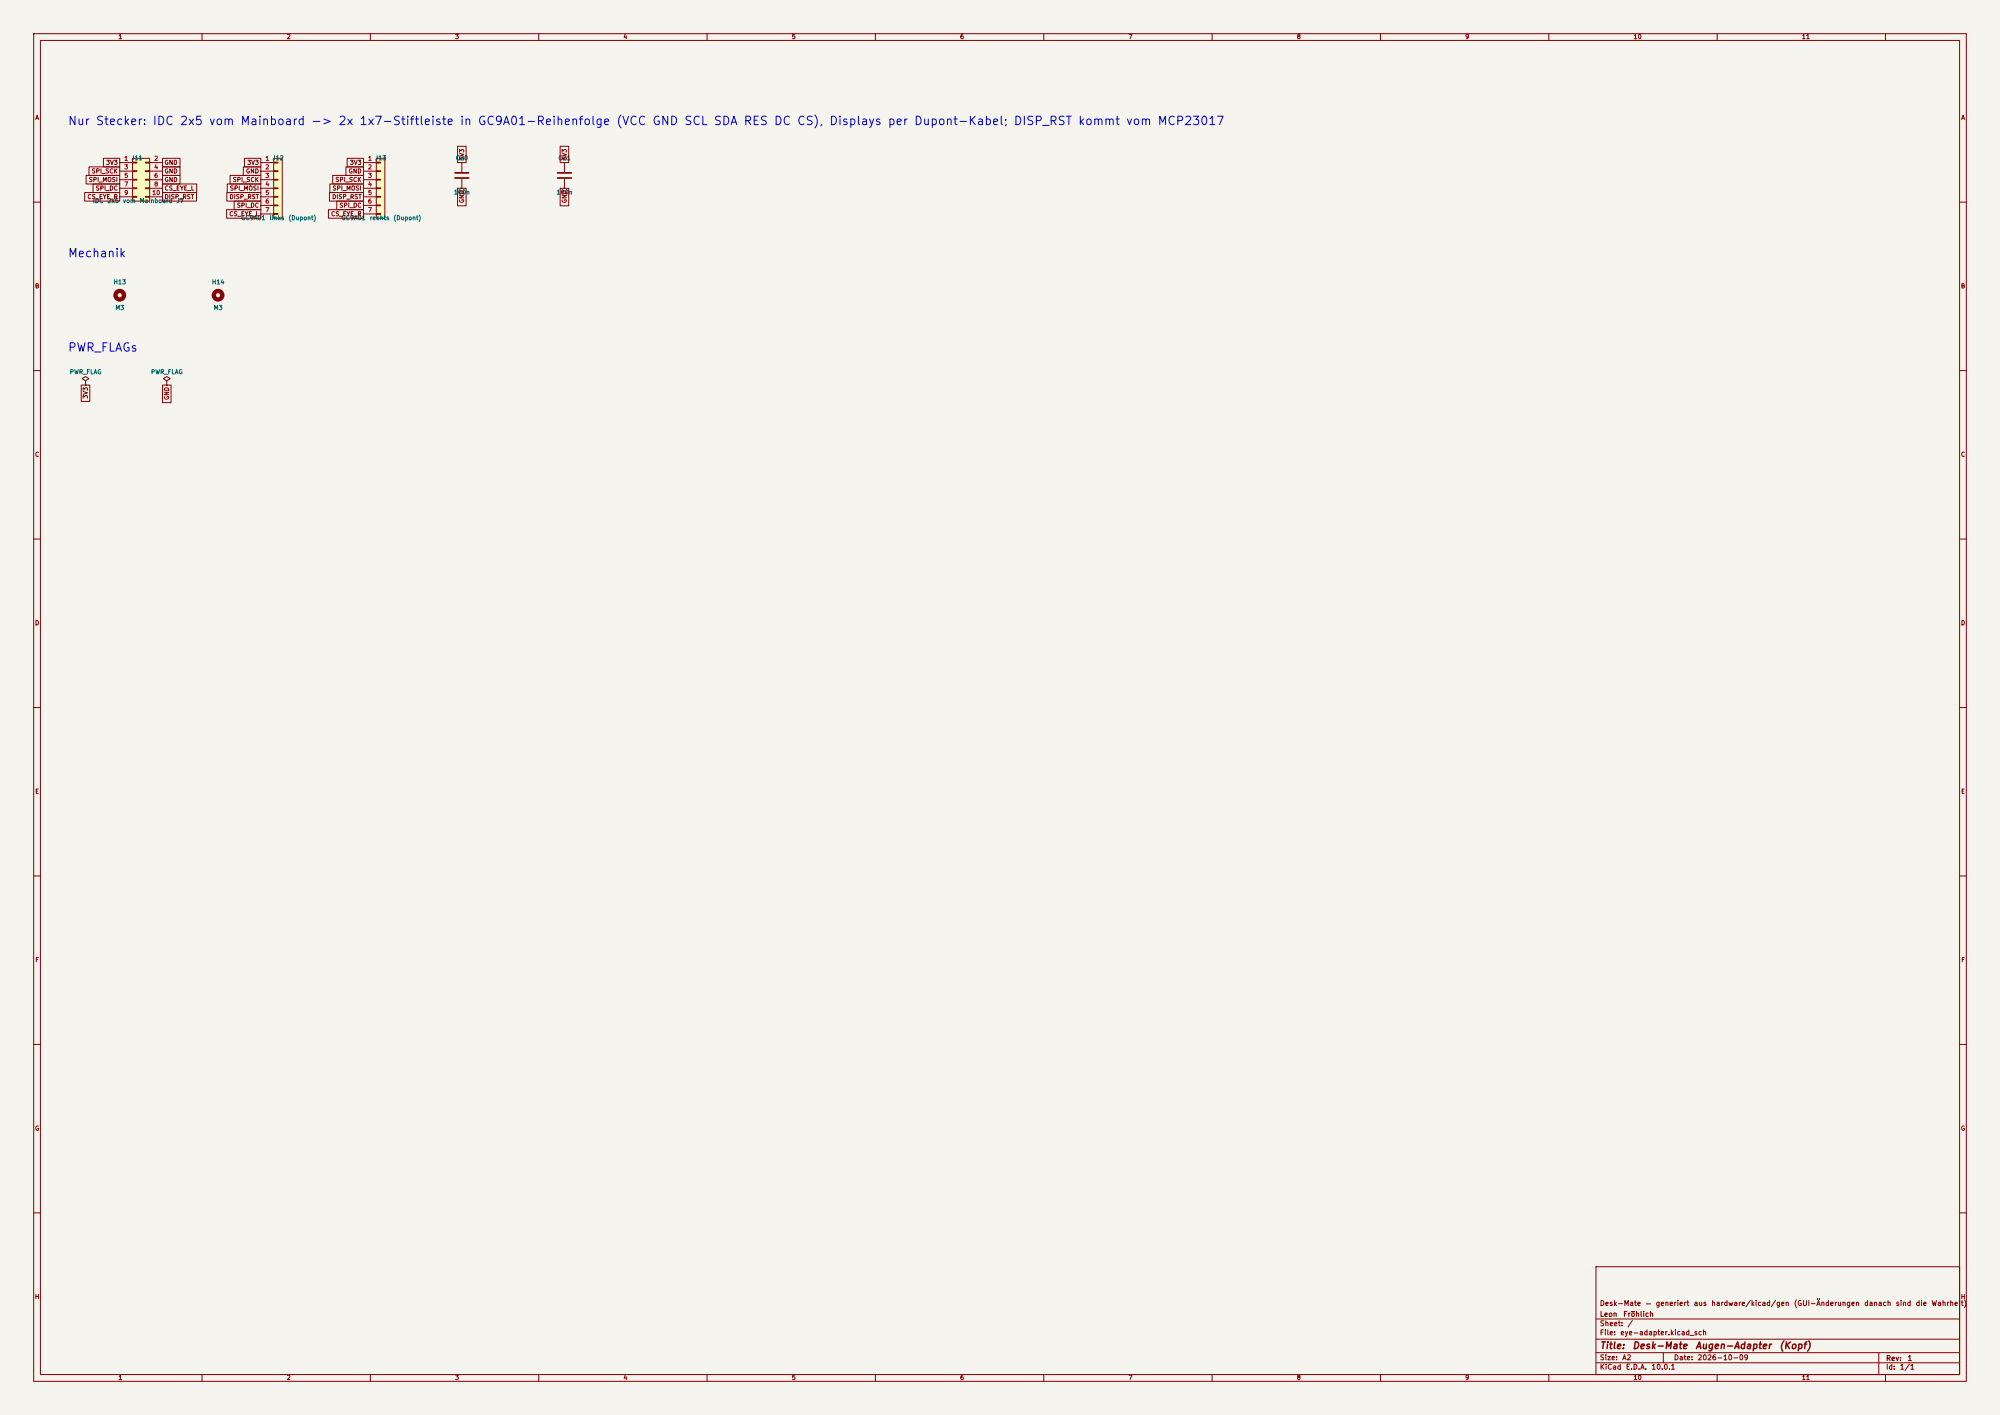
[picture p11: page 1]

Desk-Mate — generiert aus hardware/kicad/gen (GUI-Änderungen danach sind die Wahrheit)
Leon Fröhlich
Sheet: /
File: eye-adapter.kicad_sch
Title: Desk-Mate Augen-Adapter (Kopf)

Size: A2 | Rev: 1
KiCad E.D.A. 10.0.1 | Id: 1/1

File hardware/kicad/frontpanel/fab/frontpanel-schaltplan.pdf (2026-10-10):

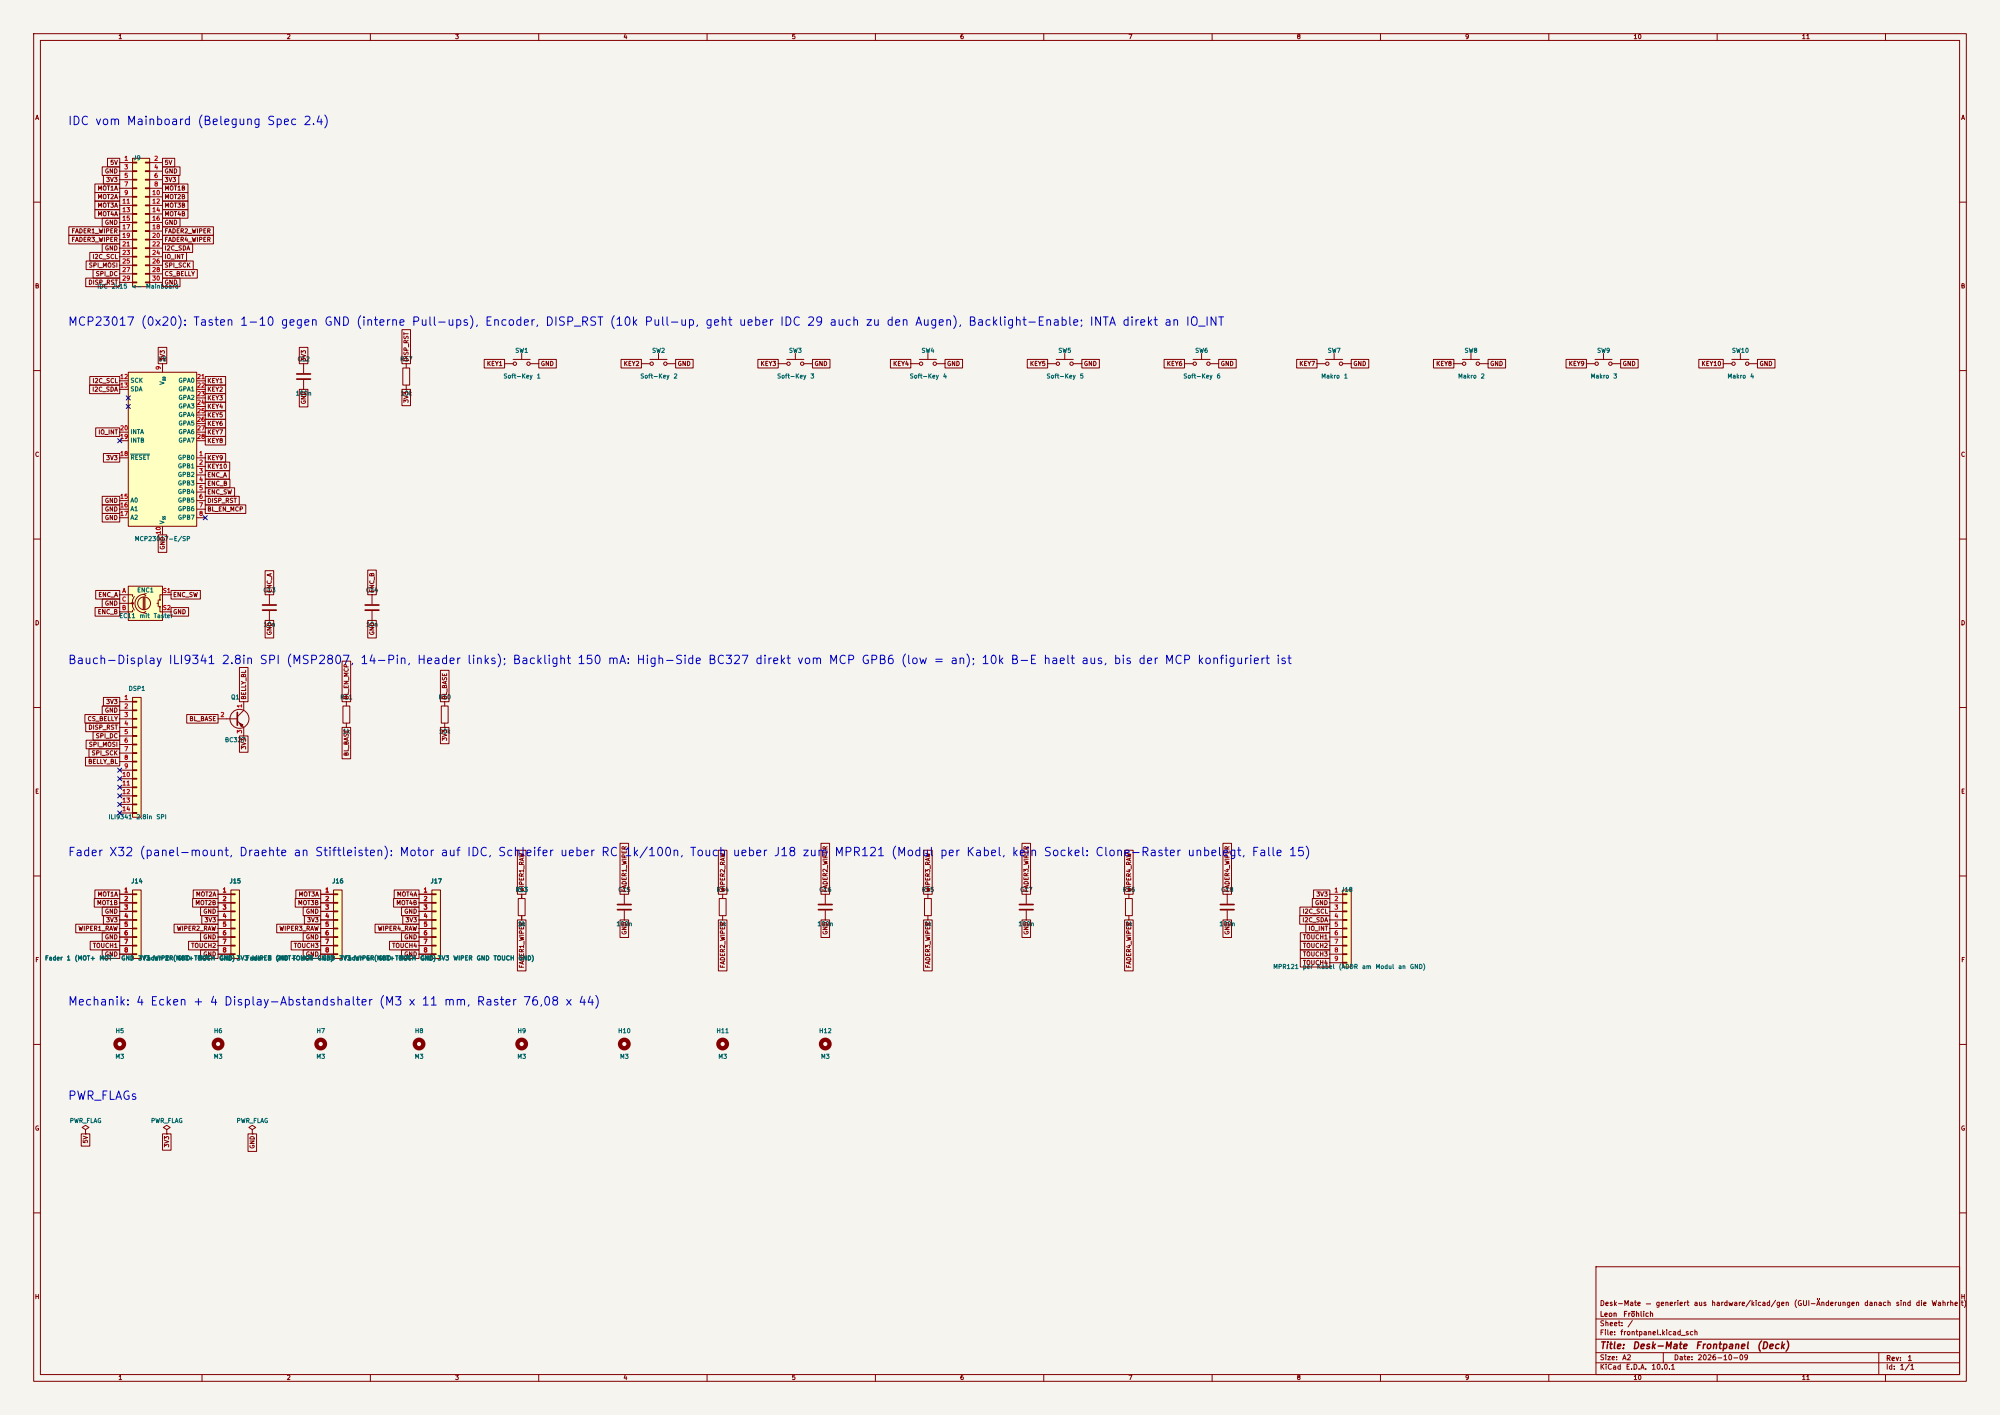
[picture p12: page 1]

MCP23017 (0x20): Tasten 1-10 gegen GND (interne Pull-ups), Encoder, DISP_RST (10k Pull-up, geht ueber IDC 29 auch zu den Augen), Backlight-Enable; INTA direkt an IO_INT

J18 MPR121 per Kabel (ADDR am Modul an GND) R11

Fader 3 (MOT+ MOT- GND 3V3 WIPER GND TOUCH GND) 1

Fader 1 (MOT+ MOT- GND 3V3 WIPER GND TOUCH GND) 1

Fader 2 (MOT+ MOT- GND 3V3 WIPER GND TOUCH GND)

Fader 1 (MOT+ MOT- GND 3V3 WIPER GND TOUCH GND)
FGH

Fader 3 (MOT+ MOT- GND 3V3 WIPER GND TOUCH GND)

Mechanik: 4 Ecken + 4 Display-Abstandshalter (M3 x 11 mm, Raster 76,08 x 44)

Desk-Mate — generiert aus hardware/kicad/gen (GUI-Änderungen danach sind die Wahrheit)
Leon Fröhlich
Sheet: /
File: frontpanel.kicad_sch
Title: Desk-Mate Frontpanel (Deck)

Size: A2 | Rev: 1
KiCad E.D.A. 10.0.1 | Id: 1/1

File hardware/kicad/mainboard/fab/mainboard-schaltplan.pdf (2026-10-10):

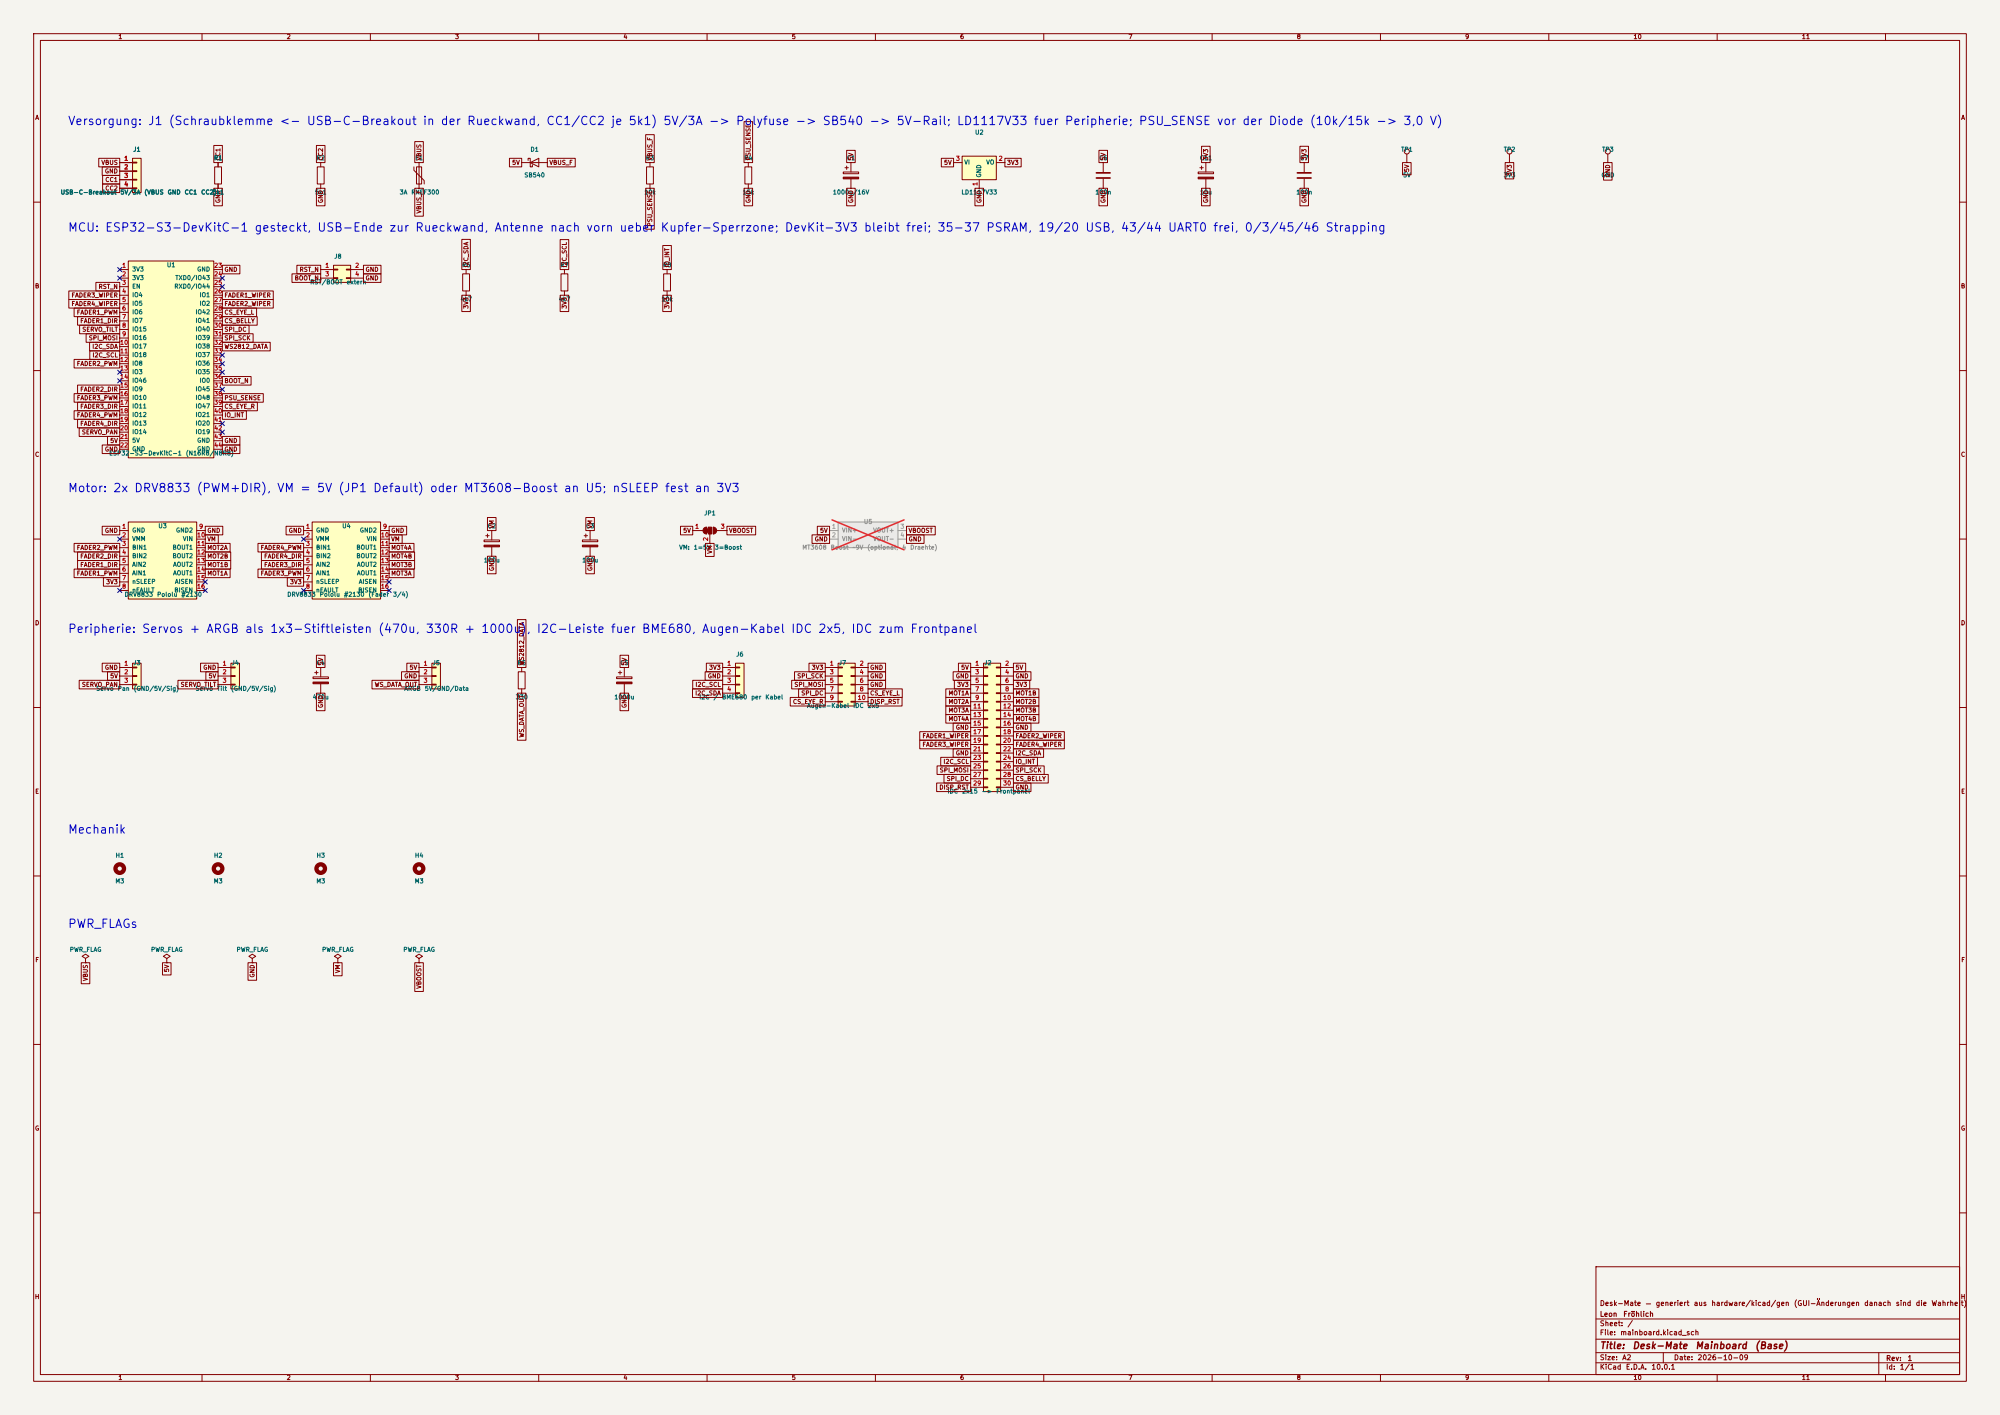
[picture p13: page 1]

Versorgung: J1 (Schraubklemme <- USB-C-Breakout in der Rueckwand, CC1/CC2 je 5k1) 5V/3A -> Polyfuse -> SB540 -> 5V-Rail; LD1117V33 fuer Peripherie; PSU_SENSE vor der Diode (10k/15k -> 3,0 V)
J8 RST/BOOT extern R2

Motor: 2x DRV8833 (PWM+DIR), VM = 5V (JP1 Default) oder MT3608-Boost an U5; nSLEEP fest an 3V3

ARGB 5V/GND/Data GND 1

Peripherie: Servos + ARGB als 1x3-Stiftleisten (470u, 330R + 1000u), I2C-Leiste fuer BME680, Augen-Kabel IDC 2x5, IDC zum Frontpanel

Desk-Mate — generiert aus hardware/kicad/gen (GUI-Änderungen danach sind die Wahrheit)
Leon Fröhlich
Sheet: /
File: mainboard.kicad_sch
Title: Desk-Mate Mainboard (Base)

Size: A2 | Rev: 1
KiCad E.D.A. 10.0.1 | Id: 1/1

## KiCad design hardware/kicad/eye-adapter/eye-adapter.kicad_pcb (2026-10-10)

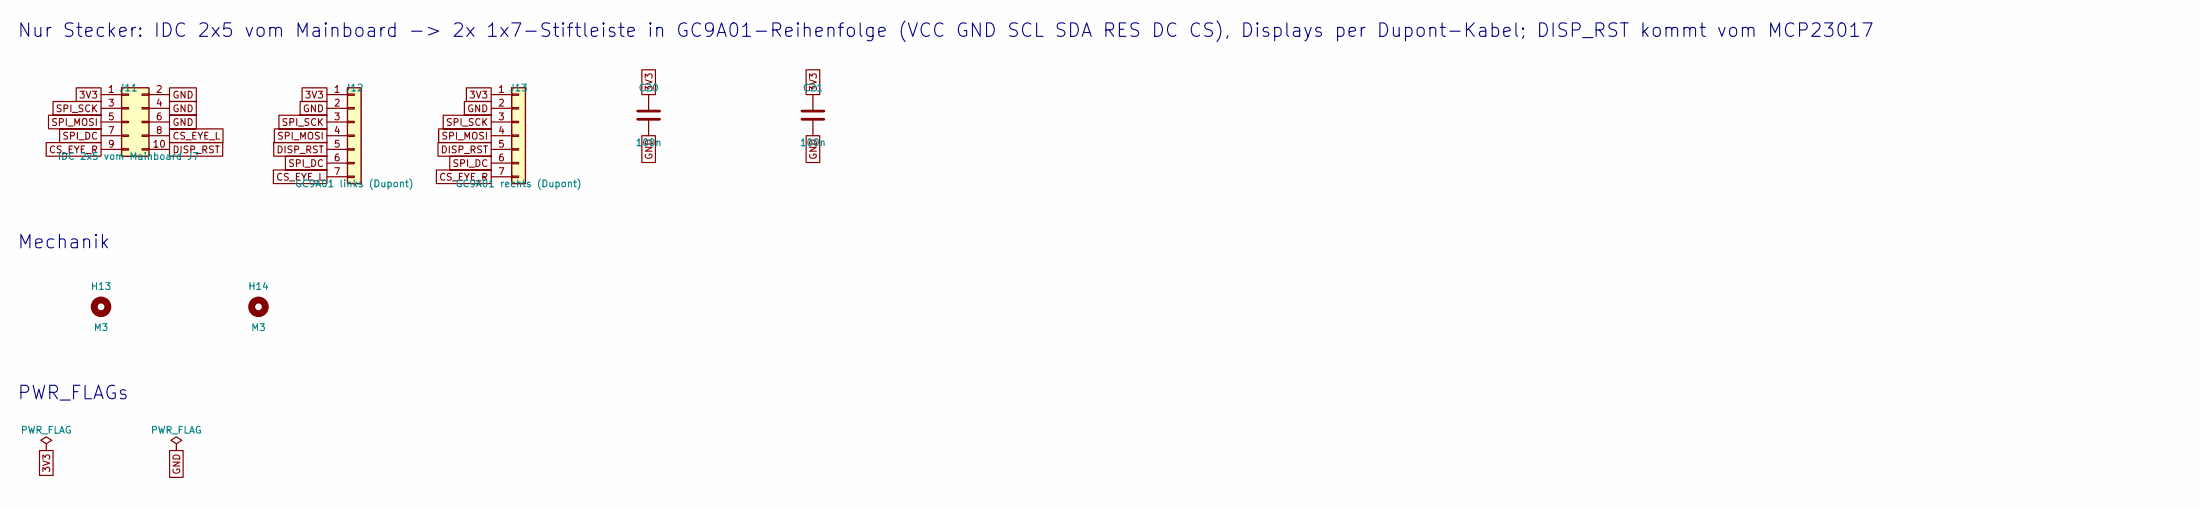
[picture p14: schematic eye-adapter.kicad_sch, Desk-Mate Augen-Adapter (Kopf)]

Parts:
C20, C21: 100n; C_Disc_D5.0mm_W2.5mm_P5.00mm
H13, H14: M3; MountingHole_3.2mm_M3
J11: IDC 2x5 vom Mainboard J7; IDC-Header_2x05_P2.54mm_Vertical
J12: GC9A01 links (Dupont); PinHeader_1x07_P2.54mm_Vertical
J13: GC9A01 rechts (Dupont); PinHeader_1x07_P2.54mm_Vertical

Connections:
3V3: C20.1, C21.1, J11.1, J12.1, J13.1
CS_EYE_L: J11.8, J12.7
CS_EYE_R: J11.9, J13.7
DISP_RST: J11.10, J12.5, J13.5
GND: C20.2, C21.2, J11.2, J11.4, J11.6, J12.2, J13.2
SPI_DC: J11.7, J12.6, J13.6
SPI_MOSI: J11.5, J12.4, J13.4
SPI_SCK: J11.3, J12.3, J13.3

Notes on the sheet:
Nur Stecker: IDC 2x5 vom Mainboard -> 2x 1x7-Stiftleiste in GC9A01-Reihenfolge (VCC GND SCL SDA RES DC CS), Displays per Dupont-Kabel; DISP_RST kommt vom MCP23017
Mechanik
PWR_FLAGs

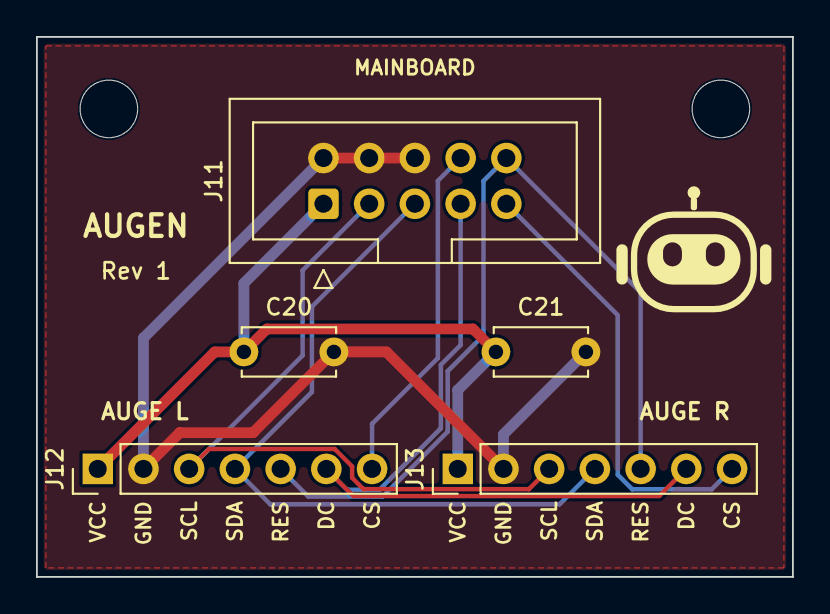
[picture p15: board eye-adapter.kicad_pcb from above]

Board: 2 copper layers, 42.0 x 30.0 mm, 7 parts (0 on the bottom side), 8 nets.

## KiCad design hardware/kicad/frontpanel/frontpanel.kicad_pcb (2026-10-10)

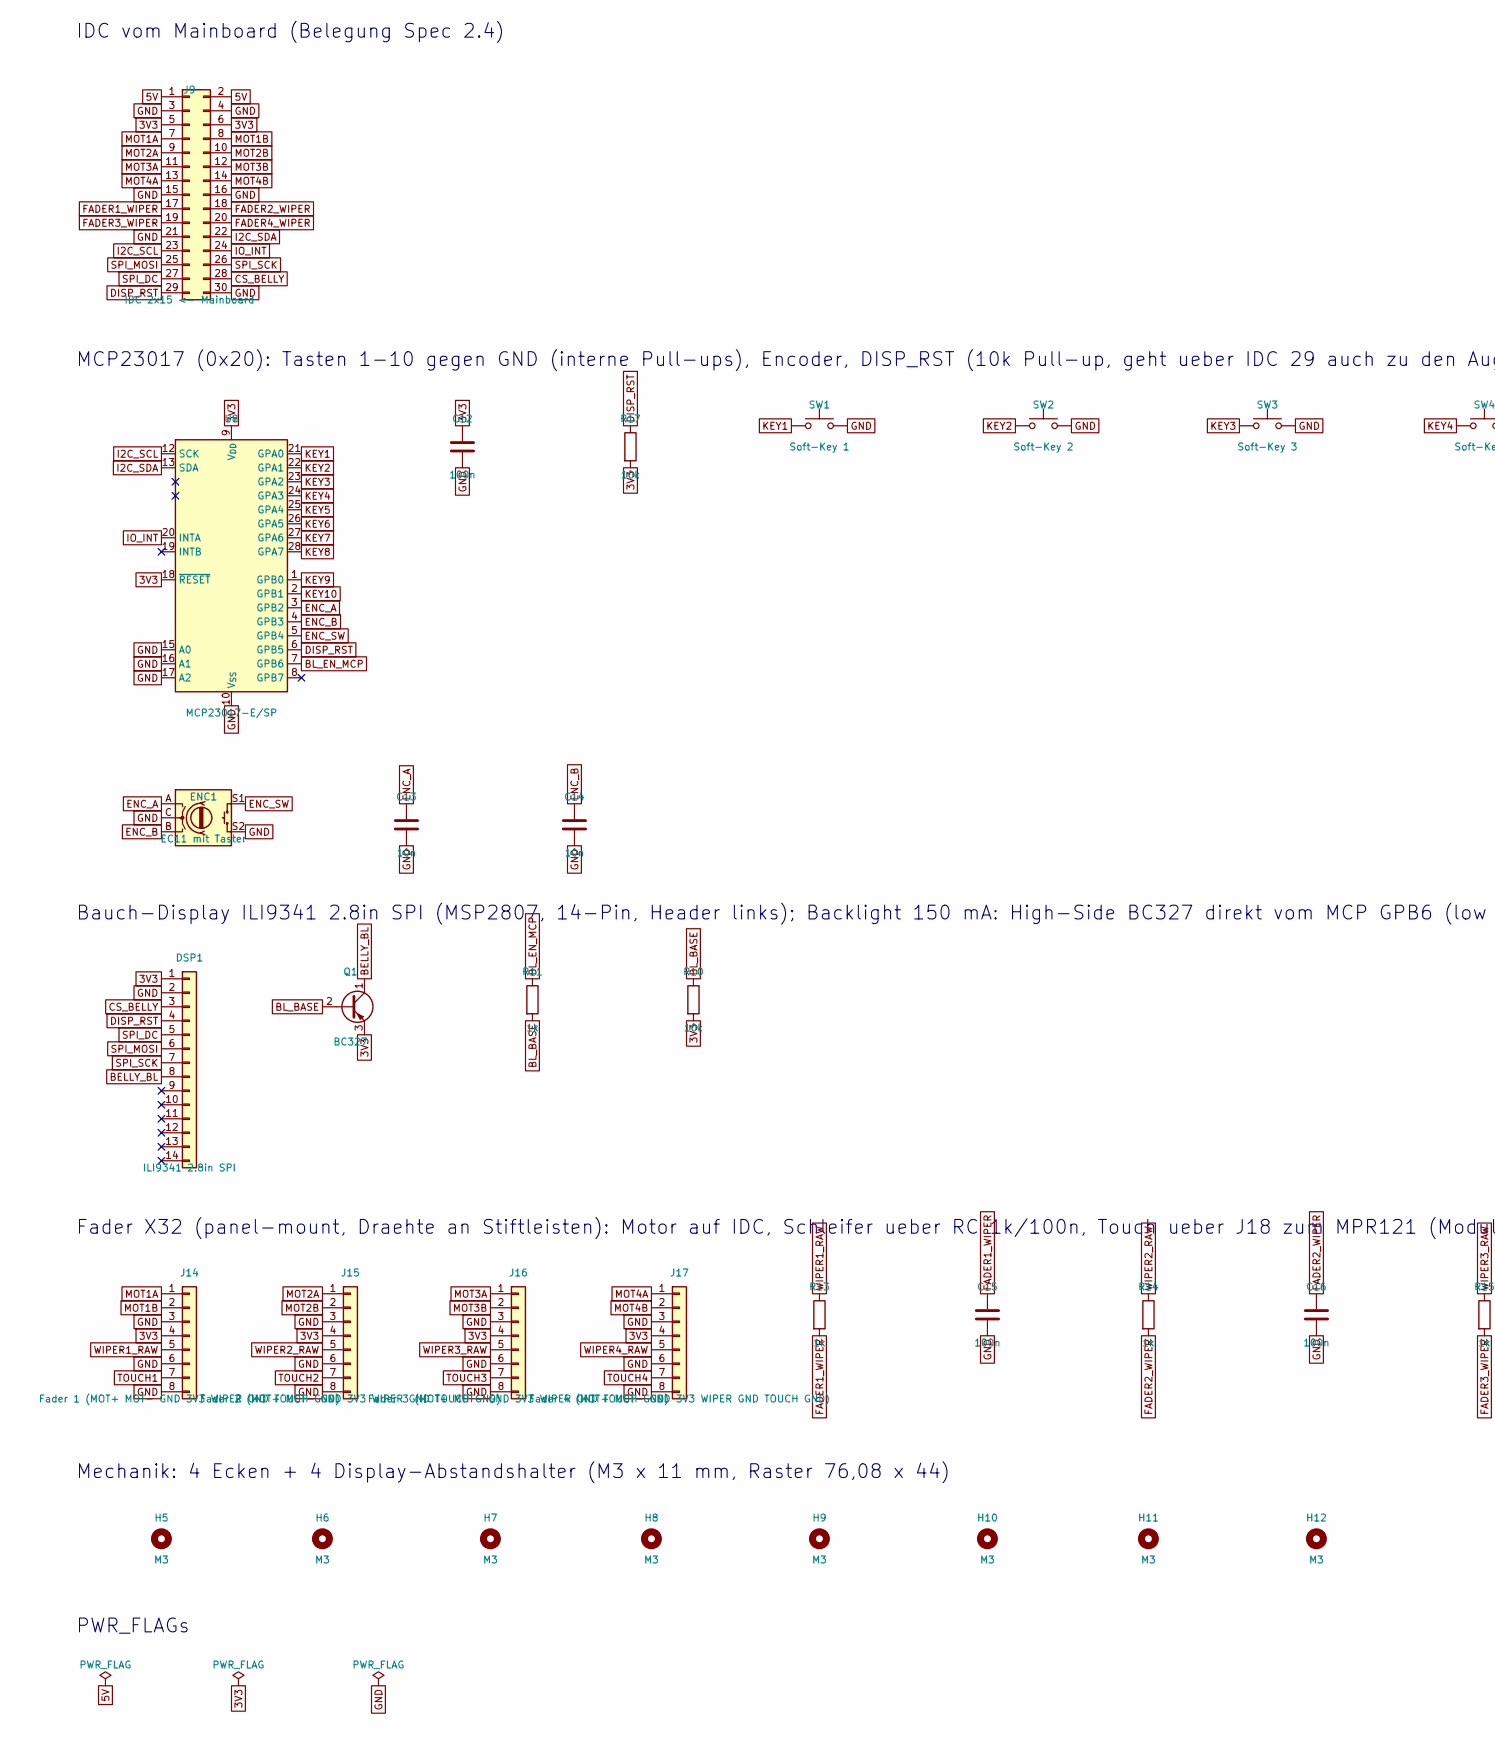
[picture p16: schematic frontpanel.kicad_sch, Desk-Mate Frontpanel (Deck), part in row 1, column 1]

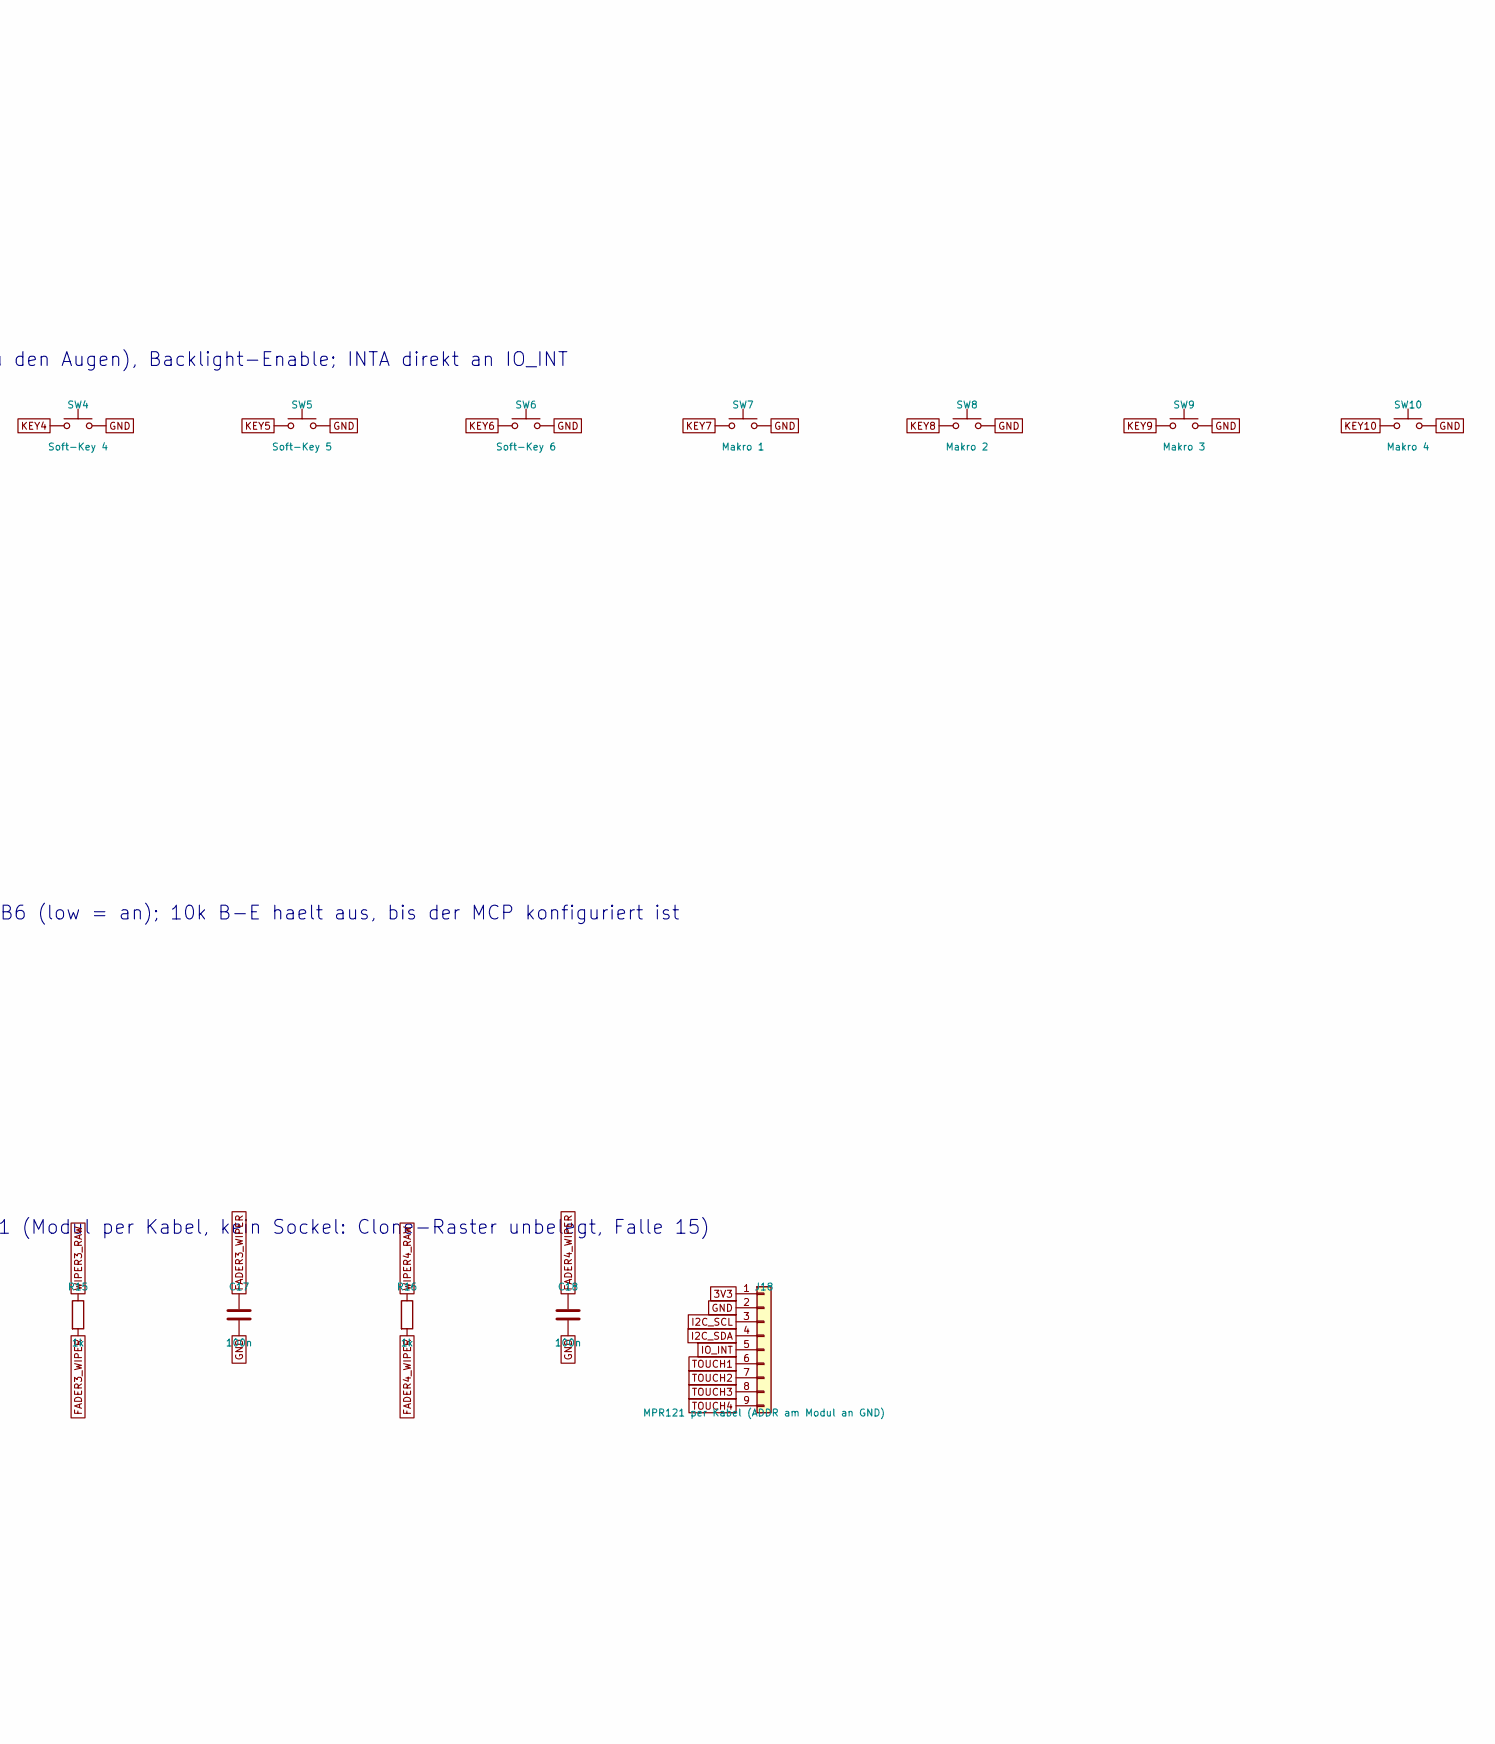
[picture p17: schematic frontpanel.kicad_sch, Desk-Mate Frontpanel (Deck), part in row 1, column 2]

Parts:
C12, C15, C16, C17, C18: 100n; C_Disc_D5.0mm_W2.5mm_P5.00mm
C13, C14: 10n; C_Disc_D5.0mm_W2.5mm_P5.00mm
DSP1: ILI9341 2.8in SPI; PinSocket_1x14_P2.54mm_Vertical
ENC1: EC11 mit Taster; RotaryEncoder_Alps_EC11E-Switch_Vertical_H20mm
H5, H6, H7, H8, H9, H10, H11, H12: M3; MountingHole_3.2mm_M3
J9: IDC 2x15 <- Mainboard; IDC-Header_2x15_P2.54mm_Vertical
J14: Fader 1 (MOT+ MOT- GND 3V3 WIPER GND TOUCH GND); PinHeader_1x08_P2.54mm_Vertical
J15: Fader 2 (MOT+ MOT- GND 3V3 WIPER GND TOUCH GND); PinHeader_1x08_P2.54mm_Vertical
J16: Fader 3 (MOT+ MOT- GND 3V3 WIPER GND TOUCH GND); PinHeader_1x08_P2.54mm_Vertical
J17: Fader 4 (MOT+ MOT- GND 3V3 WIPER GND TOUCH GND); PinHeader_1x08_P2.54mm_Vertical
J18: MPR121 per Kabel (ADDR am Modul an GND); PinHeader_1x09_P2.54mm_Vertical
Q1: BC327; TO-92_Inline
R10, R17: 10k; R_Axial_DIN0207_L6.3mm_D2.5mm_P10.16mm_Horizontal
R11, R13, R14, R15, R16: 1k; R_Axial_DIN0207_L6.3mm_D2.5mm_P10.16mm_Horizontal
SW1: Soft-Key 1; SW_Cherry_MX_1.00u_PCB
SW2: Soft-Key 2; SW_Cherry_MX_1.00u_PCB
SW3: Soft-Key 3; SW_Cherry_MX_1.00u_PCB
SW4: Soft-Key 4; SW_Cherry_MX_1.00u_PCB
SW5: Soft-Key 5; SW_Cherry_MX_1.00u_PCB
SW6: Soft-Key 6; SW_Cherry_MX_1.00u_PCB
SW7: Makro 1; SW_Cherry_MX_1.00u_PCB
SW8: Makro 2; SW_Cherry_MX_1.00u_PCB
SW9: Makro 3; SW_Cherry_MX_1.00u_PCB
SW10: Makro 4; SW_Cherry_MX_1.00u_PCB
U8: MCP23017-E/SP; DIP-28_W7.62mm_Socket

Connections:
3V3: C12.1, DSP1.1, J9.5, J9.6, J14.4, J15.4, J16.4, J17.4, J18.1, Q1.3 (E), R10.2, R17.2, U8.9 (V_{DD}), U8.18 (~RESET)
5V: J9.1, J9.2
BELLY_BL: DSP1.8, Q1.1 (C)
BL_BASE: Q1.2 (B), R10.1, R11.2
BL_EN_MCP: R11.1, U8.7 (GPB6)
CS_BELLY: DSP1.3, J9.28
DISP_RST: DSP1.4, J9.29, R17.1, U8.6 (GPB5)
ENC_A: C13.1, ENC1.A, U8.3 (GPB2)
ENC_B: C14.1, ENC1.B, U8.4 (GPB3)
ENC_SW: ENC1.S1, U8.5 (GPB4)
FADER1_WIPER: C15.1, J9.17, R13.2
FADER2_WIPER: C16.1, J9.18, R14.2
FADER3_WIPER: C17.1, J9.19, R15.2
FADER4_WIPER: C18.1, J9.20, R16.2
GND: C12.2, C13.2, C14.2, C15.2, C16.2, C17.2, C18.2, DSP1.2, ENC1.C, ENC1.S2, J9.3, J9.4, J9.15, J9.16, J9.21, J9.30, J14.3, J14.6, J14.8, J15.3, J15.6, J15.8, J16.3, J16.6, J16.8, J17.3, J17.6, J17.8, J18.2, SW1.2, SW2.2, SW3.2, SW4.2, SW5.2, SW6.2, SW7.2, SW8.2, SW9.2, SW10.2, U8.10 (V_{SS}), U8.15 (A0), U8.16 (A1), U8.17 (A2)
I2C_SCL: J9.23, J18.3, U8.12 (SCK)
I2C_SDA: J9.22, J18.4, U8.13 (SDA)
IO_INT: J9.24, J18.5, U8.20 (INTA)
KEY1: SW1.1, U8.21 (GPA0)
KEY2: SW2.1, U8.22 (GPA1)
KEY3: SW3.1, U8.23 (GPA2)
KEY4: SW4.1, U8.24 (GPA3)
KEY5: SW5.1, U8.25 (GPA4)
KEY6: SW6.1, U8.26 (GPA5)
KEY7: SW7.1, U8.27 (GPA6)
KEY8: SW8.1, U8.28 (GPA7)
KEY9: SW9.1, U8.1 (GPB0)
KEY10: SW10.1, U8.2 (GPB1)
MOT1A: J9.7, J14.1
MOT1B: J9.8, J14.2
MOT2A: J9.9, J15.1
MOT2B: J9.10, J15.2
MOT3A: J9.11, J16.1
MOT3B: J9.12, J16.2
MOT4A: J9.13, J17.1
MOT4B: J9.14, J17.2
SPI_DC: DSP1.5, J9.27
SPI_MOSI: DSP1.6, J9.25
SPI_SCK: DSP1.7, J9.26
TOUCH1: J14.7, J18.6
TOUCH2: J15.7, J18.7
TOUCH3: J16.7, J18.8
TOUCH4: J17.7, J18.9
WIPER1_RAW: J14.5, R13.1
WIPER2_RAW: J15.5, R14.1
WIPER3_RAW: J16.5, R15.1
WIPER4_RAW: J17.5, R16.1

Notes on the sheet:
IDC vom Mainboard (Belegung Spec 2.4)
MCP23017 (0x20): Tasten 1-10 gegen GND (interne Pull-ups), Encoder, DISP_RST (10k Pull-up, geht ueber IDC 29 auch zu den Augen), Backlight-Enable; INTA direkt an IO_INT
Bauch-Display ILI9341 2.8in SPI (MSP2807, 14-Pin, Header links); Backlight 150 mA: High-Side BC327 direkt vom MCP GPB6 (low = an); 10k B-E haelt aus, bis der MCP konfiguriert ist
Fader X32 (panel-mount, Draehte an Stiftleisten): Motor auf IDC, Schleifer ueber RC 1k/100n, Touch ueber J18 zum MPR121 (Modul per Kabel, kein Sockel: Clone-Raster unbelegt, Falle 15)
Mechanik: 4 Ecken + 4 Display-Abstandshalter (M3 x 11 mm, Raster 76,08 x 44)
PWR_FLAGs

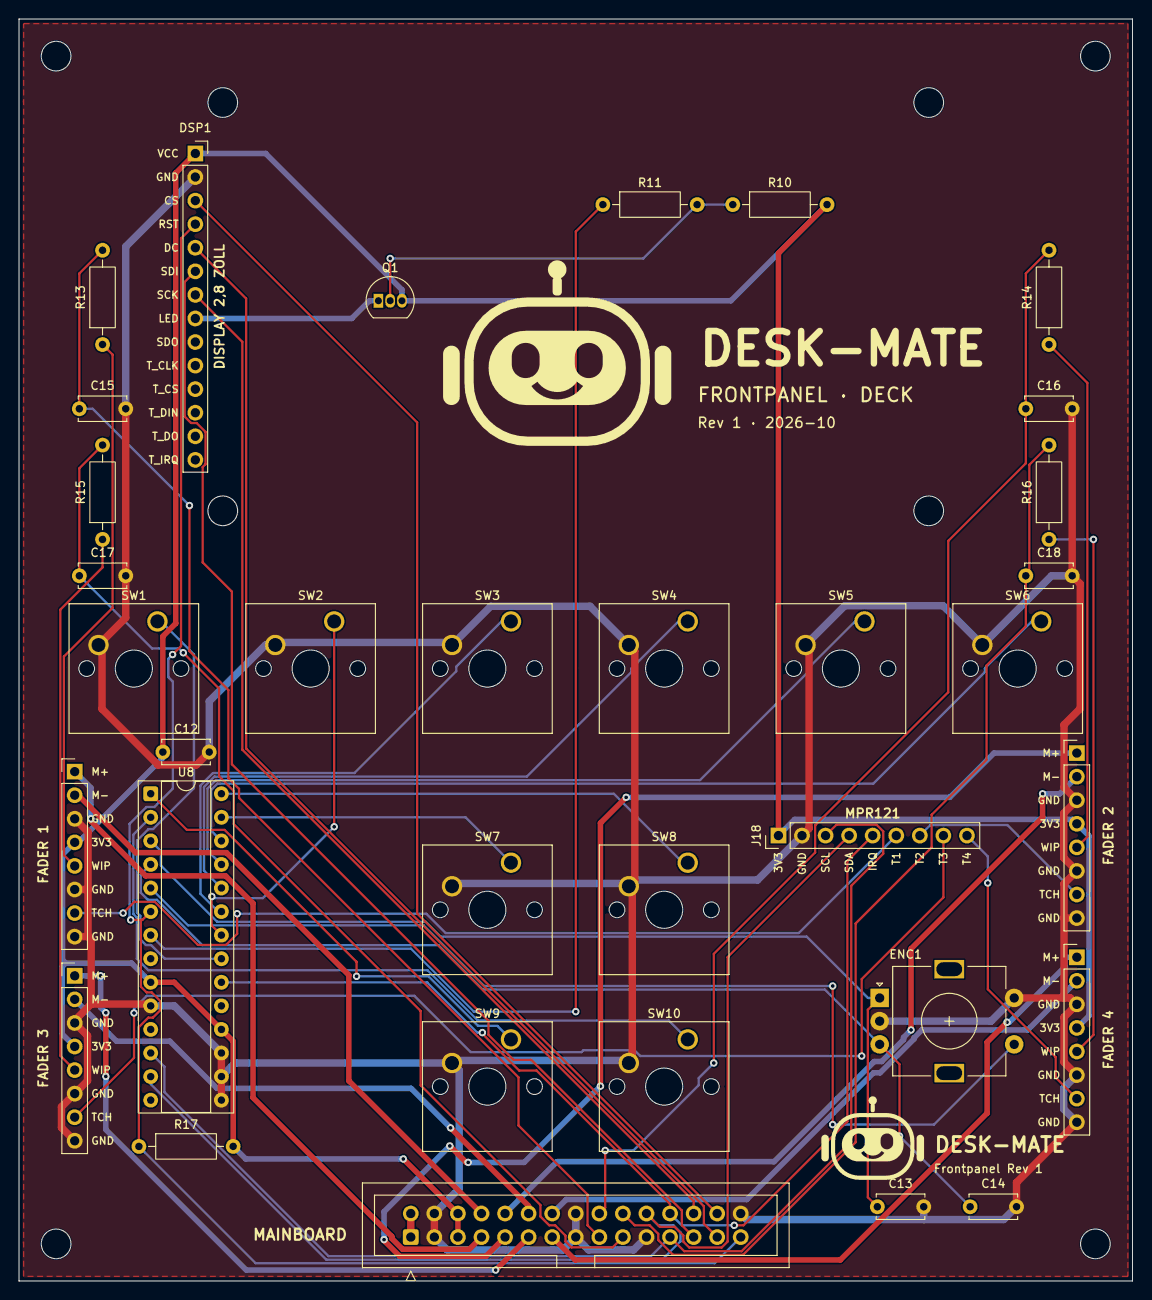
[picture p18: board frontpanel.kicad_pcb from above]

Board: 2 copper layers, 120.0 x 136.0 mm, 42 parts (0 on the bottom side), 47 nets.

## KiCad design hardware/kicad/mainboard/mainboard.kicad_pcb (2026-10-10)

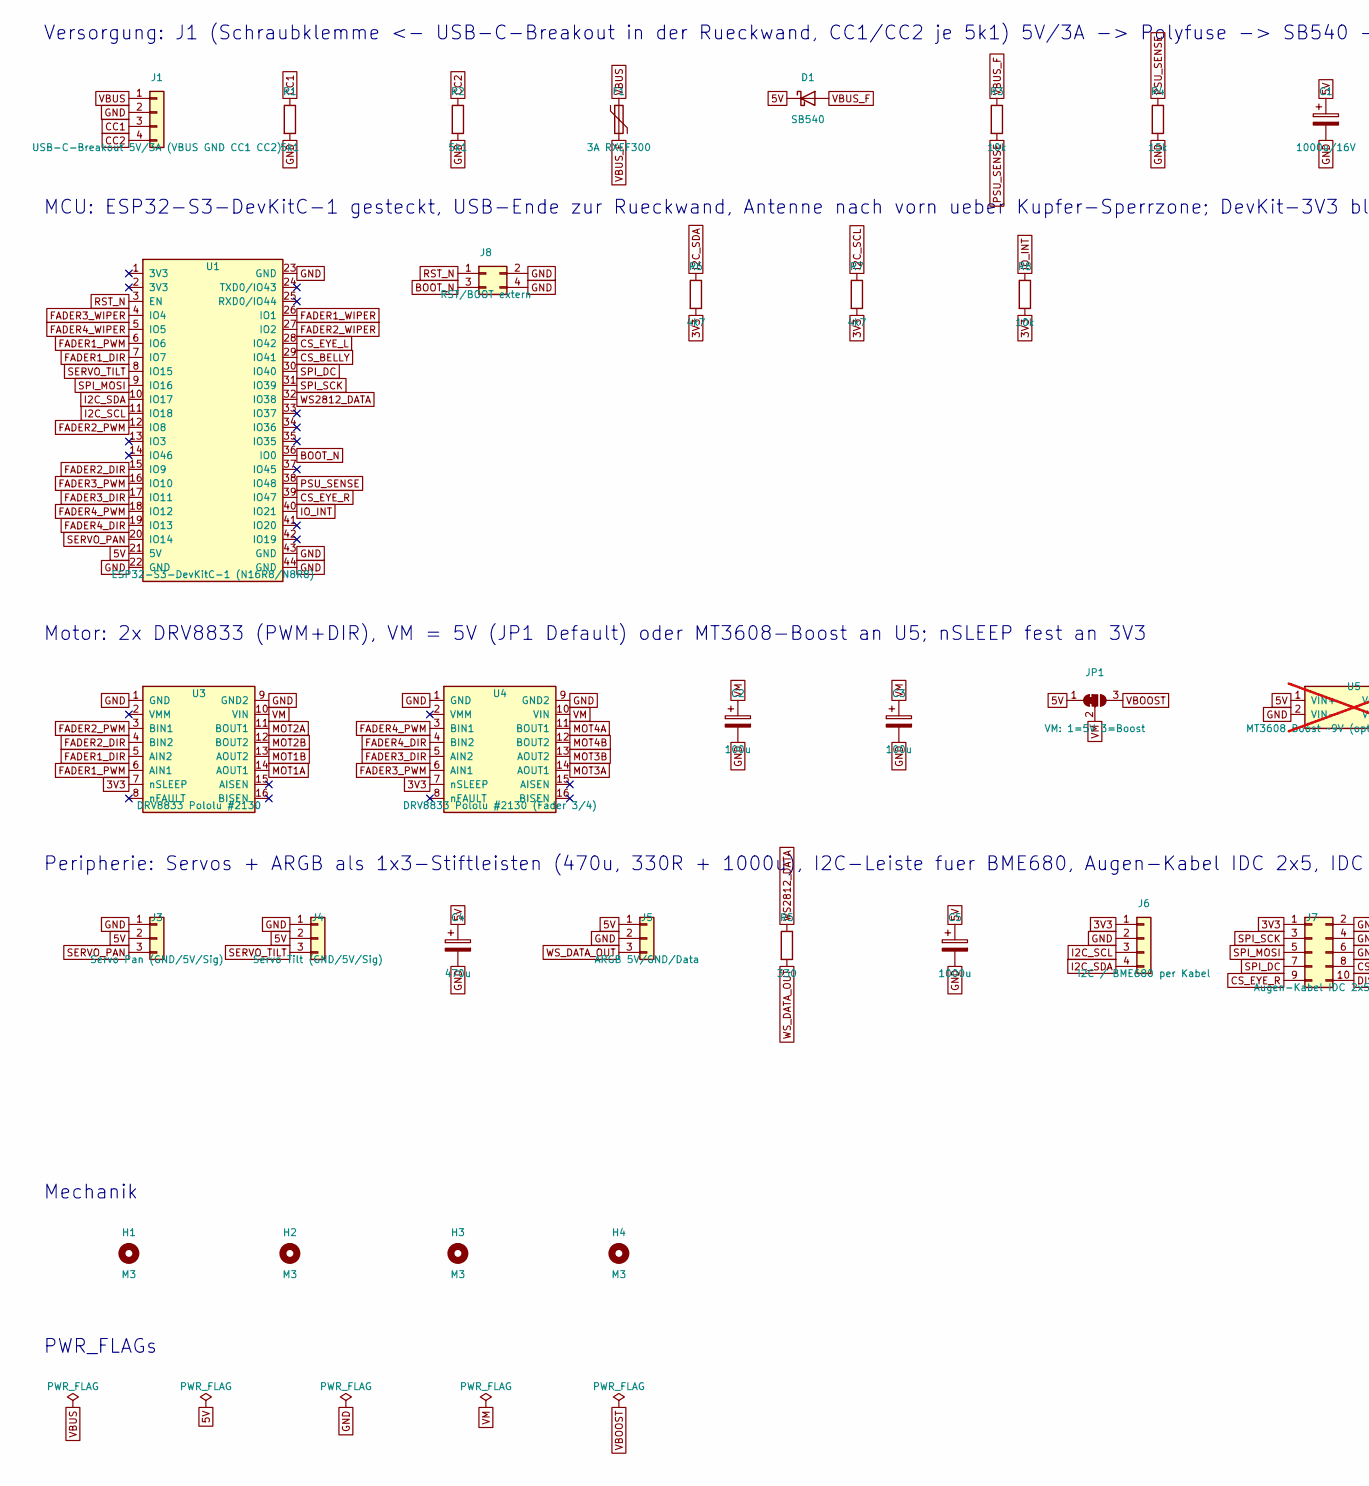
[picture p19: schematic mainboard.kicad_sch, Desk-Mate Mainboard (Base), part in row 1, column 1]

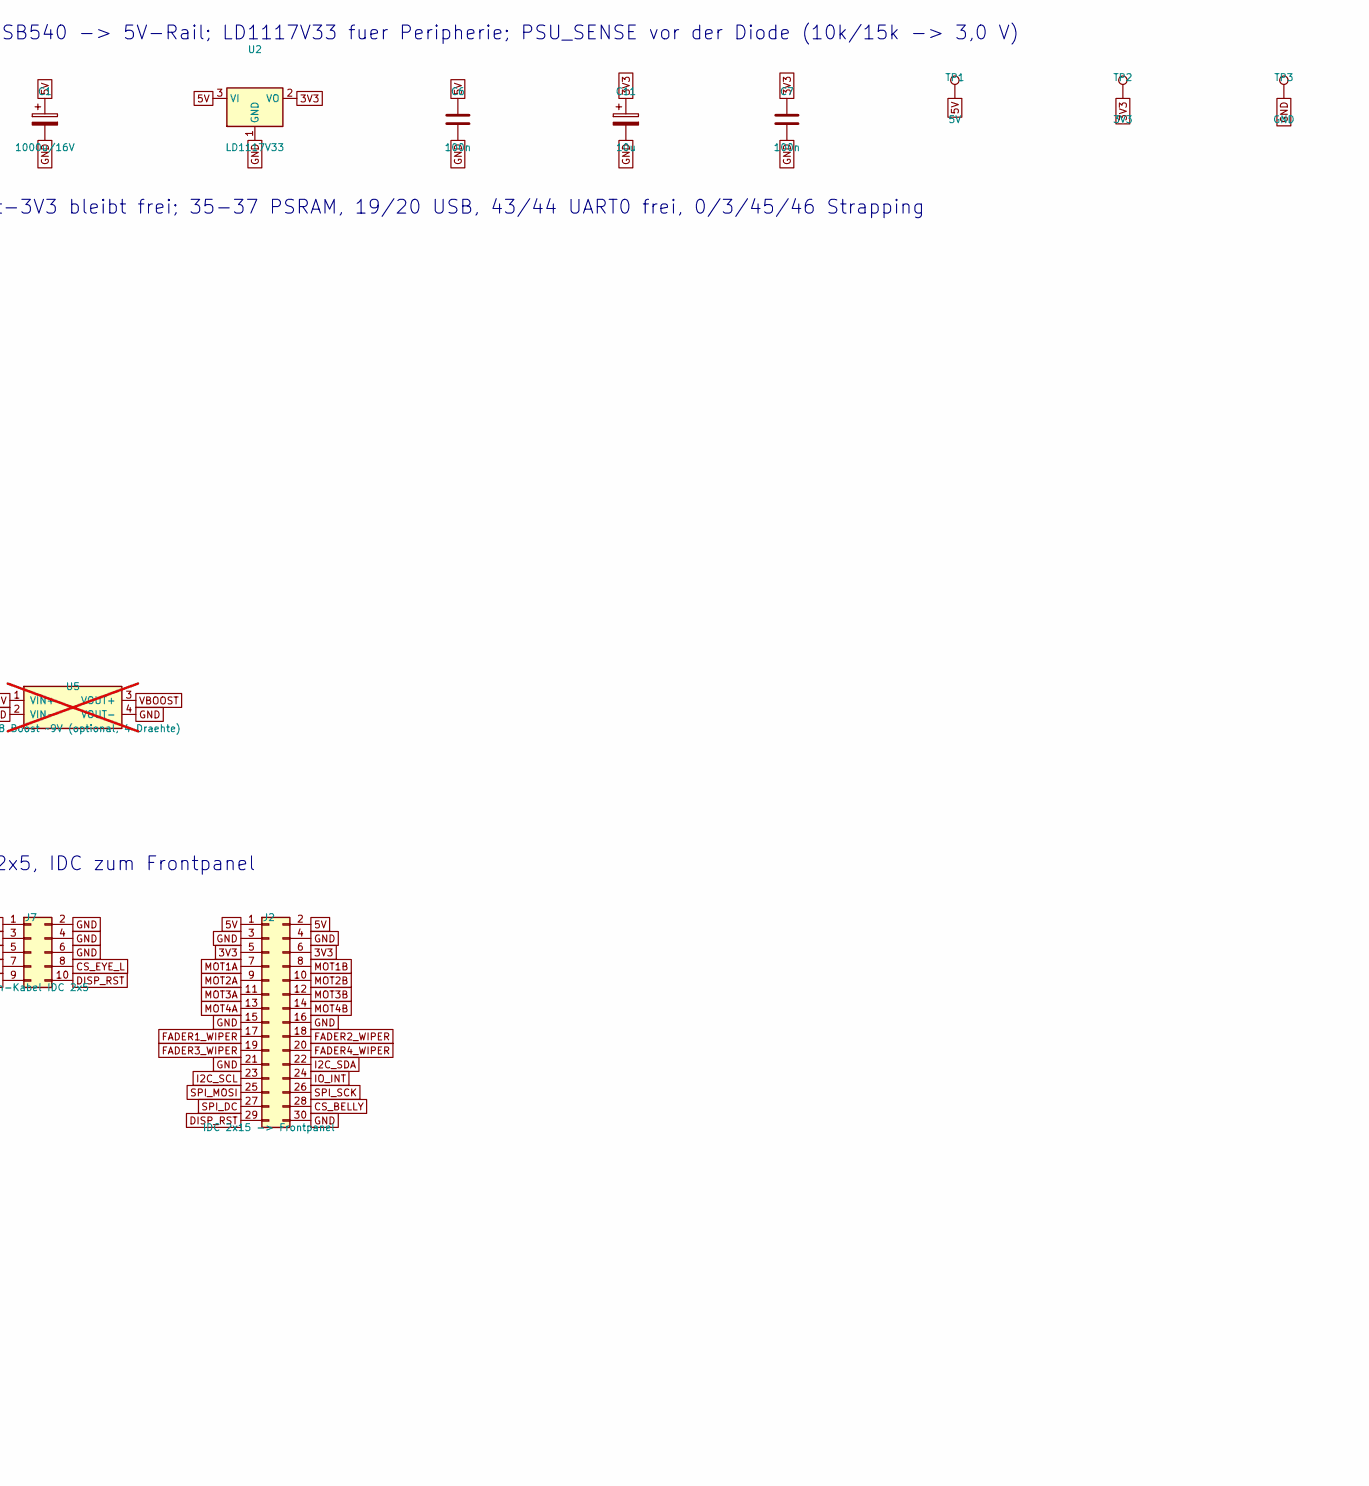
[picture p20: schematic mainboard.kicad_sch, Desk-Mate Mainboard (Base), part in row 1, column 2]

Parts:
C1: 1000u/16V; CP_Radial_D10.0mm_P5.00mm
C2, C3: 100u; CP_Radial_D6.3mm_P2.50mm
C4: 470u; CP_Radial_D8.0mm_P3.50mm
C5: 1000u; CP_Radial_D10.0mm_P5.00mm
C6, C7: 100n; C_Disc_D5.0mm_W2.5mm_P5.00mm
C11: 10u; CP_Radial_D5.0mm_P2.00mm
D1: SB540; D_DO-201_P15.24mm_Horizontal
F1: 3A RXEF300; Polyfuse_Radial_P5.08mm
H1, H2, H3, H4: M3; MountingHole_3.2mm_M3
J1: USB-C-Breakout 5V/3A (VBUS GND CC1 CC2); TerminalBlock_Phoenix_MKDS-1,5-4-5.08_1x04_P5.08mm_Horizont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
J2: IDC 2x15 -> Frontpanel; IDC-Header_2x15_P2.54mm_Vertical
J3: Servo Pan (GND/5V/Sig); PinHeader_1x03_P2.54mm_Vertical
J4: Servo Tilt (GND/5V/Sig); PinHeader_1x03_P2.54mm_Vertical
J5: ARGB 5V/GND/Data; PinHeader_1x03_P2.54mm_Vertical
J6: I2C / BME680 per Kabel; PinHeader_1x04_P2.54mm_Vertical
J7: Augen-Kabel IDC 2x5; IDC-Header_2x05_P2.54mm_Vertical
J8: RST/BOOT extern; PinHeader_2x02_P2.54mm_Vertical
JP1: VM: 1=5V 3=Boost; SolderJumper-3_P1.3mm_Bridged12_RoundedPad1.0x1.5mm_NumberL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
R1, R2: 5k1; R_Axial_DIN0207_L6.3mm_D2.5mm_P10.16mm_Horizontal
R3, R8: 10k; R_Axial_DIN0207_L6.3mm_D2.5mm_P10.16mm_Horizontal
R4: 15k; R_Axial_DIN0207_L6.3mm_D2.5mm_P10.16mm_Horizontal
R5: 330; R_Axial_DIN0207_L6.3mm_D2.5mm_P10.16mm_Horizontal
R6, R7: 4k7; R_Axial_DIN0207_L6.3mm_D2.5mm_P10.16mm_Horizontal
TP1: 5V; TestPoint_THTPad_1.5x1.5mm_Drill0.7mm
TP2: 3V3; TestPoint_THTPad_1.5x1.5mm_Drill0.7mm
TP3: GND; TestPoint_THTPad_1.5x1.5mm_Drill0.7mm
U1: ESP32-S3-DevKitC-1 (N16R8/N8R8); ESP32-S3-DevKitC-1_Socket
U2: LD1117V33; TO-220-3_Vertical
U3: DRV8833 Pololu #2130; DRV8833_Socket
U4: DRV8833 Pololu #2130 (Fader 3/4); DRV8833_Socket
U5: MT3608 Boost ~9V (optional, 4 Draehte); PinHeader_1x04_P2.54mm_Vertical; not fitted

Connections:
3V3: C7.1, C11.1, J2.5, J2.6, J6.1, J7.1, R6.2, R7.2, R8.2, TP2.1, U2.2 (VO), U3.7 (nSLEEP), U4.7 (nSLEEP)
5V: C1.1, C4.1, C5.1, C6.1, D1.1 (K), J2.1, J2.2, J3.2, J4.2, J5.1, JP1.1 (A), TP1.1, U1.21 (5V), U2.3 (VI), U5.1 (VIN+)
BOOT_N: J8.3, U1.36 (IO0)
CC1: J1.3, R1.1
CC2: J1.4, R2.1
CS_BELLY: J2.28, U1.29 (IO41)
CS_EYE_L: J7.8, U1.28 (IO42)
CS_EYE_R: J7.9, U1.39 (IO47)
DISP_RST: J2.29, J7.10
FADER1_DIR: U1.7 (IO7), U3.5 (AIN2)
FADER1_PWM: U1.6 (IO6), U3.6 (AIN1)
FADER1_WIPER: J2.17, U1.26 (IO1)
FADER2_DIR: U1.15 (IO9), U3.4 (BIN2)
FADER2_PWM: U1.12 (IO8), U3.3 (BIN1)
FADER2_WIPER: J2.18, U1.27 (IO2)
FADER3_DIR: U1.17 (IO11), U4.5 (AIN2)
FADER3_PWM: U1.16 (IO10), U4.6 (AIN1)
FADER3_WIPER: J2.19, U1.4 (IO4)
FADER4_DIR: U1.19 (IO13), U4.4 (BIN2)
FADER4_PWM: U1.18 (IO12), U4.3 (BIN1)
FADER4_WIPER: J2.20, U1.5 (IO5)
GND: C1.2, C2.2, C3.2, C4.2, C5.2, C6.2, C7.2, C11.2, J1.2, J2.3, J2.4, J2.15, J2.16, J2.21, J2.30, J3.1, J4.1, J5.2, J6.2, J7.2, J7.4, J7.6, J8.2, J8.4, R1.2, R2.2, R4.2, TP3.1, U1.22 (GND), U1.23 (GND), U1.43 (GND), U1.44 (GND), U2.1 (GND), U3.1 (GND), U3.9 (GND2), U4.1 (GND), U4.9 (GND2), U5.2 (VIN-), U5.4 (VOUT-)
I2C_SCL: J2.23, J6.3, R7.1, U1.11 (IO18)
I2C_SDA: J2.22, J6.4, R6.1, U1.10 (IO17)
IO_INT: J2.24, R8.1, U1.40 (IO21)
MOT1A: J2.7, U3.14 (AOUT1)
MOT1B: J2.8, U3.13 (AOUT2)
MOT2A: J2.9, U3.11 (BOUT1)
MOT2B: J2.10, U3.12 (BOUT2)
MOT3A: J2.11, U4.14 (AOUT1)
MOT3B: J2.12, U4.13 (AOUT2)
MOT4A: J2.13, U4.11 (BOUT1)
MOT4B: J2.14, U4.12 (BOUT2)
PSU_SENSE: R3.2, R4.1, U1.38 (IO48)
RST_N: J8.1, U1.3 (EN)
SERVO_PAN: J3.3, U1.20 (IO14)
SERVO_TILT: J4.3, U1.8 (IO15)
SPI_DC: J2.27, J7.7, U1.30 (IO40)
SPI_MOSI: J2.25, J7.5, U1.9 (IO16)
SPI_SCK: J2.26, J7.3, U1.31 (IO39)
VBOOST: JP1.3 (B), U5.3 (VOUT+)
VBUS: F1.1, J1.1
VBUS_F: D1.2 (A), F1.2, R3.1
VM: C2.1, C3.1, JP1.2 (C), U3.10 (VIN), U4.10 (VIN)
WS2812_DATA: R5.1, U1.32 (IO38)
WS_DATA_OUT: J5.3, R5.2

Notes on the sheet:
Versorgung: J1 (Schraubklemme <- USB-C-Breakout in der Rueckwand, CC1/CC2 je 5k1) 5V/3A -> Polyfuse -> SB540 -> 5V-Rail; LD1117V33 fuer Peripherie; PSU_SENSE vor der Diode (10k/15k -> 3,0 V)
MCU: ESP32-S3-DevKitC-1 gesteckt, USB-Ende zur Rueckwand, Antenne nach vorn ueber Kupfer-Sperrzone; DevKit-3V3 bleibt frei; 35-37 PSRAM, 19/20 USB, 43/44 UART0 frei, 0/3/45/46 Strapping
Motor: 2x DRV8833 (PWM+DIR), VM = 5V (JP1 Default) oder MT3608-Boost an U5; nSLEEP fest an 3V3
Peripherie: Servos + ARGB als 1x3-Stiftleisten (470u, 330R + 1000u), I2C-Leiste fuer BME680, Augen-Kabel IDC 2x5, IDC zum Frontpanel
Mechanik
PWR_FLAGs

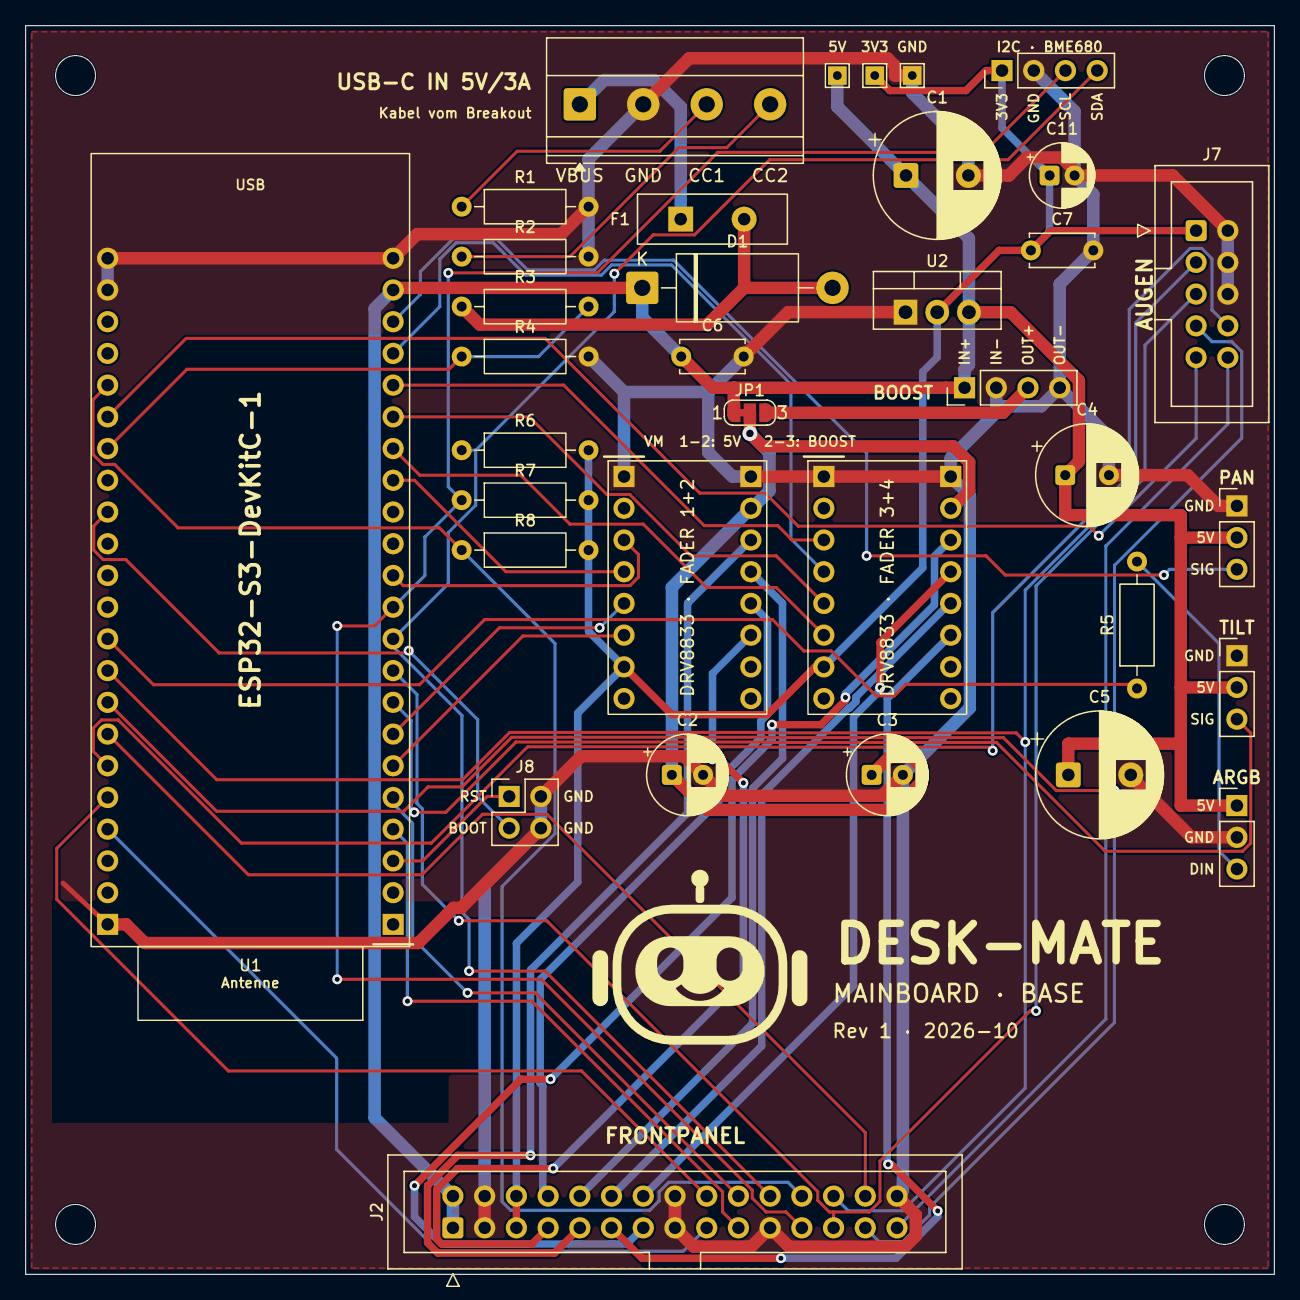
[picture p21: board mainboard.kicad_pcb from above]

Board: 2 copper layers, 100.0 x 100.0 mm, 39 parts (0 on the bottom side), 46 nets.

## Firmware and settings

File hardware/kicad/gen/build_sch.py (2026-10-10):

"""Schritt 1: Bibliothek + Schaltpläne + Projekte + netlist.json je Board.

    python3 build_sch.py            (System-Python reicht; kein pcbnew nötig)
"""
import json
import os
import sys

HERE = os.path.dirname(os.path.abspath(__file__))
sys.path.insert(0, HERE)
ROOT = os.path.dirname(HERE)

from sch import Schematic, symbol_pins, write_custom_lib, write_project
import fp as FP
import boards as B

JLC_RULES = {"min_clearance": 0.127, "min_connection": 0.0, "min_copper_edge_clearance": 0.3, "min_hole_clearance": 0.25,
             "min_hole_to_hole": 0.25, "min_microvia_diameter": 0.2, "min_microvia_drill": 0.1, "min_resolved_spokes": 0,
             "min_silk_clearance": 0.0, "min_text_height": 0.8, "min_text_thickness": 0.08,
             "min_through_hole_diameter": 0.3, "min_track_width": 0.2, "min_via_annular_width": 0.13,
             "min_via_diameter": 0.5, "solder_mask_to_copper_clearance": 0.0, "use_height_for_length_calcs": True}


def netclass(name, width, clearance=0.13):
    return {"bus_width": 12, "clearance": clearance, "diff_pair_gap": 0.25, "diff_pair_via_gap": 0.25,
            "diff_pair_width": 0.2, "line_style": 0, "microvia_diameter": 0.3, "microvia_drill": 0.1, "name": name,
            "pcb_color": "rgba(0, 0, 0, 0.000)", "priority": 2147483647 if name == 'Default' else 0,
            "schematic_color": "rgba(0, 0, 0, 0.000)", "track_width": width, "via_diameter": 0.8 if width < 1 else 1.2,
            "via_drill": 0.4 if width < 1 else 0.6, "wire_width": 6}


def footprints():
    dy = B.DEVKIT_OUTLINE_DY
    ant = [FP._rect(-9, -B.DEVKIT_L / 2 + dy - 5.9, 9, -B.DEVKIT_L / 2 + dy, 'F.Fab', 0.1),
           FP._rect(-9, -B.DEVKIT_L / 2 + dy - 5.9, 9, -B.DEVKIT_L / 2 + dy, 'F.SilkS', 0.12),
           FP._text('user', 'Antenne', 0, -B.DEVKIT_L / 2 + dy - 2.9, 'F.SilkS', 0.8),
           FP._text('user', 'USB', 0, B.DEVKIT_L / 2 + dy - 2.5, 'F.SilkS', 0.8)]
    fps = [
        FP.module_socket('ESP32-S3-DevKitC-1_Socket', (-B.DEVKIT_ROW_SPACING / 2, B.DEVKIT_ROW_SPACING / 2), 22,
                         B.DEVKIT_W, B.DEVKIT_L,
                         'Sockel 2x 1x22 fuer ESP32-S3-DevKitC-1 v1.1 (Pin 1 = Antennenende; J1 = Pads 1-22 links, J3 = 23-44 rechts, Antenne oben)',
                         y_offset=dy, extra=ant),
        FP.module_socket('DRV8833_Socket', (-B.DRV8833_ROW_SPACING / 2, B.DRV8833_ROW_SPACING / 2), 8,
                         B.DRV8833_W, B.DRV8833_L, 'Sockel 2x 1x8 fuer Pololu DRV8833 #2130 (Pad 1 = GND, VMM-Seite links)'),
        FP.two_pad_radial('Polyfuse_Radial_P5.08mm', 5.08, 12.0, 4.0, 'Polyfuse radial, RM 5,08 (RXEF300)'),
    ]
    return fps


def layout_board(board):
    """Schaltplan mit Abschnitten; Symbole fließend auf A2 (594 x 420) platziert."""
    sch = Schematic(board['name'], board['title'], paper='A2')
    for s in B.CUSTOM_SYMBOLS.values():
        sch.add_custom_symbol(s)
    x, y, rowh = 20.0, 30.0, 0.0
    for title, parts in board['sections']:
        x, y = 20.0, y + rowh + 12
        rowh = 0
        sch.text(title, x, y - 4, size=2.5)
        for part in parts:
            ref, lib, sym, value, footprint, nets, pcb = part[:7]
            dnp = part[7] if len(part) > 7 else False
            pins = symbol_pins(sch._symbol(lib, sym))
            xs = [p[3] for p in pins] or [0]
            ys = [p[4] for p in pins] or [0]
            w = (max(xs) - min(xs)) + 30    # Platz für Labels links/rechts
            h = (max(ys) - min(ys)) + 12
            if x + w > 580:
                x, y = 20.0, y + rowh + 6
                rowh = 0
            cx = round((x - min(xs) + 15) / 1.27) * 1.27
            cy = round((y + max(ys) + 6) / 1.27) * 1.27
            sch.add(ref, lib, sym, value, footprint, cx, cy, nets, dnp=dnp, pcb=pcb)
            x += w
            rowh = max(rowh, h)
    y += rowh + 16
    x = 20.0
    sch.text('PWR_FLAGs', x, y - 4, size=2.5)
    for net in board['pwr_flags']:
        sch.pwr_flag(net, x + 5, y + 5)
        x += 25
    return sch


def main():
    libdir = f'{ROOT}/lib'
    os.makedirs(libdir, exist_ok=True)
    write_custom_lib(f'{libdir}/deskmate.kicad_sym', B.CUSTOM_SYMBOLS)
    FP.write_pretty(f'{libdir}/deskmate.pretty', footprints())
    for board in B.BOARDS:
        d = f'{ROOT}/{board["name"]}'
        os.makedirs(d, exist_ok=True)
        sch = layout_board(board)
        with open(f'{d}/{board["name"]}.kicad_sch', 'w', encoding='utf-8') as f:
            f.write(sch.dump())
        classes = [netclass('Default', 0.25)]
        assignments = {}
        for name, (nets, width) in board['netclasses'].items():
            classes.append(netclass(name, width))
            for n in nets:
                assignments[n] = name
        write_project(d, board['name'], JLC_RULES, classes, sch.uuid, board['w'], board['h'])
        # netclass_assignments nachtragen
        pro = json.load(open(f'{d}/{board["name"]}.kicad_pro'))
        pro['net_settings']['netclass_assignments'] = assignments
        json.dump(pro, open(f'{d}/{board["name"]}.kicad_pro', 'w'), indent=2, ensure_ascii=False)
        nl = {'board': board['name'], 'w': board['w'], 'h': board['h'], 'sheet_uuid': sch.uuid,
              'parts': sch.parts, 'nets': sch.nets(), 'netclasses': board['netclasses'], 'keepout': board['keepout'],
              'pre_tracks': board.get('pre_tracks', []), 'silk': board.get('silk', [])}
        json.dump(nl, open(f'{d}/netlist.json', 'w'), indent=1, ensure_ascii=False)
        print(f'{board["name"]}: {len(sch.parts)} Teile, {len(nl["nets"])} Netze')


if __name__ == '__main__':
    main()

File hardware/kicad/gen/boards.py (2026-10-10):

"""Desk-Mate: Schaltung der drei Platinen als Daten (Spec §2.2–2.4, pins.h).

Jedes Teil: (ref, lib, symbol, value, footprint, {pin: netz | None}, pcb={x, y, rot}).
PCB-Koordinaten = Mitte des Courtyards in mm, Ursprung links oben, Y nach unten.
Netznamen = pins.h ohne PIN_. None = No-Connect-Kreuz.
"""
from sch import make_custom_symbol

# ---------------------------------------------------------------- Modul-Maße (Recherche 2026-08-27, siehe vault/Hardware/Module-Masse.md)
DEVKIT_ROW_SPACING = 22.86   # ESP32-S3-DevKitC-1: Abstand der beiden Buchsenreihen
DEVKIT_W, DEVKIT_L = 25.5, 63.5
DRV8833_ROW_SPACING = 10.16  # Pololu #2130: 0,5" breit, Reihen 0,4" auseinander
DRV8833_W, DRV8833_L = 12.7, 20.3
DEVKIT_OUTLINE_DY = 3.30     # Pinfeld sitzt 3,3 mm zum Antennenende hin (Pin 1 = Antennenende, 1,40 mm vom Rand)
# MT3608-Modul: Lochraster nicht 2,54-kompatibel (6,45–6,8 / 30,5–31 mm) -> Modul per 4 Drähten an Stiftleiste (ponytail)

RAX = 'Resistor_THT:R_Axial_DIN0207_L6.3mm_D2.5mm_P10.16mm_Horizontal'
C100N = 'Capacitor_THT:C_Disc_D5.0mm_W2.5mm_P5.00mm'
CP1000 = 'Capacitor_THT:CP_Radial_D10.0mm_P5.00mm'
CP470 = 'Capacitor_THT:CP_Radial_D8.0mm_P3.50mm'
CP100 = 'Capacitor_THT:CP_Radial_D6.3mm_P2.50mm'
CP10 = 'Capacitor_THT:CP_Radial_D5.0mm_P2.00mm'   # Reichelt 10 µF D5 hat RM 2,0
JP2O = ('Jumper', 'SolderJumper_2_Open', 'Jumper:SolderJumper-2_P1.3mm_Open_RoundedPad1.0x1.5mm')
JP2B = ('Jumper', 'SolderJumper_2_Bridged', 'Jumper:SolderJumper-2_P1.3mm_Bridged_RoundedPad1.0x1.5mm')
JP3 = ('Jumper', 'SolderJumper_3_Bridged12', 'Jumper:SolderJumper-3_P1.3mm_Bridged12_RoundedPad1.0x1.5mm_NumberLabels')
HOLE = ('Mechanical', 'MountingHole', 'MountingHole:MountingHole_3.2mm_M3')
TP = ('Connector', 'TestPoint', 'TestPoint:TestPoint_THTPad_1.5x1.5mm_Drill0.7mm')
MKDS4 = 'TerminalBlock_Phoenix:TerminalBlock_Phoenix_MKDS-1,5-4-5.08_1x04_P5.08mm_Horizontal'   # Reichelt MKDS 1,5 4 5,08
SOCK = 'Connector_PinSocket_2.54mm:PinSocket_1x%02d_P2.54mm_Vertical'
HDR = 'Connector_PinHeader_2.54mm:PinHeader_1x%02d_P2.54mm_Vertical'
IDC = 'Connector_IDC:IDC-Header_2x15_P2.54mm_Vertical'
IDC10 = 'Connector_IDC:IDC-Header_2x05_P2.54mm_Vertical'

# ---------------------------------------------------------------- eigene Symbole
DEVKIT_J1 = ['3V3', '3V3', 'EN', 'IO4', 'IO5', 'IO6', 'IO7', 'IO15', 'IO16', 'IO17', 'IO18', 'IO8', 'IO3', 'IO46',
             'IO9', 'IO10', 'IO11', 'IO12', 'IO13', 'IO14', '5V', 'GND']
DEVKIT_J3 = ['GND', 'TXD0/IO43', 'RXD0/IO44', 'IO1', 'IO2', 'IO42', 'IO41', 'IO40', 'IO39', 'IO38', 'IO37', 'IO36',
             'IO35', 'IO0', 'IO45', 'IO48', 'IO47', 'IO21', 'IO20', 'IO19', 'GND', 'GND']
DEVKIT_PINS = [(str(i + 1), n, 'L', i, 'power_in' if n in ('5V',) else 'passive' if n in ('3V3', 'GND') else 'bidirectional')
               for i, n in enumerate(DEVKIT_J1)] + \
              [(str(i + 23), n, 'R', i, 'passive' if n == 'GND' else 'bidirectional') for i, n in enumerate(DEVKIT_J3)]

# Pololu DRV8833 (#2130), Draufsicht, GND-Ende oben: links 1–8, rechts 9–16 (Pololu-Pinout-Bild 0J3866)
DRV8833_ROW1 = ['GND', 'VMM', 'BIN1', 'BIN2', 'AIN2', 'AIN1', 'nSLEEP', 'nFAULT']
DRV8833_ROW2 = ['GND2', 'VIN', 'BOUT1', 'BOUT2', 'AOUT2', 'AOUT1', 'AISEN', 'BISEN']
DRV8833_PINS = [(str(i + 1), n, 'L', i, 'passive') for i, n in enumerate(DRV8833_ROW1)] + \
               [(str(i + 9), n, 'R', i, 'passive') for i, n in enumerate(DRV8833_ROW2)]

MT3608_PINS = [('1', 'VIN+', 'L', 0, 'passive'), ('2', 'VIN-', 'L', 1, 'passive'),
               ('3', 'VOUT+', 'R', 0, 'passive'), ('4', 'VOUT-', 'R', 1, 'passive')]

CUSTOM_SYMBOLS = {
    'ESP32-S3-DevKitC-1': make_custom_symbol('ESP32-S3-DevKitC-1', DEVKIT_PINS, width=25.4, ref_prefix='U',
                                             desc='Espressif ESP32-S3-DevKitC-1 N16R8, gesteckt (2x 1x22 Buchsenleiste)'),
    'DRV8833_Breakout': make_custom_symbol('DRV8833_Breakout', DRV8833_PINS, width=20.32, ref_prefix='U',
                                           desc='Pololu DRV8833 Dual Motor Driver Carrier #2130 (Sockel 2x 1x8)'),
    'MT3608_Module': make_custom_symbol('MT3608_Module', MT3608_PINS, width=17.78, ref_prefix='U',
                                        desc='MT3608 Step-up-Modul, VM-Boost (optional)'),
}
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

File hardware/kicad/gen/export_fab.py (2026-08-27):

"""Schritt 3: Fertigungsdaten je Board nach <board>/fab/ (Gerber+Drill-Zip fuer JLCPCB, STEP, Render, SVG-Schaltplan).

    python3 export_fab.py mainboard   (System-Python; ruft kicad-cli)
"""
import os
import shutil
import subprocess
import sys
import zipfile

HERE = os.path.dirname(os.path.abspath(__file__))
ROOT = os.path.dirname(HERE)
K = '/Applications/KiCad/KiCad.app/Contents/MacOS/kicad-cli'


def run(*args):
    r = subprocess.run([K] + list(args), capture_output=True, text=True)
    if r.returncode != 0:
        print(r.stdout[-800:], r.stderr[-800:])
        raise SystemExit(f'kicad-cli fehlgeschlagen: {args[:3]}')


def export(name):
    d = f'{ROOT}/{name}'
    pcb = f'{d}/{name}.kicad_pcb'
    fab = f'{d}/fab'
    tmp = f'{fab}/gerber'
    os.makedirs(fab, exist_ok=True)
    shutil.rmtree(tmp, ignore_errors=True)
    os.makedirs(tmp)
    # JLCPCB-Vorgaben: Protel-Endungen, keine X2, Umriss auf Edge.Cuts, Bohrdaten Excellon mit Map
    run('pcb', 'export', 'gerbers', '--layers', 'F.Cu,B.Cu,F.Paste,B.Paste,F.SilkS,B.SilkS,F.Mask,B.Mask,Edge.Cuts',
        '--no-x2', '--use-drill-file-origin', '--subtract-soldermask', '-o', tmp + '/', pcb)
    run('pcb', 'export', 'drill', '--format', 'excellon', '--drill-origin', 'absolute', '--excellon-separate-th',
        '--generate-map', '--map-format', 'gerberx2', '-o', tmp + '/', pcb)
    zpath = f'{fab}/{name}-gerber.zip'
    with zipfile.ZipFile(zpath, 'w', zipfile.ZIP_DEFLATED) as z:
        for f in sorted(os.listdir(tmp)):
            z.write(f'{tmp}/{f}', f)
    shutil.rmtree(tmp)
    run('pcb', 'export', 'step', '--subst-models', '--no-dnp', '-o', f'{fab}/{name}.step', pcb)
    run('pcb', 'render', '--side', 'top', '-w', '1600', '-h', '1600', '--quality', 'high', '-o', f'{fab}/{name}-top.png', pcb)
    run('pcb', 'render', '--side', 'bottom', '-w', '1600', '-h', '1600', '-o', f'{fab}/{name}-bottom.png', pcb)
    run('sch', 'export', 'pdf', '-o', f'{fab}/{name}-schaltplan.pdf', f'{d}/{name}.kicad_sch')
    print(f'{name}: {os.path.getsize(zpath) // 1024} KB Gerber-Zip, STEP, Render, Schaltplan-PDF -> {fab}/')


if __name__ == '__main__':
    export(sys.argv[1])

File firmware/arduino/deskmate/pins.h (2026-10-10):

// Desk-Mate — verifizierte Pin-Map (2026-08-23; GPIO45 gestrichen 2026-10-04). Quellen: vault/Hardware/Pin-Map.md, Spec §2.3.
// Board: ESP32-S3-DevKitC-1 (WROOM-1-N16R8). Aenderungen nur mit Spec-Update.
#pragma once

// Fader (Schleifer zwingend ADC1 = GPIO1-10; ADC2 ist mit WiFi unbrauchbar)
constexpr int PIN_FADER1_WIPER = 1;   // ADC1_CH0, RC-Filter auf Frontpanel
constexpr int PIN_FADER2_WIPER = 2;   // ADC1_CH1
constexpr int PIN_FADER3_WIPER = 4;   // ADC1_CH3, Reserve (DNP)
constexpr int PIN_FADER4_WIPER = 5;   // ADC1_CH4, Reserve (DNP)
constexpr int PIN_FADER1_PWM = 6;     // LEDC 20 kHz -> DRV8833 A-IN1
constexpr int PIN_FADER1_DIR = 7;     // GPIO -> DRV8833 A-IN2
constexpr int PIN_FADER2_PWM = 8;     // LEDC -> DRV8833 B-IN1
constexpr int PIN_FADER2_DIR = 9;     // GPIO -> DRV8833 B-IN2
constexpr int PIN_FADER3_PWM = 10;    // Reserve
constexpr int PIN_FADER3_DIR = 11;    // Reserve
constexpr int PIN_FADER4_PWM = 12;    // Reserve
constexpr int PIN_FADER4_DIR = 13;    // Reserve

// Kopf
constexpr int PIN_SERVO_PAN = 14;     // LEDC 50 Hz
constexpr int PIN_SERVO_TILT = 15;    // LEDC 50 Hz
constexpr int PIN_WS2812_DATA = 38;   // RMT, Mund/Ampel; DevKit v1.1: Onboard-LED spiegelt Pixel 0 (gewollt)

// Displays (ein SPI-Bus, drei Panels)
constexpr int PIN_SPI_MOSI = 16;
constexpr int PIN_SPI_SCK = 39;       // JTAG-Default; frei, da USB-Serial-JTAG (eFuse-Default)
constexpr int PIN_SPI_DC = 40;
constexpr int PIN_CS_BELLY = 41;
constexpr int PIN_CS_EYE_L = 42;
constexpr int PIN_CS_EYE_R = 47;
// Backlight on/off und DISP_RST aller drei Displays laufen ueber den MCP23017 (GPB6 / GPB5), kein S3-Pin.

// I2C (MCP23017 0x20, MPR121 0x5A, BME680 0x76/0x77)
constexpr int PIN_I2C_SDA = 17;
constexpr int PIN_I2C_SCL = 18;
constexpr int PIN_IO_INT = 21;        // MCP23017-INT + MPR121-IRQ, wired-OR (Open-Drain, Pull-up)

// Versorgung
constexpr int PIN_PSU_SENSE = 48;     // Teiler an J1-VBUS (vor der SB540); DevKit v1.0: Onboard-LED haengt hier (unkritisch)

// Tabu: 0, 3, 45, 46 (Strapping; 45 = VDD_SPI), 19/20 (USB), 26-34 (Flash), 35-37 (Octal-PSRAM, unverbunden lassen), 43/44 (UART0/CP2102N)

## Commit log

2026-08-22 Secret-Check als Pre-Commit-Hook, Zeiterfassung und Auto-Push ueber Session-Hooks, mit Tests
2026-08-22 Session 2026-08-22 23:21: Projektstart: Grilling (18 Fragen), Design-Spec, Plan Phase 0–2, Repo-Infrastruktur mit Hooks, Vault, Logo, erster Push
2026-08-23 Design-Richtung nach Referenzbild: Visier-Look, Mund-LED als Ampel, Panel angewinkelt; Logo v2
2026-08-23 Pin-Map verifiziert (Datenblatt + DevKitC-1-Schaltplan): pins.h mit Test, VM-Boost-Reserve fuer MF60T, generischer ARGB-Anschluss
2026-08-23 USB-Datenpfad und Versorgung vereinfacht: Panel-Mount-Verlaengerung, Polyfuse + SB540 statt P-FET-ODER
2026-08-23 Stueckliste mit Quellen und Preisen (~160 EUR EU / ~105 EUR Budget-Mix); MF60T-Beschaffungsrisiko dokumentiert
2026-08-23 Session 2026-08-23 22:33: Referenzbild von Leon: weißer Roboter, dunkles Visier über beiden Augen, Panel angewinkelt → Spec §2.1/§2.6 aktualisiert, Bild in docs/design/
2026-08-23 Fader-Entscheidung: Behringer X32 100-mm-Set panel-mounted statt MF60T; Spec, BOM und Bestellnotiz nachgezogen
2026-08-24 Bestellung 24.08.: GC9A01 2er-Pack 10,07 und ILI9341 14,11 (Amazon) erfasst
2026-08-24 Bestellung 24.08.: Switches 7,04 + Keycaps 10,04; Hot-Swap-Sockel gestrichen (SMD) - Switches direkt THT
2026-08-27 KiCad-Erstversion aller drei Platinen: Generator, ERC/DRC sauber, Fab-Export fuer JLCPCB
    Mainboard 100x100, Frontpanel 120x136, Augen-Adapter 42x30 aus hardware/kicad/gen erzeugt
    (Bauteil -> Pin -> Netz -> Position), Freerouting headless, Netzlisten-Abgleich in tools/test-kicad.sh.
    Modul-Masse mit Quellen in vault/Hardware/Module-Masse.md, Entscheidungen in
    vault/Entscheidungen/2026-08-27-kicad-generator.md, Fallen 13-17 in CLAUDE.md.
    [eye-adapter.kicad_pcb, eye-adapter.kicad_sch, eye-adapter.step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]
2026-08-31 Session 2026-08-31 12:22: Arbeitsstand
    [mainboard.kicad_pcb]
2026-10-03 Session 2026-10-03 00:27: Reserve raus (Stepper, C3, GPIO45, 7 Loetjumper), alle drei Platinen neu geroutet; Push und Falle 18 behoben
    [eye-adapter.kicad_pcb, eye-adapter.kicad_sch, eye-adapter.step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]
2026-10-10 Session 2026-10-09 11:37: Platinen finalisiert: Teile von Reichelt, Silkscreen mit Logo und Pin-Namen, alle drei Boards neu geroutet
    [eye-adapter.kicad_pcb, eye-adapter.kicad_sch, eye-adapter.step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]
